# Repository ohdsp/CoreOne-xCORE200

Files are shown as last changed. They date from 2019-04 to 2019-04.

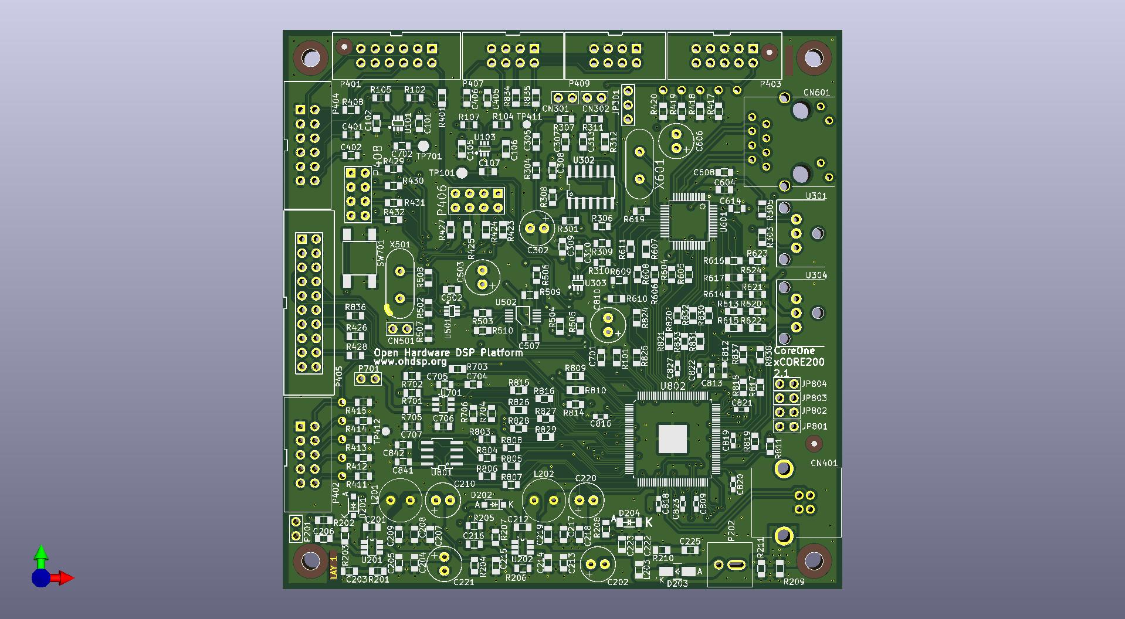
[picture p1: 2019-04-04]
JPEGs/CoreOne-xCORE200-2.1-top.jpg

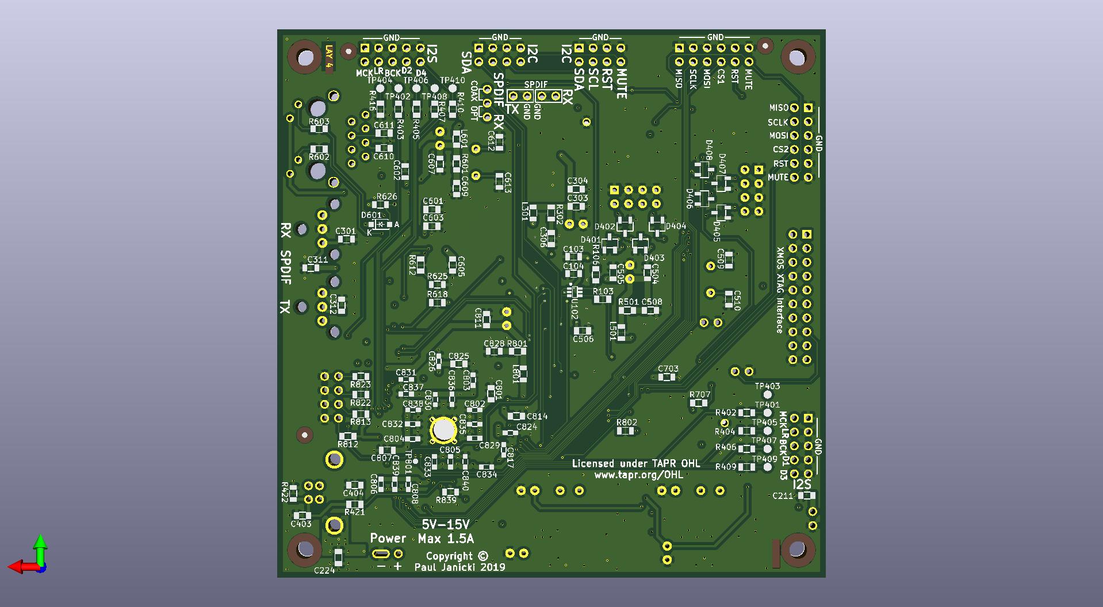
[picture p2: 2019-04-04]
JPEGs/CoreOne-xCORE200-2.1-bottom.jpg

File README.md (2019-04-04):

# [Open Hardware DSP Platform](http://www.ohdsp.org)
## CoreOne-xCORE200
### Revision 2.1

---
# README
### Disclaimer
Copyright Paul Janicki 2019

Licensed under the TAPR Open Hardware License (www.tapr.org/OHL)

This documentation is distributed WITHOUT ANY EXPRESS OR IMPLIED WARRANTY, INCLUDING OF MERCHANTABILITY, SATISFACTORY QUALITY AND FITNESS FOR A PARTICULAR PURPOSE.

### What is this repository?

**Quick summary**

This is Open Hardware DSP Platform CoreOne-xCORE200 Module Revision 2.0. 

This is a less cramped XMOS 200 based DSP and mirocontroller PCB design with USB, SPDIF, I2S/TDM, SPI, I2C, and Ethernet connectivity options.

This repository contains the KiCad design files, manufacturing Gerber/drill files, PDF/drawing files, and relevant documenation for this board.

**Changelog**
Revision 2.1 has the following changes over Revision 2.0:
Added better grounding on power connector only, added extra vias.

Revision 2.0 has the following changes over Revision 1.0:
The ST1S40 regualtors have been replaced with RT7285C parts
The CS2100 clock generator has been removed
The TPS3808 reset circut has been replaced with an NCP308 part
There are now components on the bottom layer to reduce cramping
Third I2S connector removed
Added second I2C and second SPI connectors

### What is the project folder structure?
Most folder names are self explanatory. Starting from the top level: \
*CoreOne*
+ *Bill of Materials*  - This contains the bill of materials in CVS, LibreOffice Calc and XML formats
+ *Drawings* - This contains PDF and SVG Schematic and PCB files
+ *Gerbers* - This contains the PCB Gerbers and drill drawings for manufacture, there is also a zip file ready to send to most manufacturers
+ *JPEGs* - JPEGs of top and bottom views from 3D viewer
+ *KiCad* - This contains the original KiCad schematic and PCB design files
+ *Pick and Place* - This contains pick and place files for top and bottom sides
### How do I get set up?

**Summary of set up**

1. Set your self up a directory on a local disk, something simple will make life easier (eg C:\Electronics on Windows as used here), but anywhere will do just fine.
2. Download the Kicad-Libs from [https://github.com/ohdsp/KiCad-Libs](https://github.com/ohdsp/KiCad-Libs) and place in C:\Electronics\Kicad-Libs (or your chosen folder) 
3. Create a OHDSP subdirectory in C:\Electronics (so C:\Electronics\OHDSP)
3. Download this project to C:\Electronics\OHDSP\uDSP
4. Fire up Kicad
5. Open the main project file C:\Electronics\OHDSP\uDSP\KiCad\uDSP.pro
7. Do as you wish with the project, just keep it under the TAPR Open Hardware License.
Note: For library issues see below.

Make sure your git setup doesn't exclude files used in the project (like .LIB files) or things may go wrong down the line.

**KiCad Library Configuration**

Note that libraries are setup using relative paths, if you follow the above instructions things should work just fine. Below is the default library setup.

To setup eeschema component libraries:
From KiCad main window go to menu Tools -> Edit Schematic Symbols. In the new Window go to menu Preferences -> Manage Symbol Libraries.

On the new "Symbol Libraries" window select the "Project Specific Libraries" tab. The "Append Library" and "Remove Library" buttons can be used to add/remove enteries.
The standard setup is:

| | Active | Nickname | Library Path | Plugin Type | Options | Description |
|---|---|---|---|---|---|---|
| 1 | Ticked | power | ${KICAD_SYMBOL_DIR}/power.lib | Legacy | (blank) | (blank) |
| 2 | Ticked | MyKiCadLibs-Lib | ${KIPRJMOD}/../../../KiCad-Libs/MyKiCadLibs-Lib.lib | Legacy | (blank) | (blank) |

${KICAD_SYMBOL_DIR}  is set under the Enviromnet Variable Configuration. Close Symbol Libraries dialogue and go "Preferences" -> "Configure Paths..."

${KICAD_SYMBOL_DIR} is set to C:\Program Files\KiCad\share\kicad\library - this is the default for a KiCad install on the C drive

${KIPRJMOD} is automatically set to the location of the project (.pro file), in this example this would be C:\Electronics\OHDSP\uDSP\KiCad

To setup Pcbnew libraries:
From KiCad main window go to menu Tools -> Edit PCB Footprints. In the new Window go to menu Preferences -> Manage Symbol Libraries.

On the new "Symbol Libraries" window select the "Project Specific Libraries" tab. The "Append Library" and "Remove Library" buttons can be used to add/remove enteries.
The standard setup is:

| | Active | Nickname | Library Path | Plugin Type | Options | Description |
|---|---|---|---|---|---|---|
| 1 | Ticked | MyKiCadLibs-Footprints | ${KIPRJMOD}/../../../KiCad-Libs/MyKiCadLibs-Footprints.pretty | KiCad | (blank) | (blank) |

${KIPRJMOD} is automatically set to the location of the project (.pro file), in this example this would be C:\Electronics\OHDSP\uDSP\KiCad

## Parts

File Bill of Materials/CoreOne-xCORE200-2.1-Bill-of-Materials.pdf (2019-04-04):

CoreOne-xCORE200-2.1-Bill-of-Materials

Licensed under the TAPR Open Hardware License (www.tapr.org/OHL)

### CoreOne-xCORE200-2.1 Bill of Materials 04 April 2019

Reference | Quantity | Footprint | Value | Description | Size | Tolerance | Type | Voltage | Power | Current
C101 C103 C105 C307 C309 C311 C506 C614 C703 C842 | 10 SMD-0805 | | 10u | 'Ceramic capacitor | '0805 | '20% | 'X5R | '10V | ' | '
C102 C104 C106 C201 C203 C205 C209 C211 C212 C214 C219 C223 C224 C301 C304 C305 C308 C310 C312 C313 C404 C502 C505 C507 C603 C604 C605 C608 C610 C611 C704 C841 | 32 SMD-0805 | | 100n | 'Ceramic capacitor | '0805 | '10% | 'X7R | '50V | ' | '
C107 C215 C401 C402 C405 C406 C701 C702 C705 C706 C707 | 11 SMD-0805 | | 10n | 'Ceramic capacitor | '0805 | '10% | 'X7R | '50V | ' | '
C202 C221 | 2 CAP-TH-D6.3mmP2.5mm | | 220u | 'Aluminium electrolytic capacitor | ' | ' | '2.5mm pitch, 6.3mm diameter | '16V | ' | '
C206 | 1 SMD-0805 | | 39p | 'Ceramic capacitor | '0805 | '10% | 'X7R | '50V | ' | '
C207 C208 C217 C218 C303 C504 C607 C801 C807 C811 C814 C825 | 12 SMD-0805 | | 22u | 'Ceramic capacitor | '0805 | '20% | 'X5R | '10V | ' | '
C210 C220 C302 C503 C606 C810 | 6 CAP-TH-D6.3mmP2.5mm | | 220u | 'Low impedance aluminium electrolytic capacitor - Panasonic FC, FR or similar | ' | ' | '2.5mm pitch, 6.3mm diameter | '10V | ' | '
C216 | 1 SMD-0805 | | N/F | 'Ceramic capacitor | '0805 | '10% | 'X7R | '50V | ' | '
C204 C213 C222 | 3 SMD-0805 | | 22u | 'Ceramic capacitor | '0805 | '20% | 'X5R | '25V | ' | '
C225 C306 C508 C609 C828 | 5 SMD-0805 | | 100p | 'Ceramic capacitor | '0805 | '5% | 'C0G | '50V | ' | '
C403 | 1 SMD-0805 | | 2u2 | 'Ceramic capacitor | '0805 | '10% | 'X5R | '50V | ' | '
C509 C510 C612 C613 | 4 SMD-0805 | | 33p | 'Ceramic capacitor | '0805 | '5% | 'NP0 | '50V | ' | '
C601 C602 | 2 SMD-0805 | | 1u | 'Ceramic capacitor | '0805 | '10% | 'X7R | '10V | ' | '
C802 C803 C804 C805 C806 | 5 SMD-0603 | | 1u | 'Ceramic capacitor | '0603 | '10% | 'X7R | '10V | ' | '
C808 C812 C816 C817 C818 C819 C820 C821 C822 C823 C824 C826 C829 C830 C831 C832 C833 C834 | 18 SMD-0603 | | 100n | 'Ceramic capacitor | '0603 | '10% | 'X7R | '50V | ' | '
C809 C813 C827 C835 C836 C837 C838 C839 C840 | 9 SMD-0603 | | 10n | 'Ceramic capacitor | '0603 | '10% | 'X7R | '50V | ' | '
CN301 CN302 CN501 | 3 CONN_SIL_2_1MM | | COAX | '1x2 2.54mm pitch pin header - use with 75Ohm coax | ' | ' | ' | ' | ' | '
CN401 | 1 CONN-USB-B-61729-0010 | | CONN-USB-B-61729'USB B Connector - Amphenol 61729 Series - eg: 61729-0010 | | ' | ' | ' | ' | ' | '
CN601 | 1 CONN-RJ45-ARJC02-111xxxx | | ARJC02-111009D | 'ARCJ02 series RJ45 connector with LED - ARJC02-111009D | ' | ' | ' | ' | ' | '
D201 D202 D601 | 3 DIODE-SOD-123 | | 1N4148W-7-F | 'Text description | ' | ' | ' | ' | ' | '
D203 | 1 DIODE-SMA | | B240A | 'B240A 2A 40V Schottky Rectifier - SMA (DO-214AC) | ' | ' | ' | ' | ' | '
D204 | 1 SMD-1206 | | Green LED 1206 | 'Green LED - SMD - Vf 1.8V to 2.2V | '1206 | ' | ' | ' | ' | '
D401 D402 D403 D404 D405 D406 D407 D408 | 8 IC-SOT23 | | BAV99 | '100V 150mA Small Signal Switching Diode, Dual in Series | ' | ' | ' | ' | ' | '
JP301 | 1 CONN_SIL_3_1MM | | CONN_3x1 | '1x3 2.54mm pitch pin header | ' | ' | ' | ' | ' | '
L201 | 1 IND-TH-DR0608 | | DR0608-153L | 'Coilcraft DR0608-153L DCR=0.052Ohm Isat=2.7A Irms=2.7A | ' | ' | ' | ' | ' | '2.7A
L202 | 1 IND-TH-DR0608 | | DR0608-332L | 'Coilcraft DR0608-332L DCR=0.012Ohm Isat=5.3A Irms=5.0A | ' | ' | ' | ' | ' | '5.3A
L203 | 1 SMD-0805 | | 600R@100MHz | 'Ferrite bead, current rating 2A or higher, 600R@100MHz | '0805 | ' | ' | ' | ' | '=>2A
L301 L501 L601 L801 | 4 SMD-0805 | | 600R@100MHz | 'Ferrite bead, current rating 1A or higher, 600R@100MHz | '0805 | ' | ' | ' | ' | '=>1A
JP801 JP802 JP803 JP804 P201 P701 | 6 CONN_SIL_2_1MM | | CONN_2x1 | '1x2 2.54mm pitch pin header | ' | ' | ' | ' | ' | '
P202 | 1 CONN-2WAY-2.54mm-3.81mm-SPACING | | CONN_2x1 | '2 way screw terminal, any 2.54mm to 3.81mm pitch part | ' | ' | ' | ' | ' | '
P401 P404 | 2 CONN_DIL_2X6_BOX_1MM | | CONN_02X06 | '2x6 2.54mm pitch box header | ' | ' | ' | ' | ' | '
P402 P403 | 2 CONN_DIL_2X5_BOX_1MM | | CONN_02X05 | '2x5 2.54mm pitch box header | ' | ' | ' | ' | ' | '
P405 | 1 CONN_DIL_2X10_BOX_1MM | | CONN_02X10 | '2x10 2.54mm pitch box header | ' | ' | ' | ' | ' | '
P406 P408 | 2 CONN_DIL_2X04 | | CONN_02X04 | '2x4 2.54mm pitch pin header | ' | ' | ' | ' | ' | '
P407 P409 | 2 CONN_DIL_2X4_BOX_1MM | | CONN_02X04 | '2x4 2.54mm pitch box header | ' | ' | ' | ' | ' | '
R101 R401 R402 R403 R404 R405 R406 R407 R408 R409 R410 R426 R428 R803 R804 R805 R806 R807 R808 R809 R810 R814 R817 R818 R824 R825 | 26 SMD-0805 | | 0 | 'Thick or thin film resistor | '0805 | '1% | ' | ' | '100mW | '
R102 R103 R104 R105 R106 R107 R604 R605 R606 R607 R608 R611 R612 R811 R815 R816 R819 R820 R821 R826 R827 R828 R829 R830 R831 R832 R833 R836 | 28 SMD-0805 | | 33 | 'Thick or thin film resistor | '0805 | '1% | ' | ' | '100mW | '
R201 R202 R206 | 3 SMD-0805 | | 100k | 'Thick or thin film resistor | '0805 | '1% | ' | ' | '100mW | '
R203 | 1 SMD-0805 | | 22k | 'Thick or thin film resistor | '0805 | '1% | ' | ' | '100mW | '
R204 | 1 SMD-0805 | | 75k | 'Thick or thin film resistor | '0805 | '1% | ' | ' | '100mW | '
R205 R301 R303 R308 R421 R626 R802 | 7 SMD-0805 | | 10k | 'Thick or thin film resistor | '0805 | '1% | ' | ' | '100mW | '
R207 R704 | 2 SMD-0805 | | 15k | 'Thick or thin film resistor | '0805 | '1% | ' | ' | '100mW | '
R208 R602 R603 | 3 SMD-0805 | | 220 | 'Thick or thin film resistor | '0805 | '1% | ' | ' | '100mW | '
R209 R211 | 2 SMD-0805 | | 10 | 'Thick or thin film resistor | '0805 | '1% | ' | ' | '100mW | '
R210 R302 R501 R601 R801 | 5 SMD-0805 | | 47 | 'Thick or thin film resistor | '0805 | '1% | ' | ' | '100mW | '
R304 R702 R703 R705 | 4 SMD-0805 | | 100 | 'Thick or thin film resistor | '0805 | '1% | ' | ' | '100mW | '
R305 R306 R307 R309 R310 | 5 SMD-0805 | | 75 | 'Thick or thin film resistor | '0805 | '1% | ' | ' | '100mW | '
R311 | 1 SMD-0805 | | 360 | 'Thick or thin film resistor | '0805 | '1% | ' | ' | '100mW | '
R312 | 1 SMD-0805 | | 91 | 'Thick or thin film resistor | '0805 | '1% | ' | ' | '100mW | '
R411 R412 R413 R414 R415 R416 R417 R418 R419 R420 R502 R506 R507 R613 R614 R615 R623 R624 R625 R834 R835 | 21 SMD-0805 | | N/F | 'Thick or thin film resistor | '0805 | '1% | ' | ' | '100mW | '
R422 | 1 SMD-0805 | | 47k | 'Thick or thin film resistor | '0805 | '1% | ' | ' | '100mW | '
R423 R424 R425 R427 R429 R430 R431 R432 R510 R609 R610 R618 R620 R621 R622 R812 R813 R822 R823 | 19 SMD-0805 | | 1k | 'Thick or thin film resistor | '0805 | '1% | ' | ' | '100mW | '
R503 R504 R505 | 3 SMD-0805 | | 33R | 'Thick or thin film resistor | '0805 | '1% | ' | ' | '100mW | '
R508 | 1 SMD-0805 | | 1Meg | 'Thick or thin film resistor | '0805 | '1% | ' | ' | '100mW | '
R509 | 1 SMD-0805 | | 0R | 'Thick or thin film resistor | '0805 | '1% | ' | ' | '100mW | '
R616 R617 | 2 SMD-0805 | | 4k7 | 'Thick or thin film resistor | '0805 | '1% | ' | ' | '100mW | '
R619 | 1 SMD-0805 | | 6K49 | 'Thick or thin film resistor | '0805 | '1% | ' | ' | '100mW | '
R701 R707 R837 R838 | 4 SMD-0805 | | 2k2 | 'Thick or thin film resistor | '0805 | '1% | ' | ' | '100mW | '
R706 | 1 SMD-0805 | | 10k7 | 'Thick or thin film resistor | '0805 | '1% | ' | ' | '100mW | '
R839 | 1 SMD-0805 | | 43R2 | 'Thick or thin film resistor | '0805 | '1% | ' | ' | '100mW | '
SW701 | 1 SW_TACT_SMD | | SWITCH | '6mm x 6mm SMD tactile switch - e.g. TE FSM2JSMA | ' | ' | ' | ' | ' | '
U101 U102 U103 | 3 IC-SC70-6 | | NC7WZ16P6X | 'NC7WZ16P6X TinyLogic UHS Dual Buffer | ' | ' | ' | ' | ' | '
U201 U202 | 2 IC-SOT23-6 | | RT7285C | 'Richtek RT7285C 1.5A 18V Step Down Converter | ' | ' | ' | ' | ' | '
U301 | 1 IC_SPDIF_OPTO | | IC-SPDIF-RX-OPTO 'TOSLINK receiver e.g. CLIFF FC684205R | | ' | ' | ' | ' | ' | '
U302 | 1 IC_SOIC_14 | | 74HC04 | '74HC04 Hex Inverter - SOIC-14 | ' | ' | ' | ' | ' | '
U303 | 1 IC-SC70-6 | | NC7WZ16P6X | 'NC7WZ16P6X TinyLogic UHS Dual Buffer | ' | ' | ' | ' | ' | '
U304 | 1 IC_SPDIF_OPTO | | IC-SPDIF-TX-OPTO | 'TOSLINK transmitter e.g. CLIFF FC684205T | ' | ' | ' | ' | ' | '
U501 | 1 IC-SC70-6 | | NC7WZ04P6X | 'NC7WZ04 TinyLogic UHS Dual Inverter | ' | ' | ' | ' | ' | '
U502 | 1 IC-MSOP-10 | | CS2200-CP | 'Cirrus Logic CS2200-CP Fractional-N Frequency Synthesizer | ' | ' | ' | ' | ' | '
U601 | 1 IC-LQFP48_7x7 | | KSZ8081MLX | 'Microchip KSZ8081MLXCA LQFP-48 10Base-T/100Base-TX Ethernet PHY | ' | ' | ' | ' | ' | '
U701 | 1 IC-SOT23-6 | | NCP308 | 'On Semi NCP308 SOT-23-6 TSOP-6 Supervisor | ' | ' | ' | ' | ' | '
U801 | 1 IC_SOIC_8 | | IC-FLASH-SPI | 'SPI/Quad SPI Flash Memory - SOIC 8 - For use with XE-216-TQ128, XEF216-512-TQ128 has internal flash | ' | ' | ' | ' | ' | '
U802 | 1 IC-TQ128-XMOS-HF | | XE216-512-TQ128 | 'XMOS 200 XE216-512-TQ128 Microcontroller | ' | ' | ' | ' | ' | '
X501 | 1 XTAL_HC49_TH | | 24M000 | 'HC49 24.000MHz Crystal 30ppm or better 18pF | ' | ' | ' | ' | ' | '
X601 | 1 XTAL_HC49_TH | | 25M000 | 'HC49 25.000MHz Crystal 50ppm or better 18pF | ' | ' | ' | ' | ' | '

### Open Hardware DSP Platform – www.ohdsp.org

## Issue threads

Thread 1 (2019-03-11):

MyKiCadLibs-Lib.lib missing?

stapelberg, 2019-03-11:
Hey,

thanks for sharing this project! I am planning an xCORE200-based project, too, so I wanted to see how you did things, but when opening the schematic in Kicad, I get the error message “The following libraries were not found: MyKiCadLibs-Lib.lib”.

ohdsp, 2019-03-11:
Depends on the KiCad version you are using. This project was created in KiCad 4, but will work in KiCad 5 fine. The readme.md file in this repository has instructions for setting up libraries in KiCad 4 versions. You do also need to download the Kicad-Lib libraries from here:
https://github.com/ohdsp/KiCad-Libs

If you follow the directory structure in readme.md it works fine (on windows machines at least).

If you are using KiCad 5 generally the same instructions apply. There is a new project - uDSP - this had a readme.md file with instructions for KiCad 5 setups:
https://github.com/ohdsp/uDSP/blob/master/README.md

This should apply to all projects new and old. If you open this project in KiCad 5 it will ask to remap symbols, just click the remap button. I just tried a fresh checkout of this project and the Kicad-Libs, following the directory structure in the readme.md file. When I opened the schematic and KiCad 5 asked to remap I clicked "Remap Symbols" button. It picked up the old library fine and worked as expected.

Regards

Paul

stapelberg, 2019-03-11:
Thanks for the quick and detailed reply!

Indeed, after cloning KiCad-Libs and following the recommended directory structure, I can open your project just fine. I should have read the README more carefully :)

Closed 2019-03-11.

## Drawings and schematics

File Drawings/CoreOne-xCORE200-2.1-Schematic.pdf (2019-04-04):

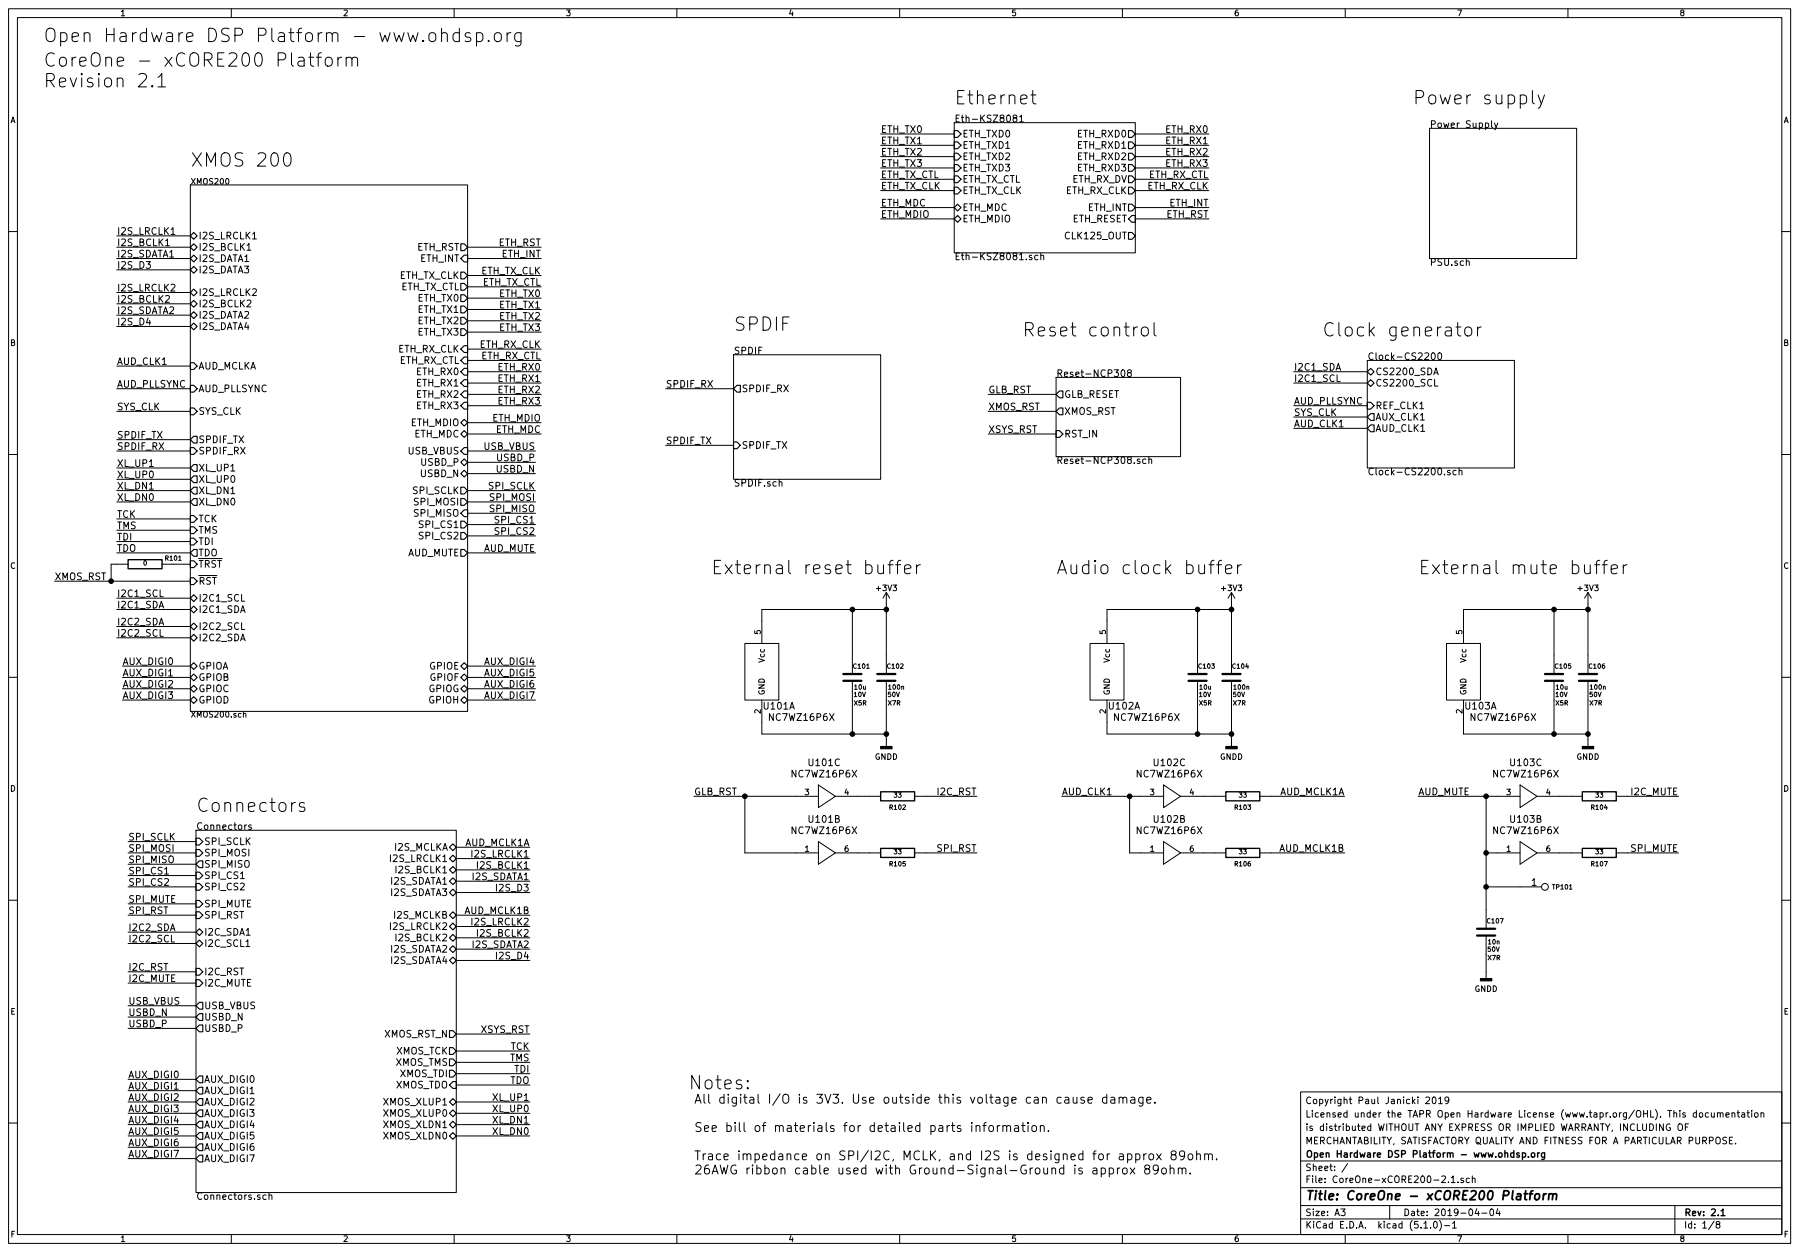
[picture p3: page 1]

Open Hardware DSP Platform - www.ohdsp.org
CoreOne - xCORE200 Platform
Revision 2.1

ETH_TX1 | ETH_RX1
ETH_TX2 | ETH_RX2
ETH_TX3 | ETH_RX3
ETH_TX_CTL | | ETH_RX_CTL
ETH_TX_CLK | | ETH_RX_CLK

I2S_BCLK1
I2S_SDATA1

I2S_BCLK2
I2S_SDATA2

XL_UP1 XL_UP0 TDI TDO

X7R +3V3 GNDD External mute buffer

Notes:
All digital I/O is 3V3. Use outside this voltage can cause damage.
See bill of materials for detailed parts information.
Trace impedance on SPI/I2C, MCLK, and I2S is designed for approx 89ohm.
26AWG ribbon cable used with Ground-Signal-Ground is approx 89ohm.

Copyright Paul Janicki 2019
Licensed under the TAPR Open Hardware License (www.tapr.org/OHL). This documentation
is distributed WITHOUT ANY EXPRESS OR IMPLIED WARRANTY, INCLUDING OF
MERCHANTABILITY, SATISFACTORY QUALITY AND FITNESS FOR A PARTICULAR PURPOSE.
File: CoreOne-xCORE200-2.1.sch Sheet: / Open Hardware DSP Platform - www.ohdsp.org

Id: 1/8 Title: CoreOne - xCORE200 Platform

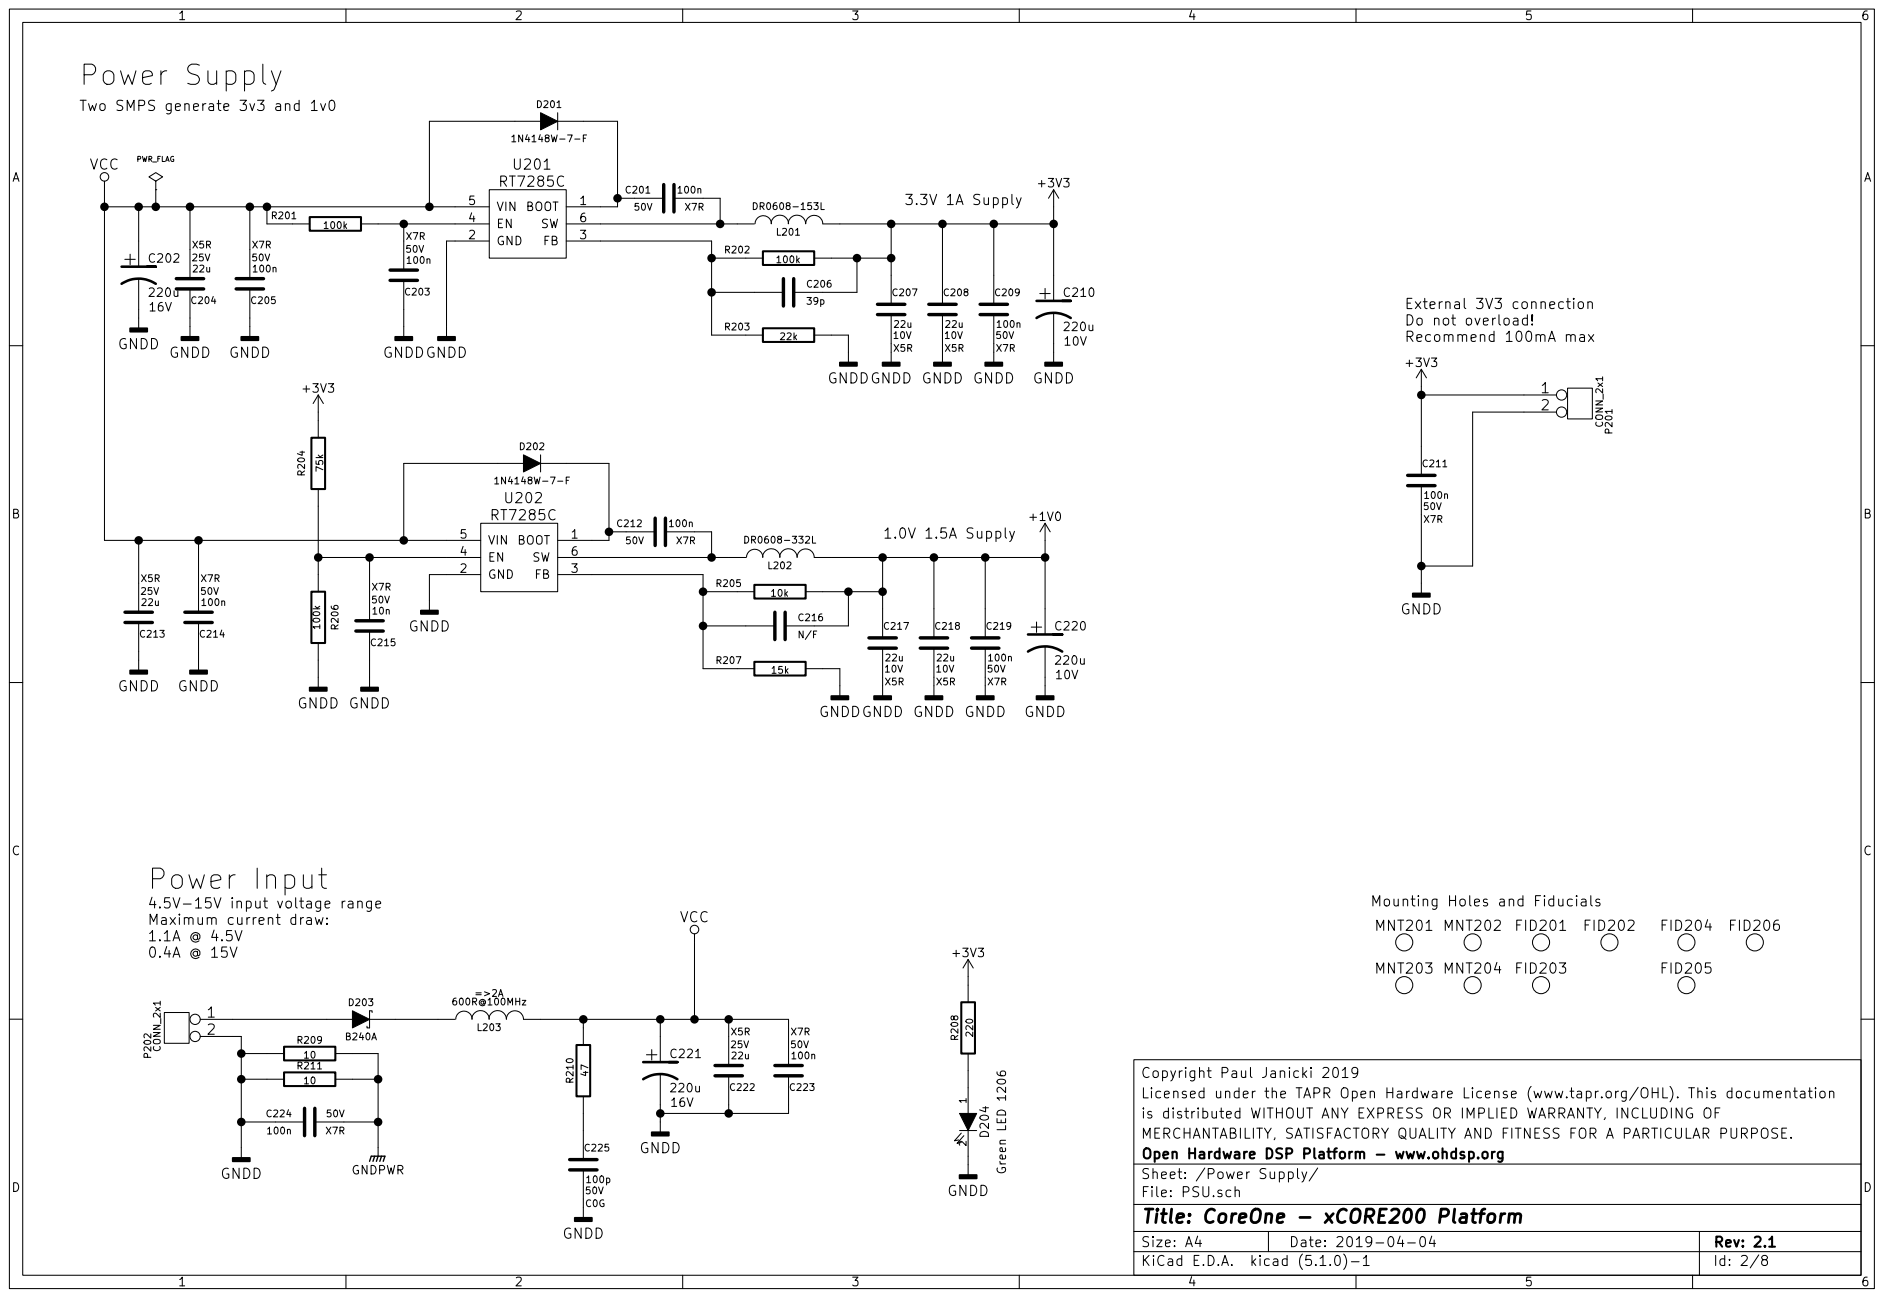
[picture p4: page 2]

4.5V-15V input voltage range Maximum current draw: 1.1A @ 4.5V

Copyright Paul Janicki 2019
Licensed under the TAPR Open Hardware License (www.tapr.org/OHL). This documentation
is distributed WITHOUT ANY EXPRESS OR IMPLIED WARRANTY, INCLUDING OF
MERCHANTABILITY, SATISFACTORY QUALITY AND FITNESS FOR A PARTICULAR PURPOSE.
Open Hardware DSP Platform - www.ohdsp.org
File: PSU.sch Sheet: /Power Supply/
Id: 2/8 Title: CoreOne - xCORE200 Platform

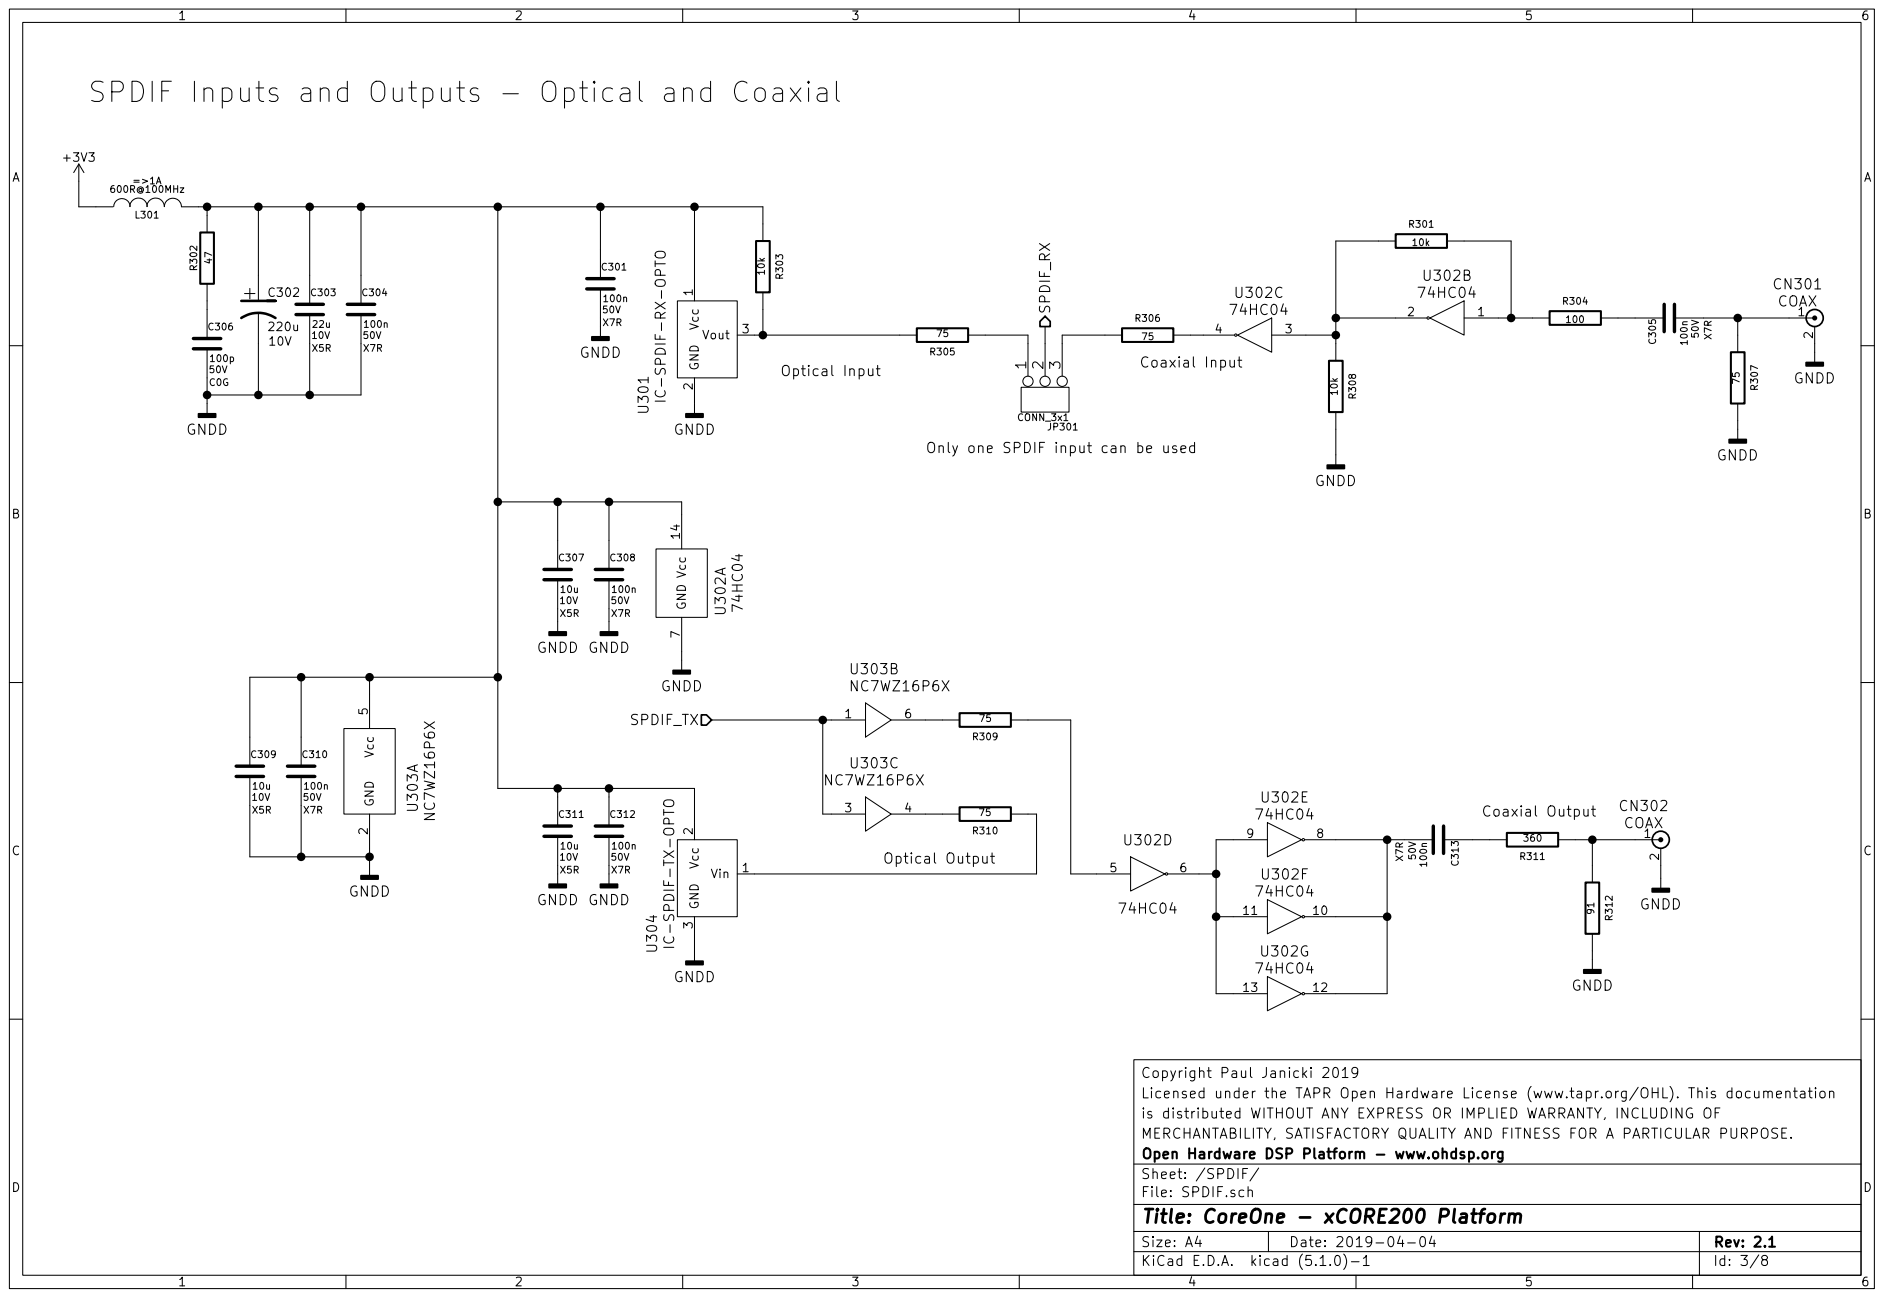
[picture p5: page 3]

SPDIF Inputs and Outputs - Optical and Coaxial Vcc 1 GND

2 Vout 3 U301IC-SPDIF-RX-OPTO

3 U304 IC-SPDIF-TX-OPTO

Copyright Paul Janicki 2019
Licensed under the TAPR Open Hardware License (www.tapr.org/OHL). This documentation
is distributed WITHOUT ANY EXPRESS OR IMPLIED WARRANTY, INCLUDING OF
MERCHANTABILITY, SATISFACTORY QUALITY AND FITNESS FOR A PARTICULAR PURPOSE.
File: SPDIF.sch Sheet: /SPDIF/ Open Hardware DSP Platform - www.ohdsp.org

Id: 3/8 Title: CoreOne - xCORE200 Platform

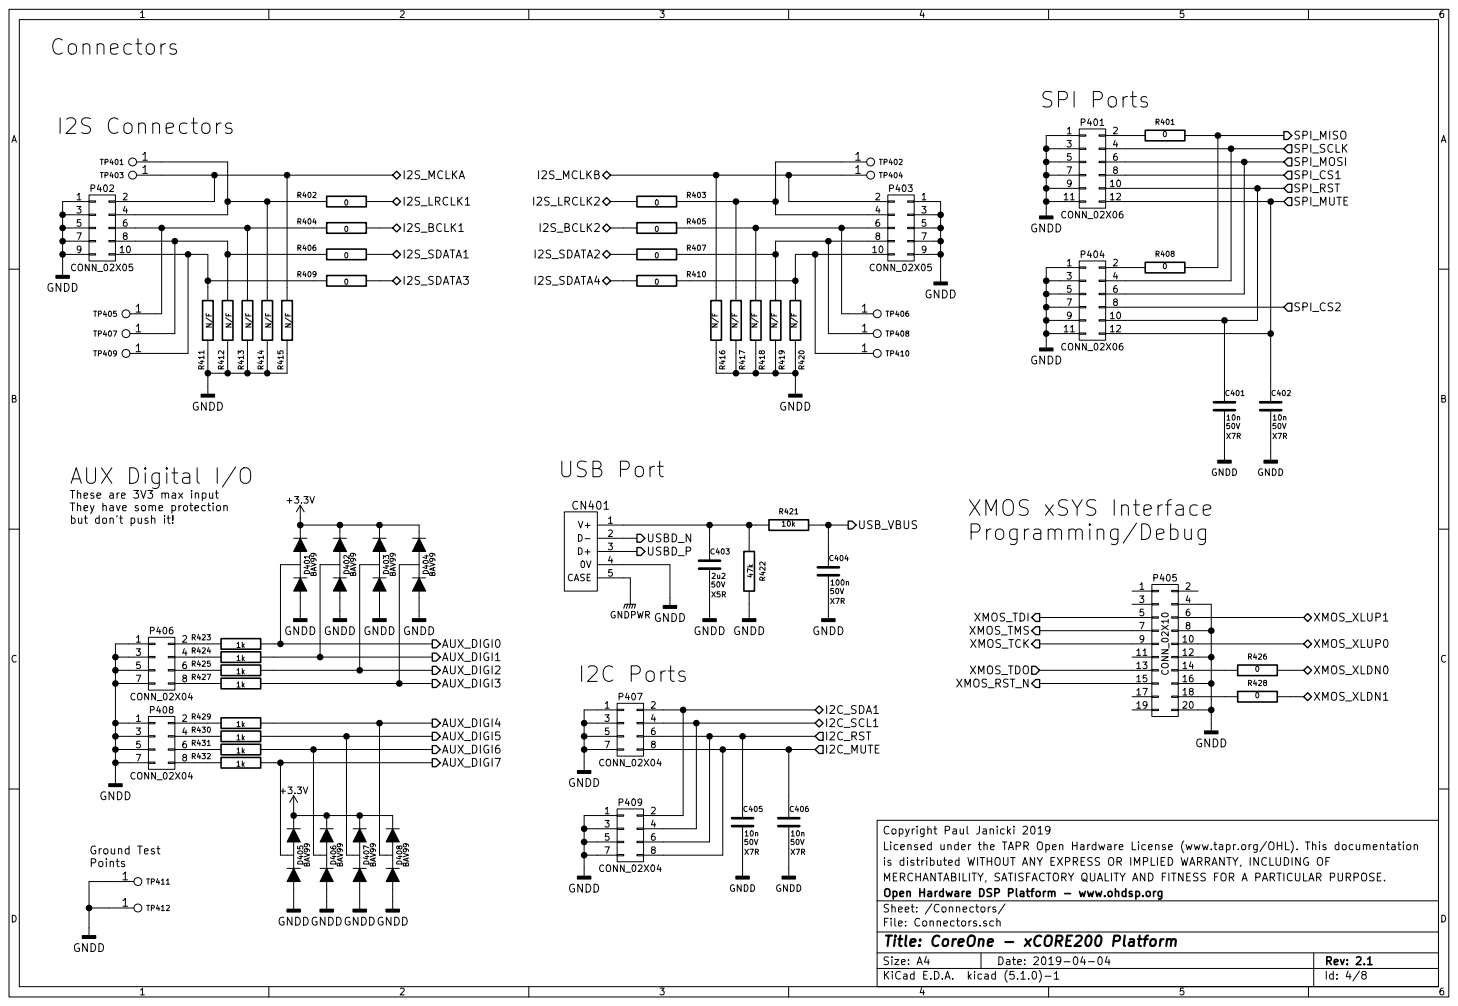
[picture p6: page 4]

These are 3V3 max input
They have some protection
but don't push it!

7 3 | 8 P406 CONN_02X04 4

Copyright Paul Janicki 2019
Licensed under the TAPR Open Hardware License (www.tapr.org/OHL). This documentation
is distributed WITHOUT ANY EXPRESS OR IMPLIED WARRANTY, INCLUDING OF
MERCHANTABILITY, SATISFACTORY QUALITY AND FITNESS FOR A PARTICULAR PURPOSE.
File: Connectors.sch Sheet: /Connectors/ Open Hardware DSP Platform - www.ohdsp.org

Id: 4/8 Title: CoreOne - xCORE200 Platform

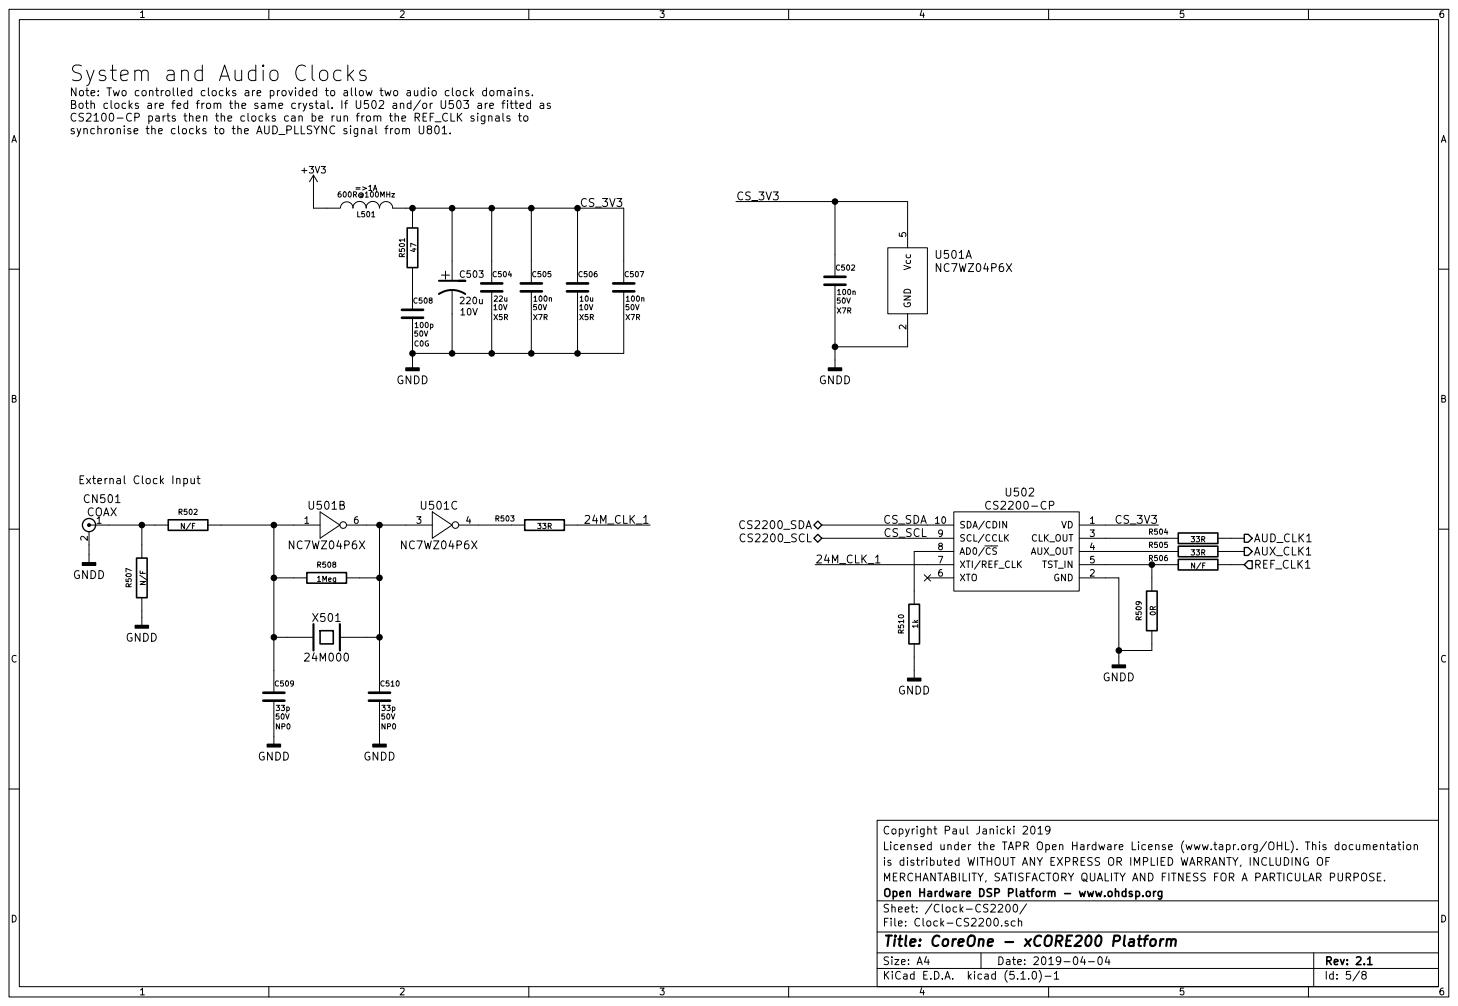
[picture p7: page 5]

System and Audio Clocks

+3V3 Note: Two controlled clocks are provided to allow two audio clock domains.
Both clocks are fed from the same crystal. If U502 and/or U503 are fitted as
CS2100-CP parts then the clocks can be run from the REF_CLK signals to

Copyright Paul Janicki 2019
Licensed under the TAPR Open Hardware License (www.tapr.org/OHL). This documentation
is distributed WITHOUT ANY EXPRESS OR IMPLIED WARRANTY, INCLUDING OF
MERCHANTABILITY, SATISFACTORY QUALITY AND FITNESS FOR A PARTICULAR PURPOSE.
File: Clock-CS2200.sch Sheet: /Clock-CS2200/ Open Hardware DSP Platform - www.ohdsp.org

Id: 5/8 Title: CoreOne - xCORE200 Platform

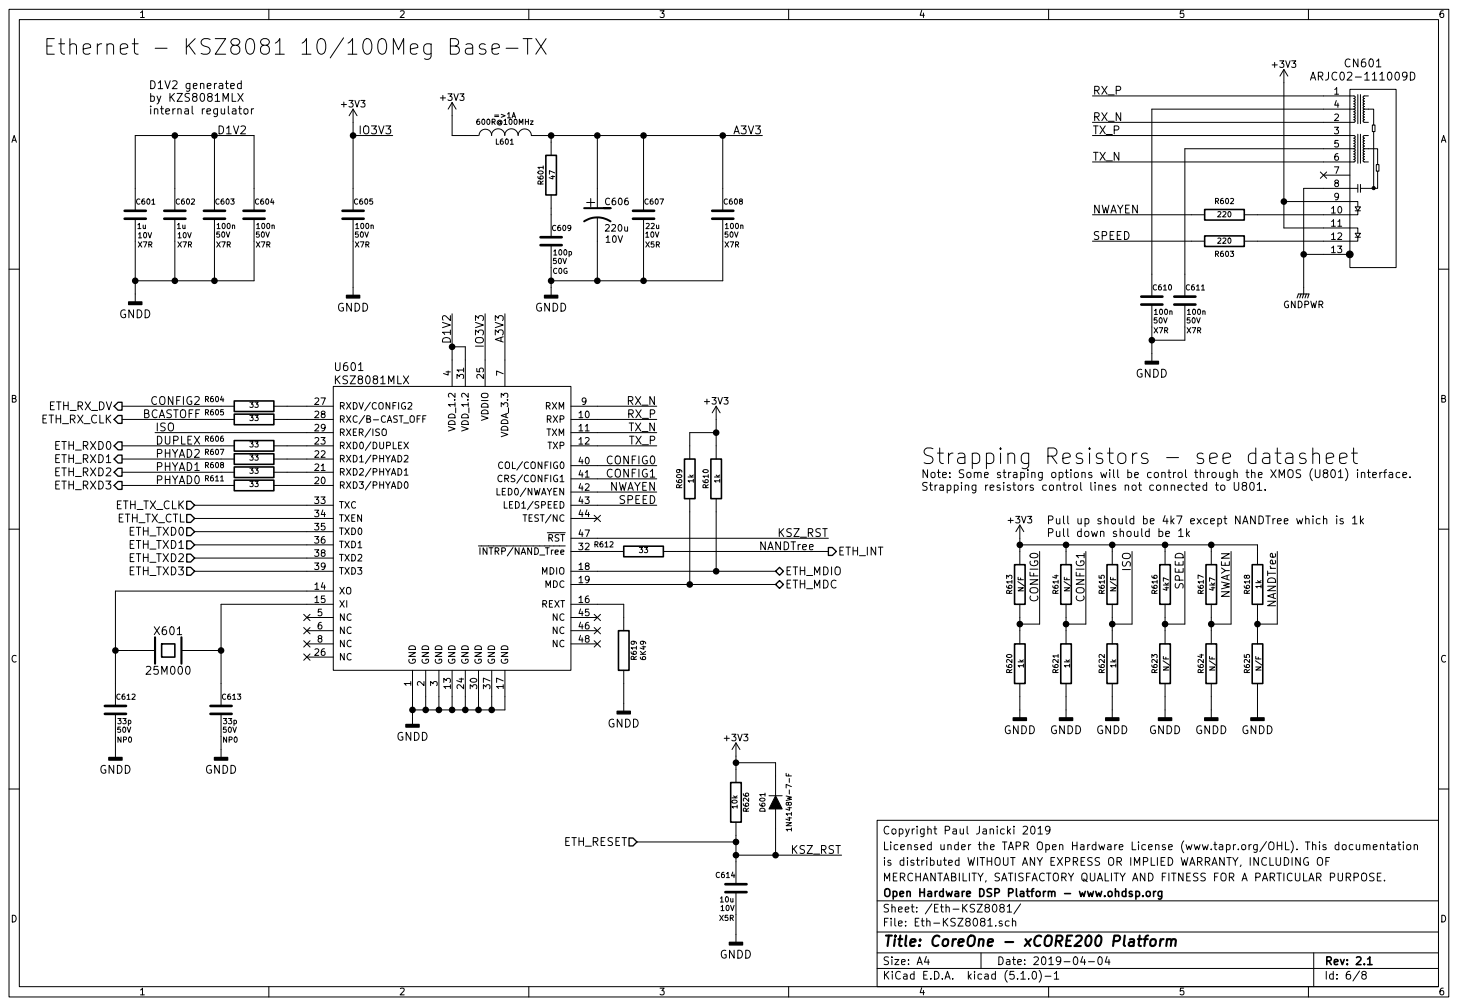
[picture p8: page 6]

2 RXD3/PHYAD0 20 RXD2/PHYAD1 21 RXD1/PHYAD2 22 RXD0/DUPLEX 23 GND 24 VDDIO 25 NC 26 RXDV/CONFIG2 27 RXC/B-CAST_OFF 28 RXER/ISO 29 GND

1 RXP 10 TXM 11 TXP 12 GND 13 XO 14 XI 15 REXT 16 GND 17 MDIO 18 MDC 19 GND

Note: Some straping options will be control through the XMOS (U801) interface.

Strapping resistors control lines not connected to U801. C614

Pull up should be 4k7 except NANDTree which is 1k Pull down should be 1k

Copyright Paul Janicki 2019
Licensed under the TAPR Open Hardware License (www.tapr.org/OHL). This documentation
is distributed WITHOUT ANY EXPRESS OR IMPLIED WARRANTY, INCLUDING OF
MERCHANTABILITY, SATISFACTORY QUALITY AND FITNESS FOR A PARTICULAR PURPOSE.
File: Eth-KSZ8081.sch Sheet: /Eth-KSZ8081/ Open Hardware DSP Platform - www.ohdsp.org

Id: 6/8 Title: CoreOne - xCORE200 Platform

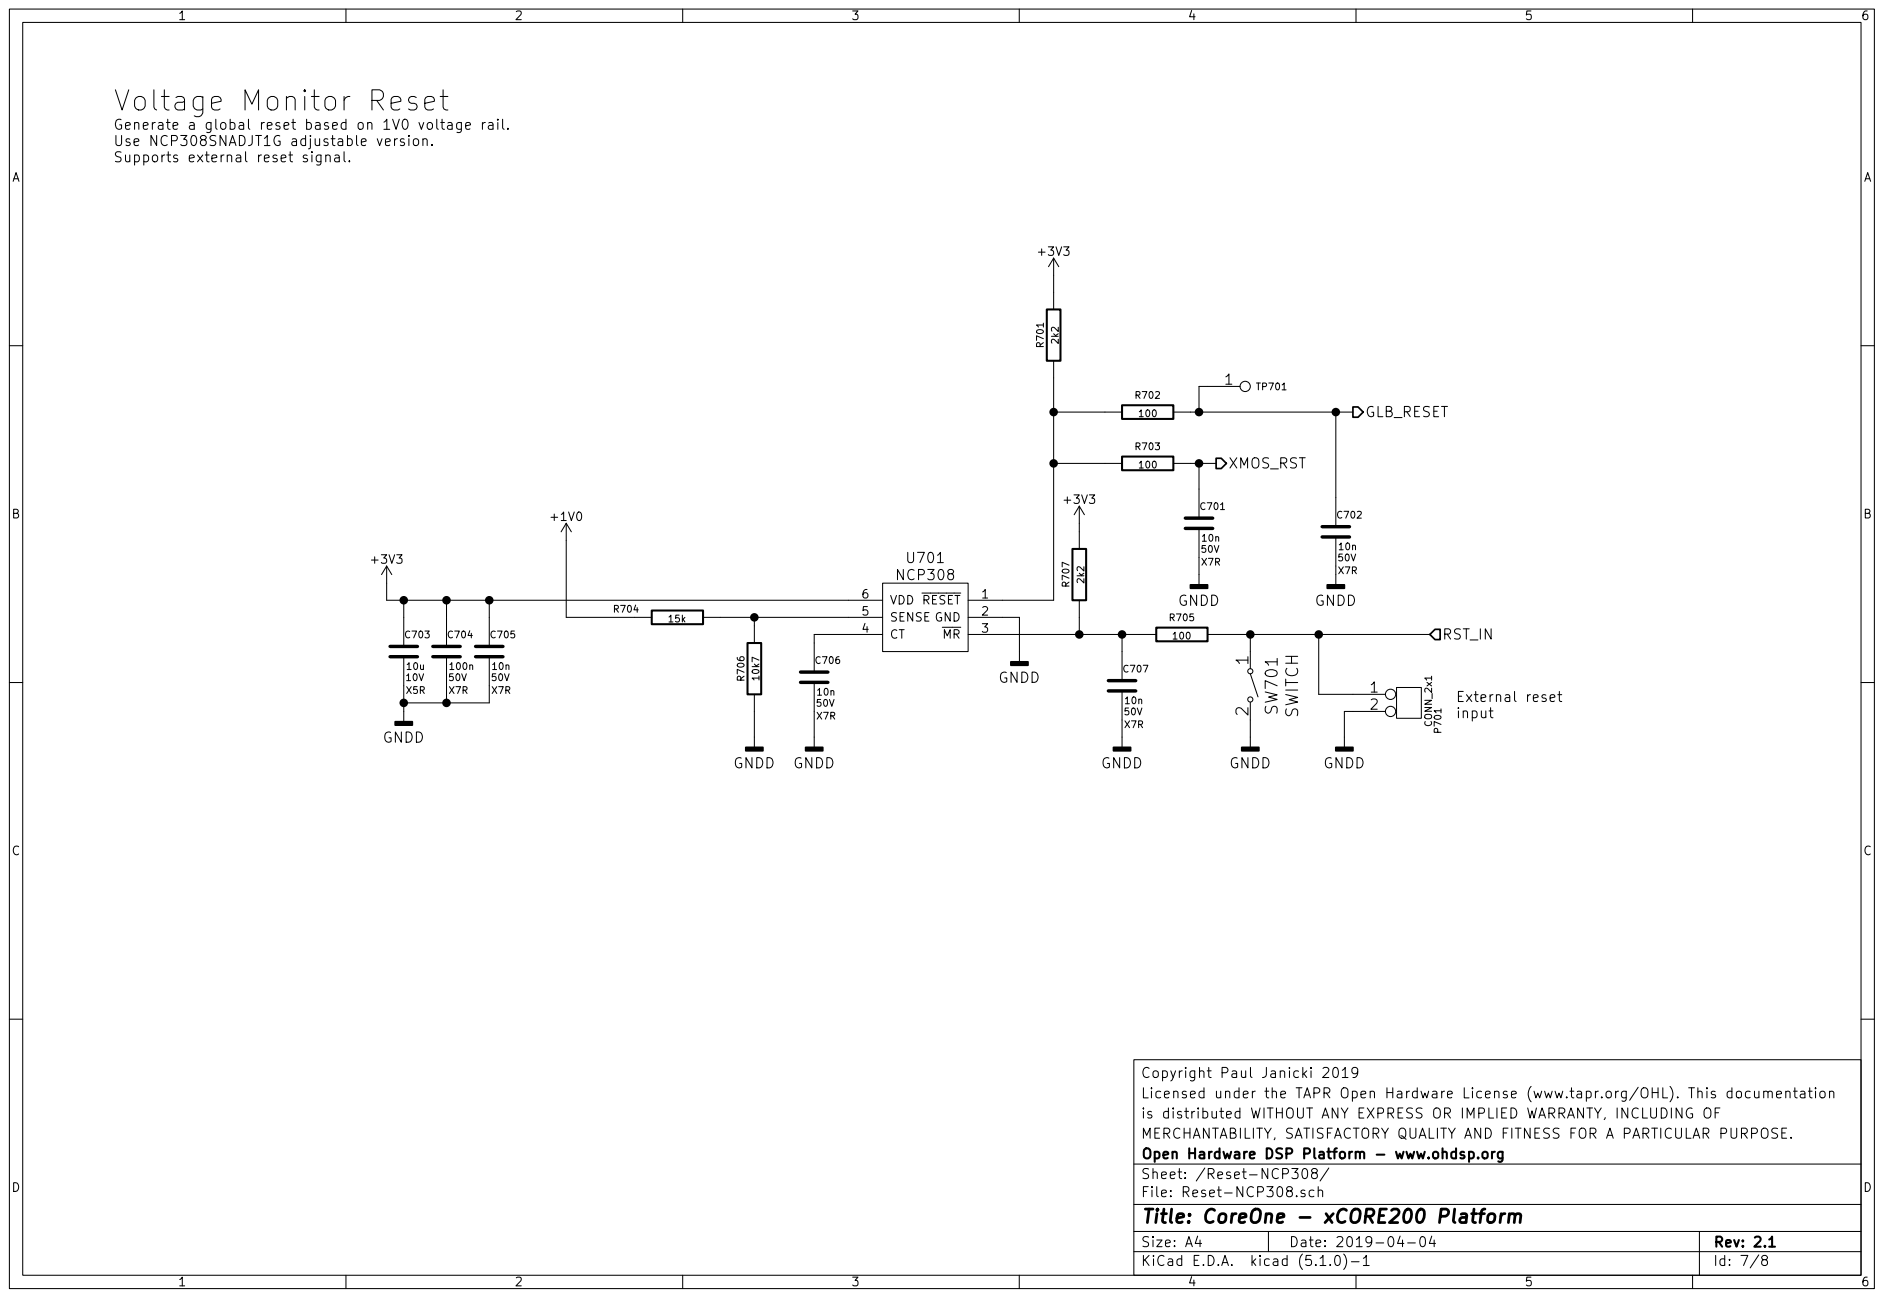
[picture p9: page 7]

Generate a global reset based on 1V0 voltage rail.
Use NCP308SNADJT1G adjustable version.
Supports external reset signal.

Copyright Paul Janicki 2019
Licensed under the TAPR Open Hardware License (www.tapr.org/OHL). This documentation
is distributed WITHOUT ANY EXPRESS OR IMPLIED WARRANTY, INCLUDING OF
MERCHANTABILITY, SATISFACTORY QUALITY AND FITNESS FOR A PARTICULAR PURPOSE.
File: Reset-NCP308.sch Sheet: /Reset-NCP308/ Open Hardware DSP Platform - www.ohdsp.org

Id: 7/8 Title: CoreOne - xCORE200 Platform
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

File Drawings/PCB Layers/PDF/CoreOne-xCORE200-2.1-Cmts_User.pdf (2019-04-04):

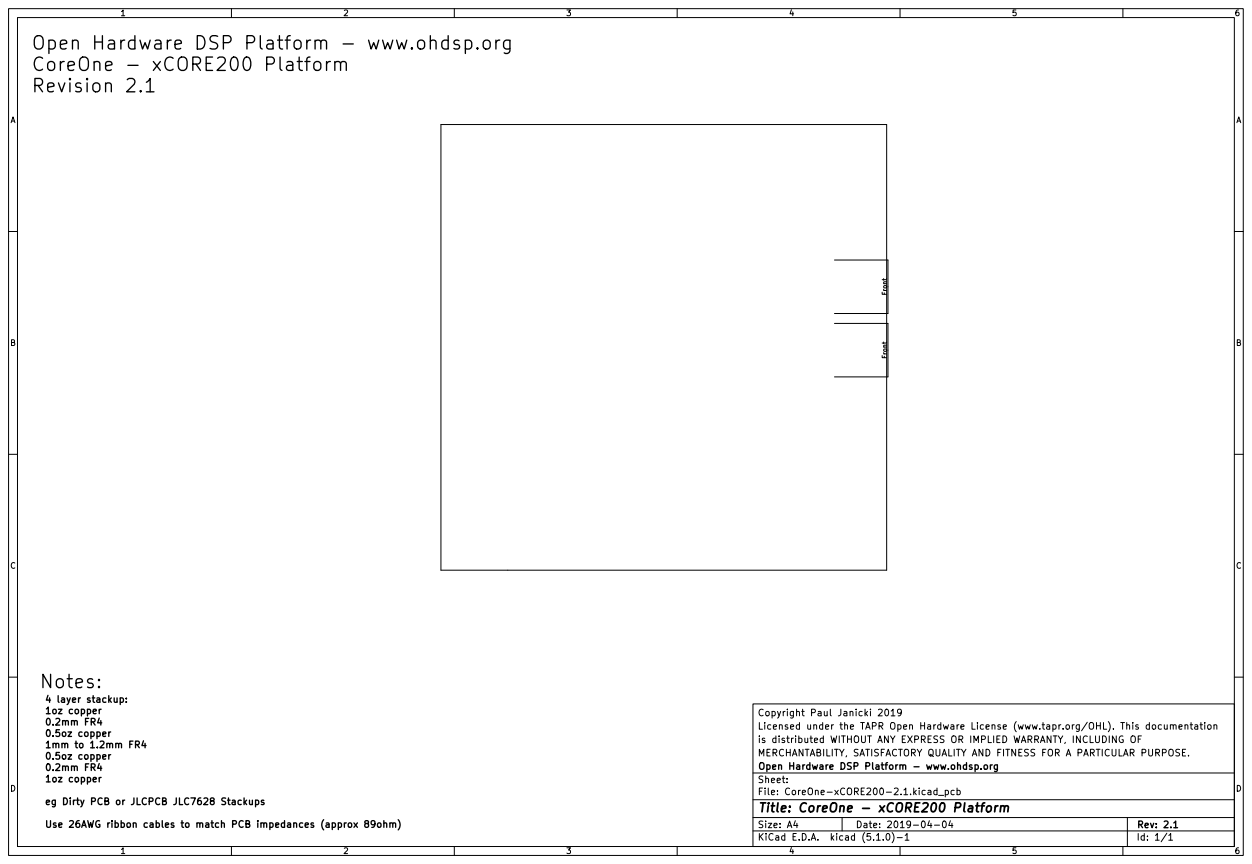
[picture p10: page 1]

Open Hardware DSP Platform - www.ohdsp.org
CoreOne - xCORE200 Platform
Revision 2.1

Copyright Paul Janicki 2019
Licensed under the TAPR Open Hardware License (www.tapr.org/OHL). This documentation
is distributed WITHOUT ANY EXPRESS OR IMPLIED WARRANTY, INCLUDING OF
MERCHANTABILITY, SATISFACTORY QUALITY AND FITNESS FOR A PARTICULAR PURPOSE.
File: CoreOne-xCORE200-2.1.kicad_pcb Sheet: Open Hardware DSP Platform - www.ohdsp.org

Id: 1/1 Title: CoreOne - xCORE200 Platform

eg Dirty PCB or JLCPCB JLC7628 Stackups

Use 26AWG ribbon cables to match PCB impedances (approx 89ohm)

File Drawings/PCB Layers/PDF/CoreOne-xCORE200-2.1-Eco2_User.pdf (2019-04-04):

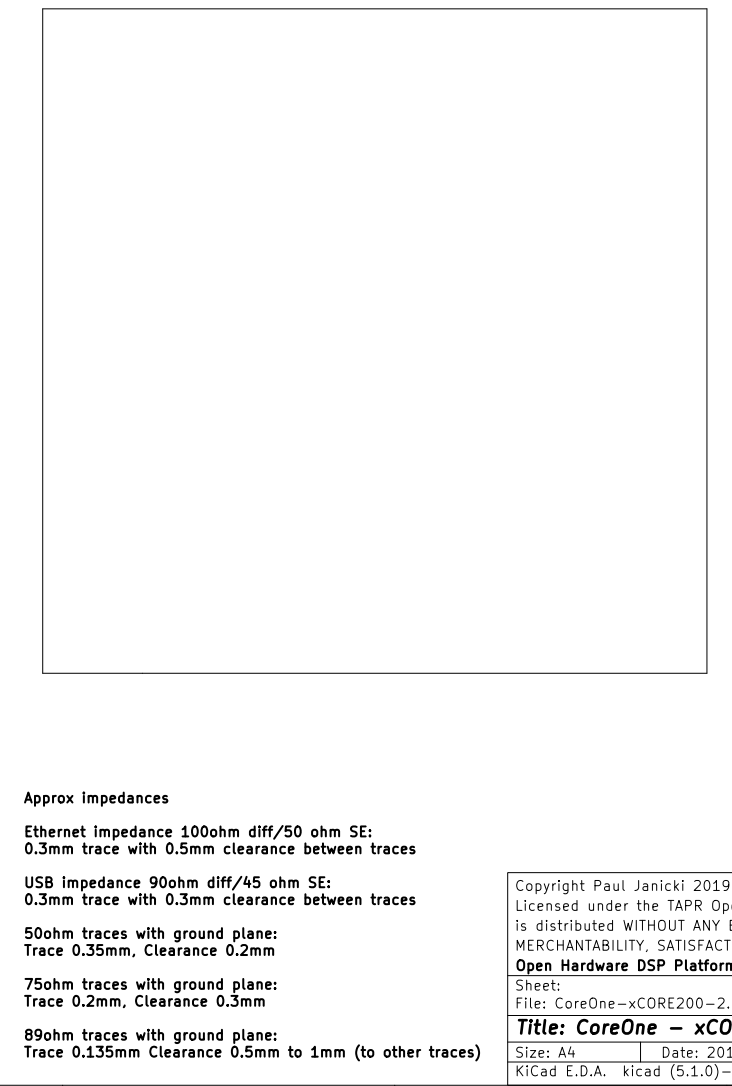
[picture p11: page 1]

Ethernet impedance 100ohm diff/50 ohm SE: 0.3mm trace with 0.5mm clearance between traces USB impedance 90ohm diff/45 ohm SE: 0.3mm trace with 0.3mm clearance between traces

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

50ohm traces with ground plane:
Trace 0.35mm, Clearance 0.2mm

75ohm traces with ground plane:
Trace 0.2mm, Clearance 0.3mm

Id: 1/1 Title: CoreOne - xCORE200 Platform

89ohm traces with ground plane:
Trace 0.135mm Clearance 0.5mm to 1mm (to other traces)

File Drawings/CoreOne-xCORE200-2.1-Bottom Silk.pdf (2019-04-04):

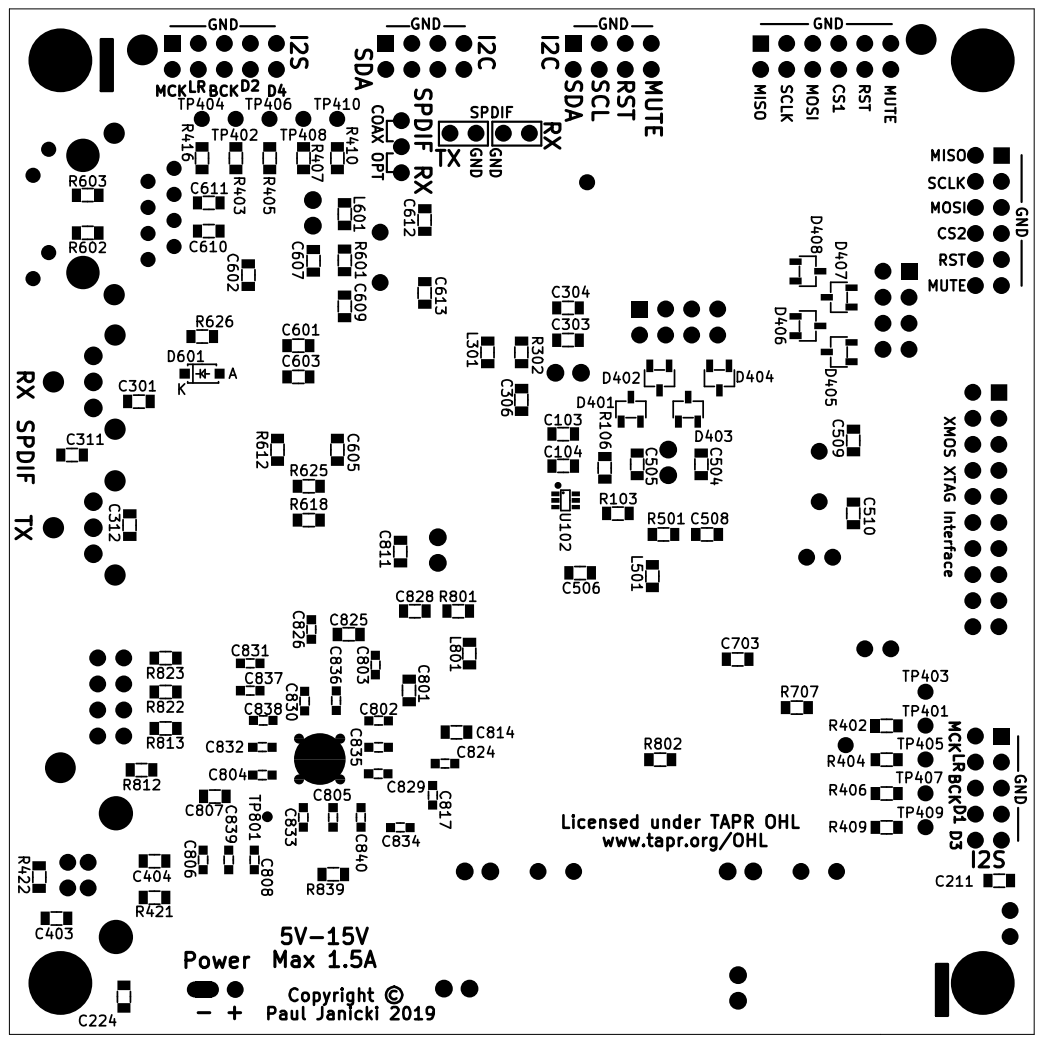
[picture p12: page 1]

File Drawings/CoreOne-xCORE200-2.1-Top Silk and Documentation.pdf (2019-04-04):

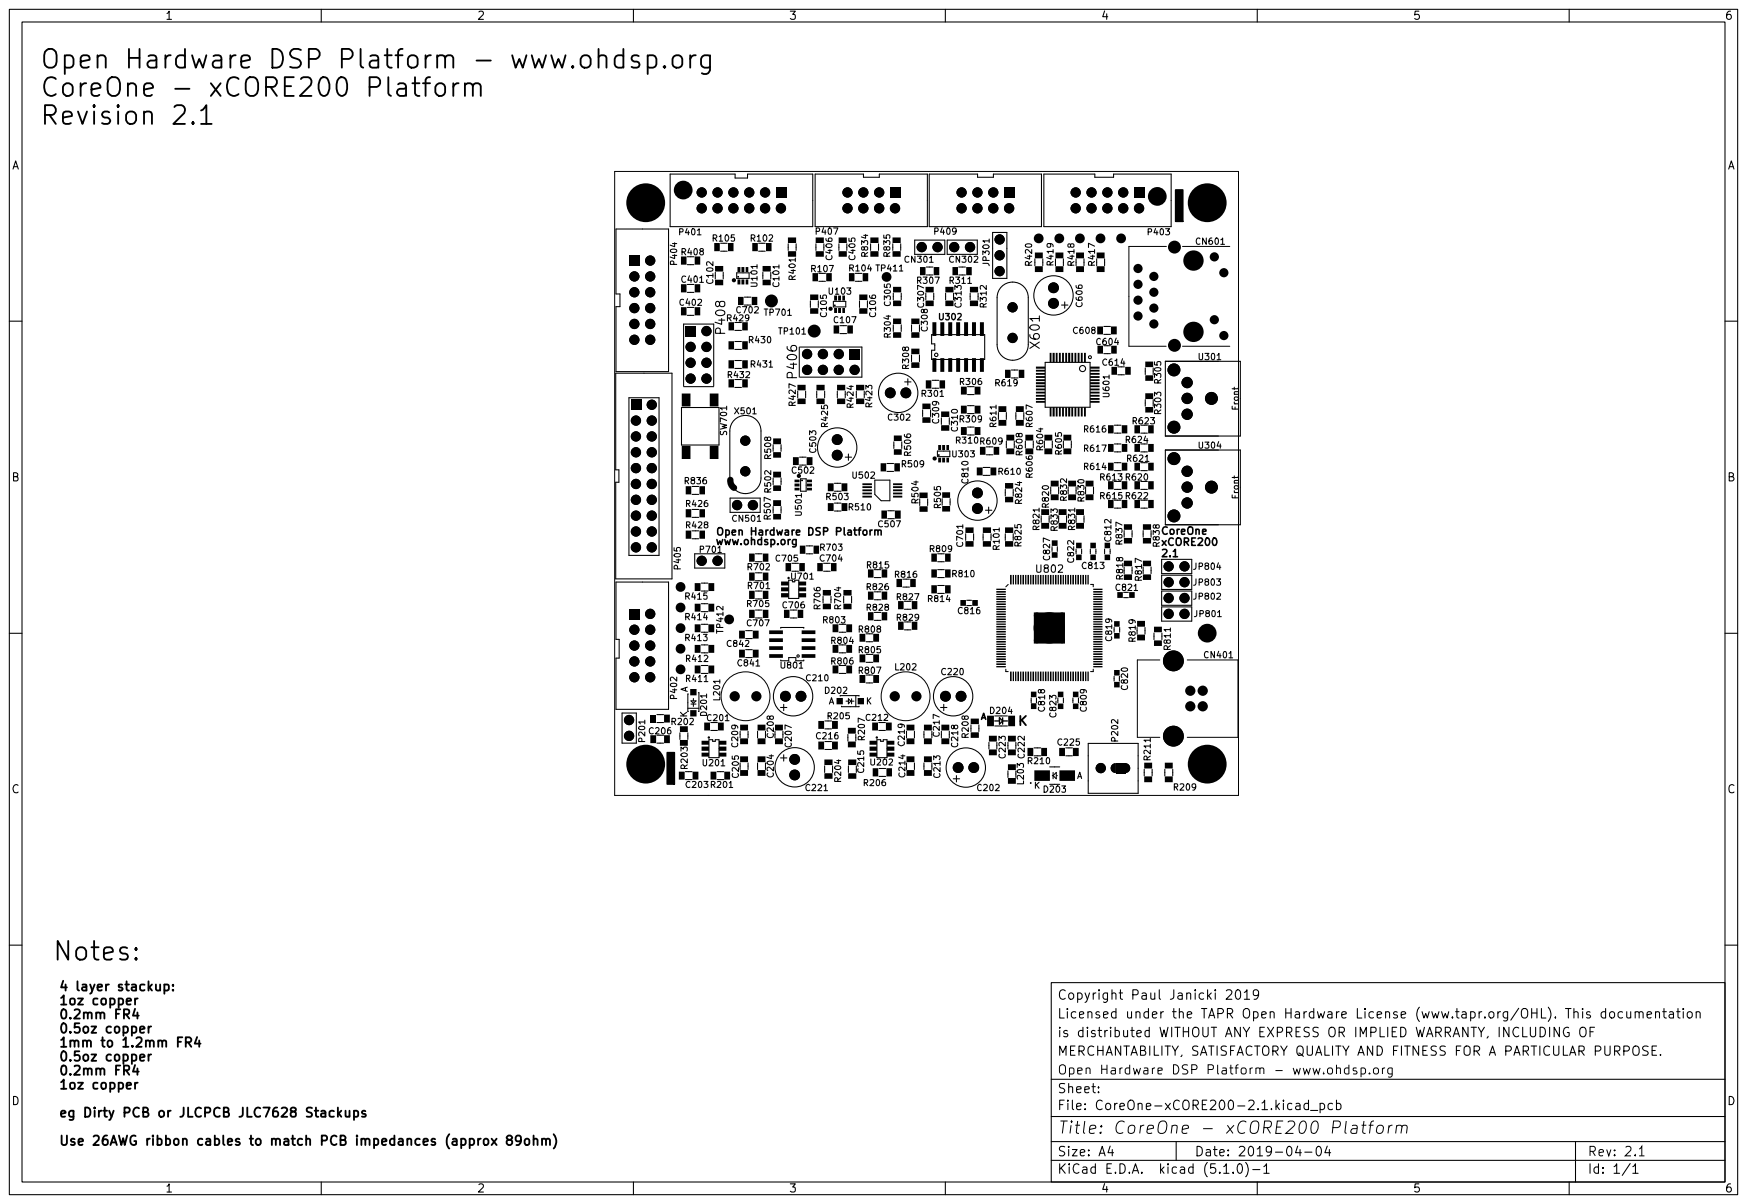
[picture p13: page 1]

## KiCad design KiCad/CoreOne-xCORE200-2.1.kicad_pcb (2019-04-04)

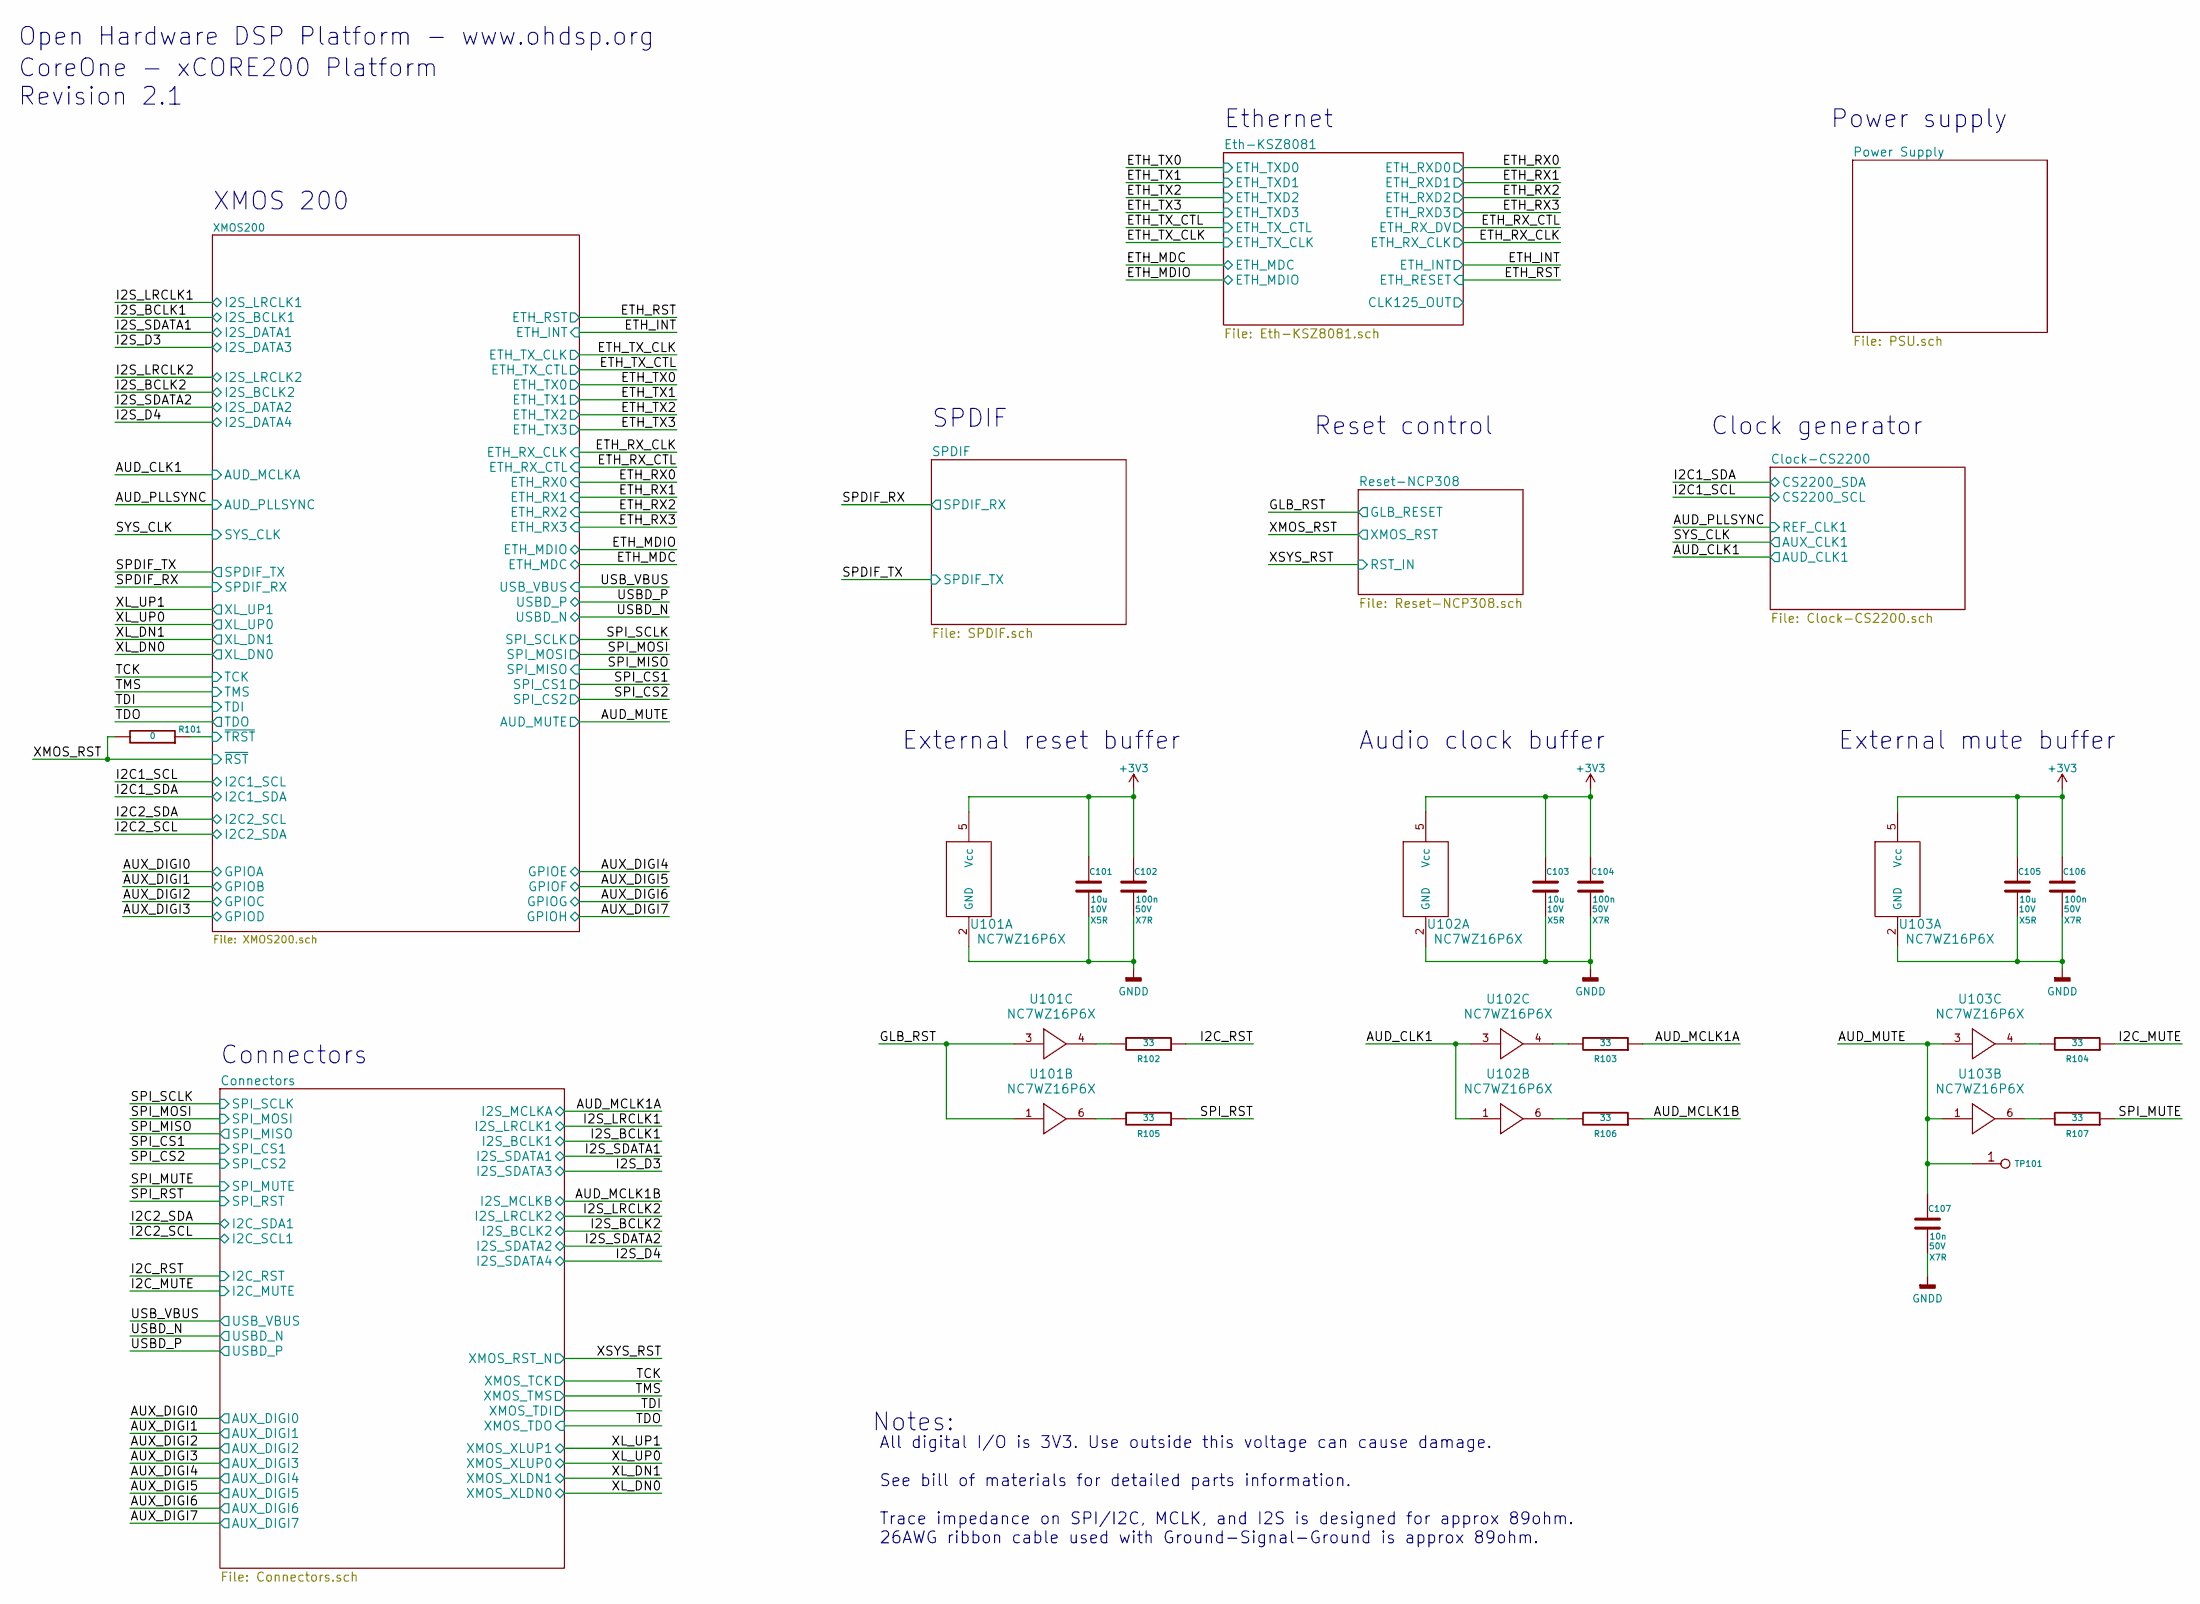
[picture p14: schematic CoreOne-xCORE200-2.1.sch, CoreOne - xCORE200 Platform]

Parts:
C101, C103, C105: 10u; SMD-0805; Voltage 10V; Tolerance 20%
C102, C104, C106: 100n; SMD-0805; Voltage 50V; Tolerance 10%
C107: 10n; SMD-0805; Voltage 50V; Tolerance 10%
R101: 0; SMD-0805; Tolerance 1%
R102, R103, R104, R105, R106, R107: 33; SMD-0805; Tolerance 1%
TP101: PIN; TP-2mm
U101, U102, U103: NC7WZ16P6X; IC-SC70-6

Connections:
/AUD_CLK1: U102.1, U102.3; also elsewhere on the board
/AUD_MCLK1A: R103.1; also elsewhere on the board
/AUD_MCLK1B: R106.1; also elsewhere on the board
/AUD_MUTE: C107.1, TP101.1, U103.1, U103.3; also elsewhere on the board
/GLB_RST: U101.1, U101.3; also elsewhere on the board
/I2C_MUTE: R104.1; also elsewhere on the board
/I2C_RST: R102.1; also elsewhere on the board
/SPI_MUTE: R107.1; also elsewhere on the board
/SPI_RST: R105.1; also elsewhere on the board
/XMOS200/~TRST~: R101.1; also elsewhere on the board
/XMOS_RST: R101.2; also elsewhere on the board
GNDD: C101.2, C102.2, C103.2, C104.2, C105.2, C106.2, C107.2, U101.2 (GND), U102.2 (GND), U103.2 (GND); also elsewhere on the board
unnamed: R102.2, U101.4
unnamed: R103.2, U102.4
unnamed: R104.2, U103.4
unnamed: R105.2, U101.6
unnamed: R106.2, U102.6
unnamed: R107.2, U103.6

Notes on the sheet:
Open Hardware DSP Platform - www.ohdsp.org
All digital I/O is 3V3. Use outside this voltage can cause damage. See bill of materials for detailed parts information. Trace impedance on SPI/I2C, MCLK, and I2S is designed for approx 89ohm. 26AWG ribbon cable used with Ground-Signal-Ground is approx 89ohm.
Notes:
CoreOne - xCORE200 Platform Revision 2.1
XMOS 200
Ethernet
Connectors
SPDIF
Reset control
Power supply
Clock generator
External reset buffer
Audio clock buffer
External mute buffer

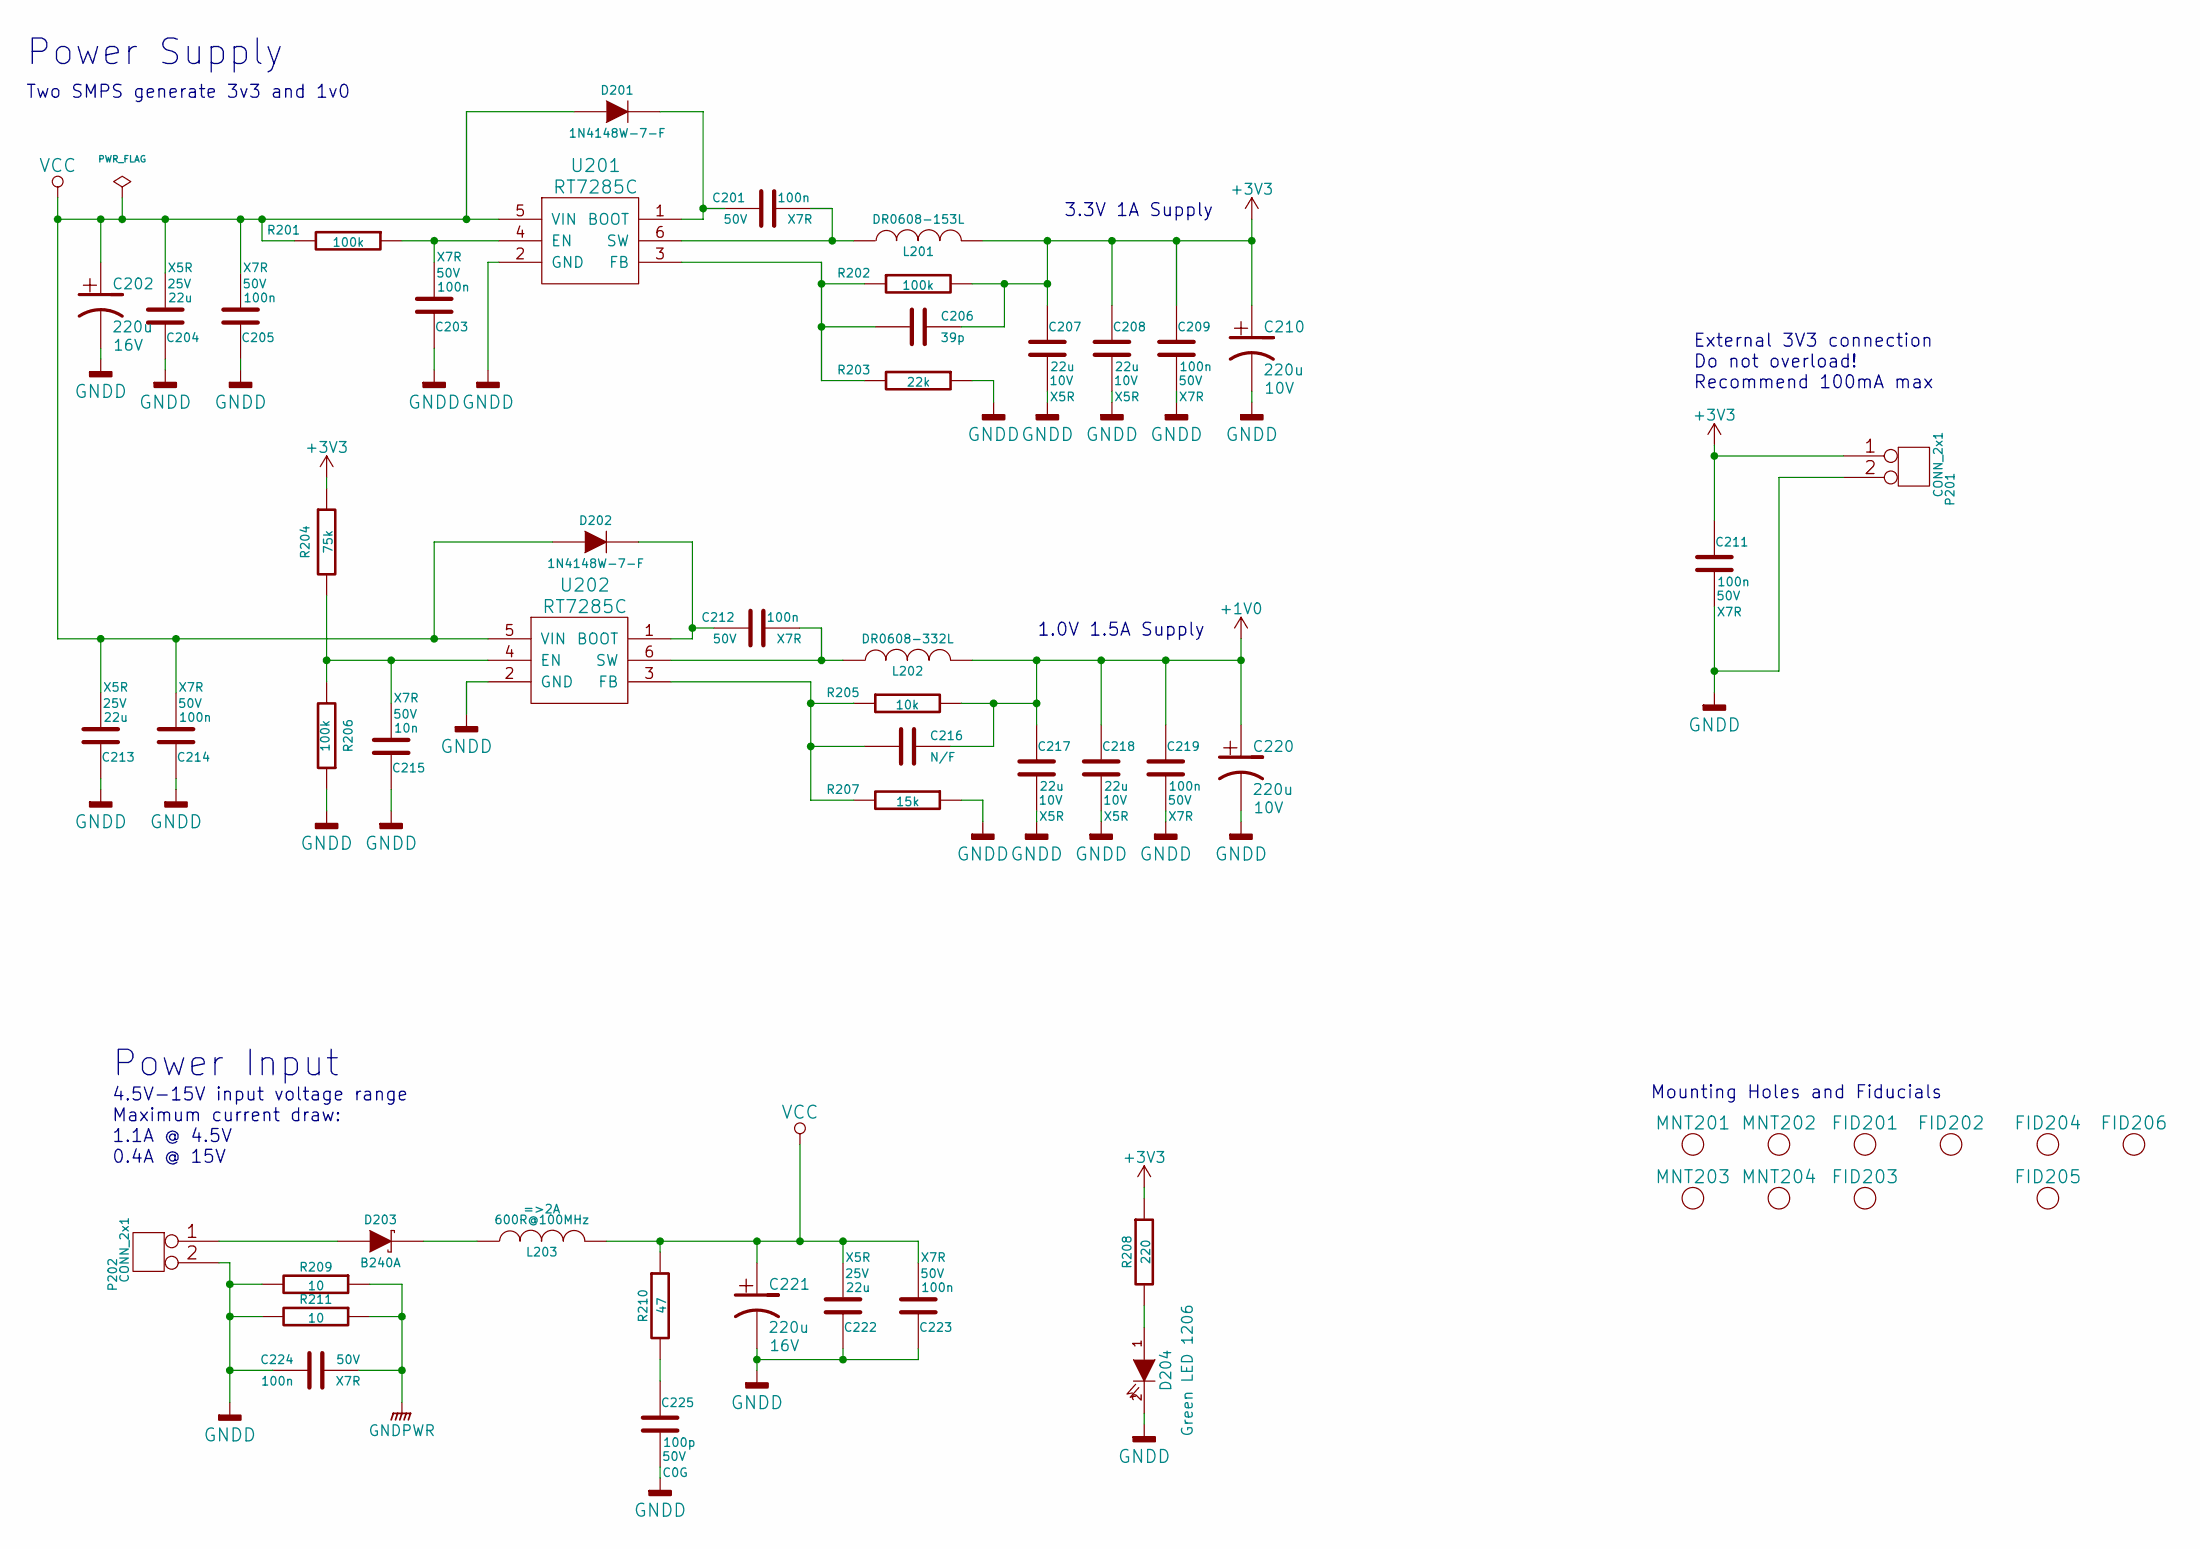
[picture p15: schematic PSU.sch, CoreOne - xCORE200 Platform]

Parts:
C201, C203, C205, C209, C211, C212, C214, C219, C223, C224: 100n; SMD-0805; Voltage 50V; Tolerance 10%
C202, C221: 220u; CAP-TH-D6.3mmP2.5mm; Voltage 16V
C204, C213, C222: 22u; SMD-0805; Voltage 25V; Tolerance 20%
C206: 39p; SMD-0805; Voltage 50V; Tolerance 10%
C207, C208, C217, C218: 22u; SMD-0805; Voltage 10V; Tolerance 20%
C210, C220: 220u; CAP-TH-D6.3mmP2.5mm; Voltage 10V
C215: 10n; SMD-0805; Voltage 50V; Tolerance 10%
C216: N/F; SMD-0805; Voltage 50V; Tolerance 10%
C225: 100p; SMD-0805; Voltage 50V; Tolerance 5%
D201, D202: 1N4148W-7-F; DIODE-SOD-123
D203: B240A; DIODE-SMA
D204: Green LED 1206; SMD-1206
FID201, FID202, FID203, FID204, FID205, FID206: MNT_HOLE; FID-1MM-3MM
L201: DR0608-153L; IND-TH-DR0608
L202: DR0608-332L; IND-TH-DR0608
L203: 600R@100MHz; SMD-0805
MNT201, MNT202, MNT203, MNT204: MNT_HOLE; MNT_HOLE_3.2mm
P201: CONN_2x1; CONN_SIL_2_1MM
P202: CONN_2x1; CONN-2WAY-2.54mm-3.81mm-SPACING
R201, R202, R206: 100k; SMD-0805; Tolerance 1%
R203: 22k; SMD-0805; Tolerance 1%
R204: 75k; SMD-0805; Tolerance 1%
R205: 10k; SMD-0805; Tolerance 1%
R207: 15k; SMD-0805; Tolerance 1%
R208: 220; SMD-0805; Tolerance 1%
R209, R211: 10; SMD-0805; Tolerance 1%
R210: 47; SMD-0805; Tolerance 1%
U201, U202: RT7285C; IC-SOT23-6

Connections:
+1V0: C216.1, C217.1, C218.1, C219.1, C220.1, L202.2, R205.2; also elsewhere on the board
GNDD: C202.2, C203.1, C204.1, C205.1, C207.2, C208.2, C209.2, C210.2, C211.2, C213.1, C214.1, C215.1, C217.2, C218.2, C219.2, C220.2, C221.2, C222.1, C223.1, C224.1, C225.2, D204.2 (K), P201.2, P202.2, R203.1, R206.1, R207.1, R209.2, R211.2, U201.2 (GND), U202.2 (GND); also elsewhere on the board
GNDPWR: C224.2, R209.1, R211.1; also elsewhere on the board
unnamed: C201.1, D201.2 (K), U201.1 (BOOT)
unnamed: C201.2, L201.1, U201.6 (SW)
unnamed: C203.2, R201.1, U201.4 (EN)
unnamed: C206.2, R202.1, R203.2, U201.3 (FB)
unnamed: C212.1, D202.2 (K), U202.1 (BOOT)
unnamed: C212.2, L202.1, U202.6 (SW)
unnamed: C215.2, R204.2, R206.2, U202.4 (EN)
unnamed: C216.2, R205.1, R207.2, U202.3 (FB)
unnamed: C225.1, R210.2
unnamed: D203.1 (A), P202.1
unnamed: D203.2 (K), L203.1
unnamed: D204.1 (A), R208.2
VCC: C202.1, C204.2, C205.2, C213.2, C214.2, C221.1, C222.2, C223.2, D201.1 (A), D202.1 (A), L203.2, R201.2, R210.1, U201.5 (VIN), U202.5 (VIN)

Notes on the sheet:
Power Supply
4.5V-15V input voltage range Maximum current draw: 1.1A @ 4.5V 0.4A @ 15V
Power Input
Two SMPS generate 3v3 and 1v0
External 3V3 connection Do not overload! Recommend 100mA max
Mounting Holes and Fiducials
3.3V 1A Supply
1.0V 1.5A Supply

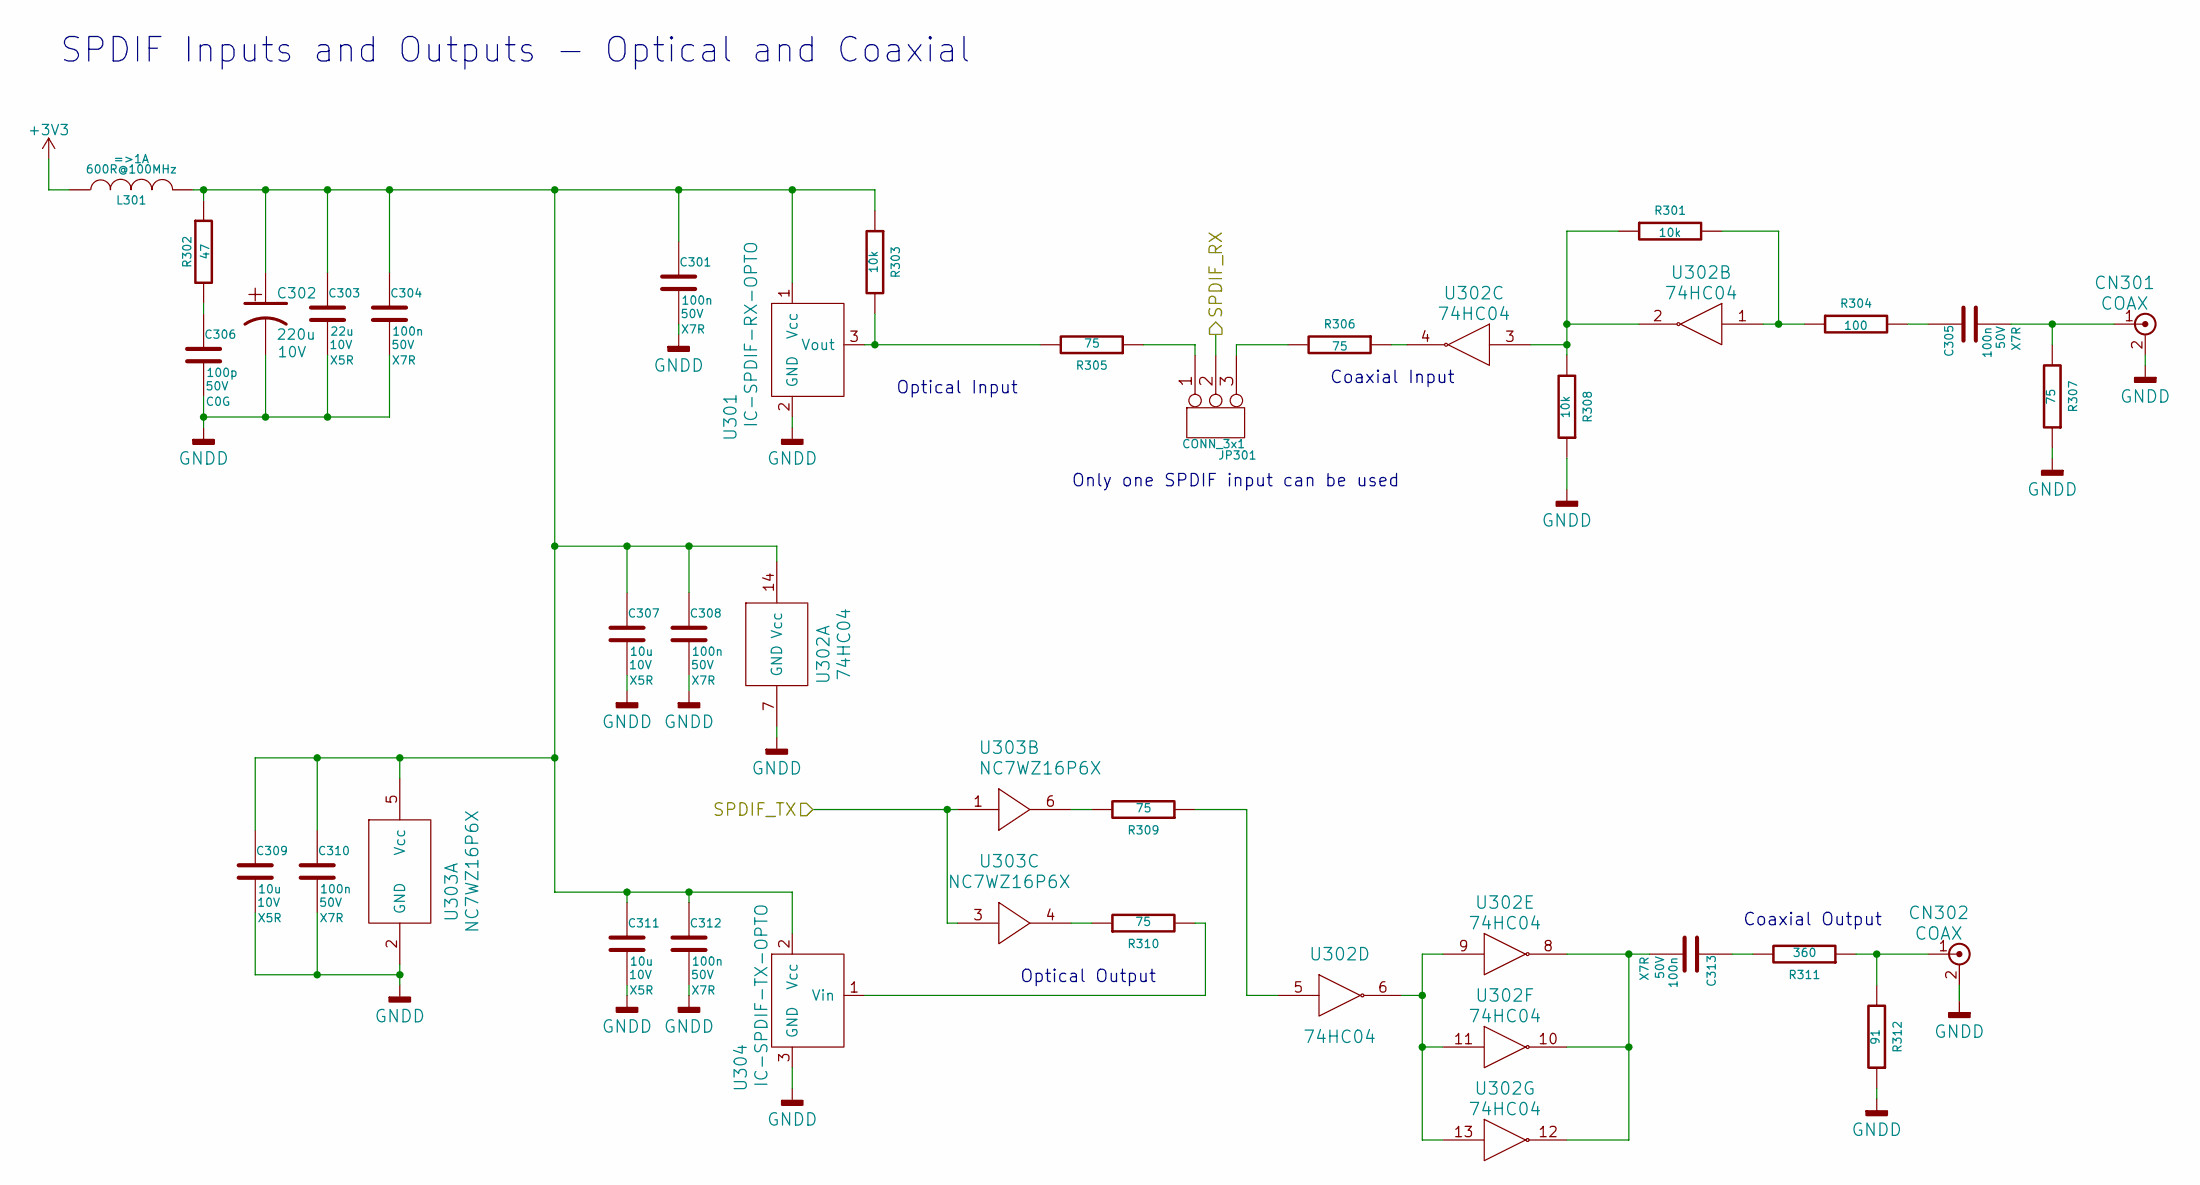
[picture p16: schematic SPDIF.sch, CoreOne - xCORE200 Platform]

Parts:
C301, C304, C305, C308, C310, C312, C313: 100n; SMD-0805; Voltage 50V; Tolerance 10%
C302: 220u; CAP-TH-D6.3mmP2.5mm; Voltage 10V
C303: 22u; SMD-0805; Voltage 10V; Tolerance 20%
C306: 100p; SMD-0805; Voltage 50V; Tolerance 5%
C307, C309, C311: 10u; SMD-0805; Voltage 10V; Tolerance 20%
CN301, CN302: COAX; CONN_SIL_2_1MM
JP301: CONN_3x1; CONN_SIL_3_1MM
L301: 600R@100MHz; SMD-0805
R301, R303, R308: 10k; SMD-0805; Tolerance 1%
R302: 47; SMD-0805; Tolerance 1%
R304: 100; SMD-0805; Tolerance 1%
R305, R306, R307, R309, R310: 75; SMD-0805; Tolerance 1%
R311: 360; SMD-0805; Tolerance 1%
R312: 91; SMD-0805; Tolerance 1%
U301: IC-SPDIF-RX-OPTO; IC_SPDIF_OPTO
U302: 74HC04; IC_SOIC_14
U303: NC7WZ16P6X; IC-SC70-6
U304: IC-SPDIF-TX-OPTO; IC_SPDIF_OPTO

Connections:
/SPDIF_RX: JP301.2; also elsewhere on the board
/SPDIF_TX: U303.1, U303.3; also elsewhere on the board
GNDD: C301.2, C302.2, C303.2, C304.2, C306.2, C307.2, C308.2, C309.2, C310.2, C311.2, C312.2, CN301.2, CN302.2, R307.1, R308.1, R312.1, U301.2 (GND), U302.7 (GND), U303.2 (GND), U304.3 (GND); also elsewhere on the board
unnamed: C301.1, C302.1, C303.1, C304.1, C307.1, C308.1, C309.1, C310.1, C311.1, C312.1, L301.2, R302.1, R303.1, U301.1 (Vcc), U302.14 (Vcc), U303.5 (Vcc), U304.2 (Vcc)
unnamed: C305.1, R304.2
unnamed: C305.2, CN301.1, R307.2
unnamed: C306.1, R302.2
unnamed: C313.1, R311.2
unnamed: C313.2, U302.8, U302.10, U302.12
unnamed: CN302.1, R311.1, R312.2
unnamed: JP301.1, R305.1
unnamed: JP301.3, R306.2
unnamed: R301.1, R308.2, U302.2, U302.3
unnamed: R301.2, R304.1, U302.1
unnamed: R303.2, R305.2, U301.3 (Vout)
unnamed: R306.1, U302.4
unnamed: R309.1, U302.5
unnamed: R309.2, U303.6
unnamed: R310.1, U303.4
unnamed: R310.2, U304.1 (Vin)
unnamed: U302.6, U302.9, U302.11, U302.13

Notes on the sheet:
SPDIF Inputs and Outputs - Optical and Coaxial
Optical Input
Coaxial Input
Optical Output
Coaxial Output
Only one SPDIF input can be used

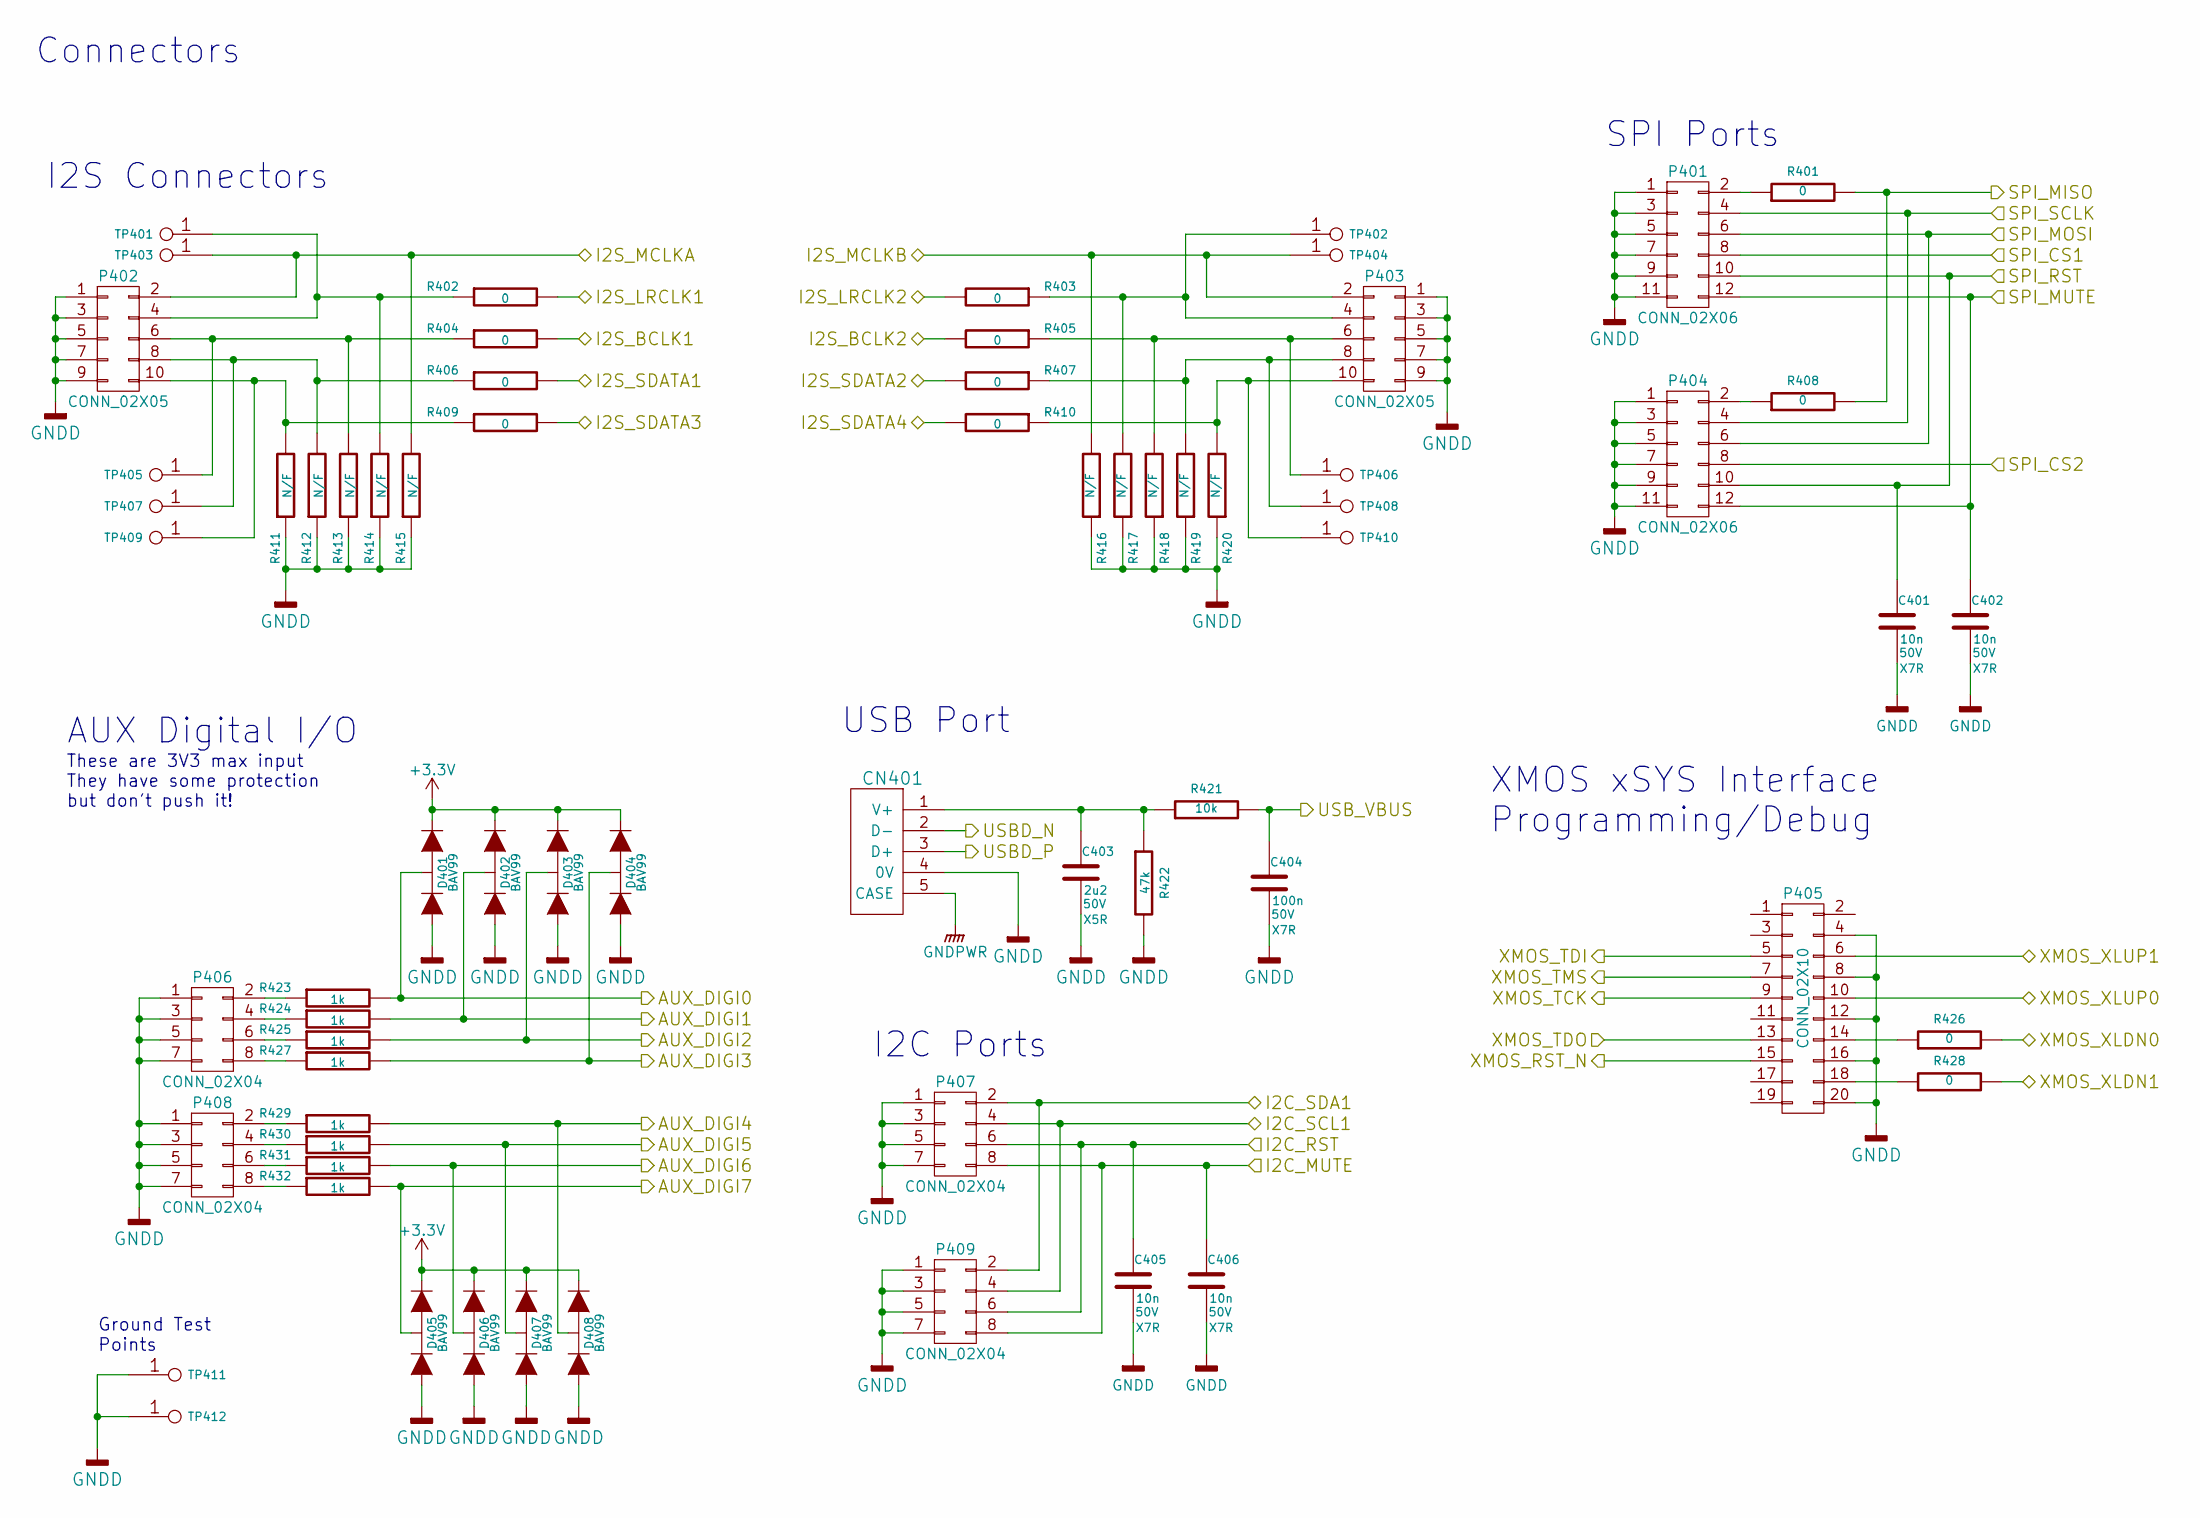
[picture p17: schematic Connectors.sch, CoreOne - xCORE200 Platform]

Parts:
C401, C402, C405, C406: 10n; SMD-0805; Voltage 50V; Tolerance 10%
C403: 2u2; SMD-0805; Voltage 50V; Tolerance 10%
C404: 100n; SMD-0805; Voltage 50V; Tolerance 10%
CN401: CONN-USB-B-61729; CONN-USB-B-61729-0010
D401, D402, D403, D404, D405, D406, D407, D408: BAV99; IC-SOT23
P401, P404: CONN_02X06; CONN_DIL_2X6_BOX_1MM
P402, P403: CONN_02X05; CONN_DIL_2X5_BOX_1MM
P405: CONN_02X10; CONN_DIL_2X10_BOX_1MM
P406, P408: CONN_02X04; CONN_DIL_2X04
P407, P409: CONN_02X04; CONN_DIL_2X4_BOX_1MM
R401, R402, R403, R404, R405, R406, R407, R408, R409, R410, R426, R428: 0; SMD-0805; Tolerance 1%
R411, R412, R413, R414, R415, R416, R417, R418, R419, R420: N/F; SMD-0805; Tolerance 1%
R421: 10k; SMD-0805; Tolerance 1%
R422: 47k; SMD-0805; Tolerance 1%
R423, R424, R425, R427, R429, R430, R431, R432: 1k; SMD-0805; Tolerance 1%
TP401, TP402, TP403, TP404, TP405, TP406, TP407, TP408, TP409, TP410, TP411, TP412: PIN; TP-TH-1mm

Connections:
/AUD_MCLK1A: P402.2, R415.2, TP403.1; also elsewhere on the board
/AUD_MCLK1B: P403.2, R416.2, TP404.1; also elsewhere on the board
/AUX_DIGI0: D401.3 (K1A2), R423.2; also elsewhere on the board
/AUX_DIGI1: D402.3 (K1A2), R424.2; also elsewhere on the board
/AUX_DIGI2: D403.3 (K1A2), R425.2; also elsewhere on the board
/AUX_DIGI3: D404.3 (K1A2), R427.2; also elsewhere on the board
/AUX_DIGI4: D408.3 (K1A2), R429.2; also elsewhere on the board
/AUX_DIGI5: D407.3 (K1A2), R430.2; also elsewhere on the board
/AUX_DIGI6: D406.3 (K1A2), R431.2; also elsewhere on the board
/AUX_DIGI7: D405.3 (K1A2), R432.2; also elsewhere on the board
/I2C2_SCL: P407.4, P409.4; also elsewhere on the board
/I2C2_SDA: P407.2, P409.2; also elsewhere on the board
/I2C_MUTE: C406.1, P407.8, P409.8; also elsewhere on the board
/I2C_RST: C405.1, P407.6, P409.6; also elsewhere on the board
/I2S_BCLK1: R404.2; also elsewhere on the board
/I2S_BCLK2: R405.2; also elsewhere on the board
/I2S_D3: R409.2; also elsewhere on the board
/I2S_D4: R410.2; also elsewhere on the board
/I2S_LRCLK1: R402.2; also elsewhere on the board
/I2S_LRCLK2: R403.2; also elsewhere on the board
/I2S_SDATA1: R406.2; also elsewhere on the board
/I2S_SDATA2: R407.2; also elsewhere on the board
/SPI_CS1: P401.8; also elsewhere on the board
/SPI_CS2: P404.8; also elsewhere on the board
/SPI_MISO: R401.2, R408.2; also elsewhere on the board
/SPI_MOSI: P401.6, P404.6; also elsewhere on the board
/SPI_MUTE: C402.1, P401.12, P404.12; also elsewhere on the board
/SPI_RST: C401.1, P401.10, P404.10; also elsewhere on the board
/SPI_SCLK: P401.4, P404.4; also elsewhere on the board
/TCK: P405.9; also elsewhere on the board
/TDI: P405.5; also elsewhere on the board
/TDO: P405.13; also elsewhere on the board
/TMS: P405.7; also elsewhere on the board
/USBD_N: CN401.2 (D-); also elsewhere on the board
/USBD_P: CN401.3 (D+); also elsewhere on the board
/USB_VBUS: C404.1, R421.2; also elsewhere on the board
/XL_DN0: R426.2; also elsewhere on the board
/XL_DN1: R428.2; also elsewhere on the board
/XL_UP0: P405.10; also elsewhere on the board
/XL_UP1: P405.6; also elsewhere on the board
/XSYS_RST: P405.15; also elsewhere on the board
GNDD: C401.2, C402.2, C403.2, C404.2, C405.2, C406.2, CN401.4 (0V), D401.1 (A1), D402.1 (A1), D403.1 (A1), D404.1 (A1), D405.1 (A1), D406.1 (A1), D407.1 (A1), D408.1 (A1), P401.1, P401.3, P401.5, P401.7, P401.9, P401.11, P402.1, P402.3, P402.5, P402.7, P402.9, P403.1, P403.3, P403.5, P403.7, P403.9, P404.1, P404.3, P404.5, P404.7, P404.9, P404.11, P405.4, P405.8, P405.12, P405.16, P405.20, P406.1, P406.3, P406.5, P406.7, P407.1, P407.3, P407.5, P407.7, P408.1, P408.3, P408.5, P408.7, P409.1, P409.3, P409.5, P409.7, R411.1, R412.1, R413.1, R414.1, R415.1, R416.1, R417.1, R418.1, R419.1, R420.1, R422.2, TP411.1, TP412.1; also elsewhere on the board
GNDPWR: CN401.5 (CASE); also elsewhere on the board
unnamed: C403.1, CN401.1 (V+), R421.1, R422.1
unnamed: P401.2, R401.1
unnamed: P402.4, R402.1, R414.2, TP401.1
unnamed: P402.6, R404.1, R413.2, TP405.1
unnamed: P402.8, R406.1, R412.2, TP407.1
unnamed: P402.10, R409.1, R411.2, TP409.1
unnamed: P403.4, R403.1, R417.2, TP402.1
unnamed: P403.6, R405.1, R418.2, TP406.1
unnamed: P403.8, R407.1, R419.2, TP408.1
unnamed: P403.10, R410.1, R420.2, TP410.1
unnamed: P404.2, R408.1
unnamed: P405.14, R426.1
unnamed: P405.18, R428.1
unnamed: P406.2, R423.1
unnamed: P406.4, R424.1
unnamed: P406.6, R425.1
unnamed: P406.8, R427.1
unnamed: P408.2, R429.1
unnamed: P408.4, R430.1
unnamed: P408.6, R431.1
unnamed: P408.8, R432.1

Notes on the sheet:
XMOS xSYS Interface Programming/Debug
AUX Digital I/O
I2S Connectors
These are 3V3 max input They have some protection but don't push it!
Ground Test Points
SPI Ports
Connectors
I2C Ports
USB Port

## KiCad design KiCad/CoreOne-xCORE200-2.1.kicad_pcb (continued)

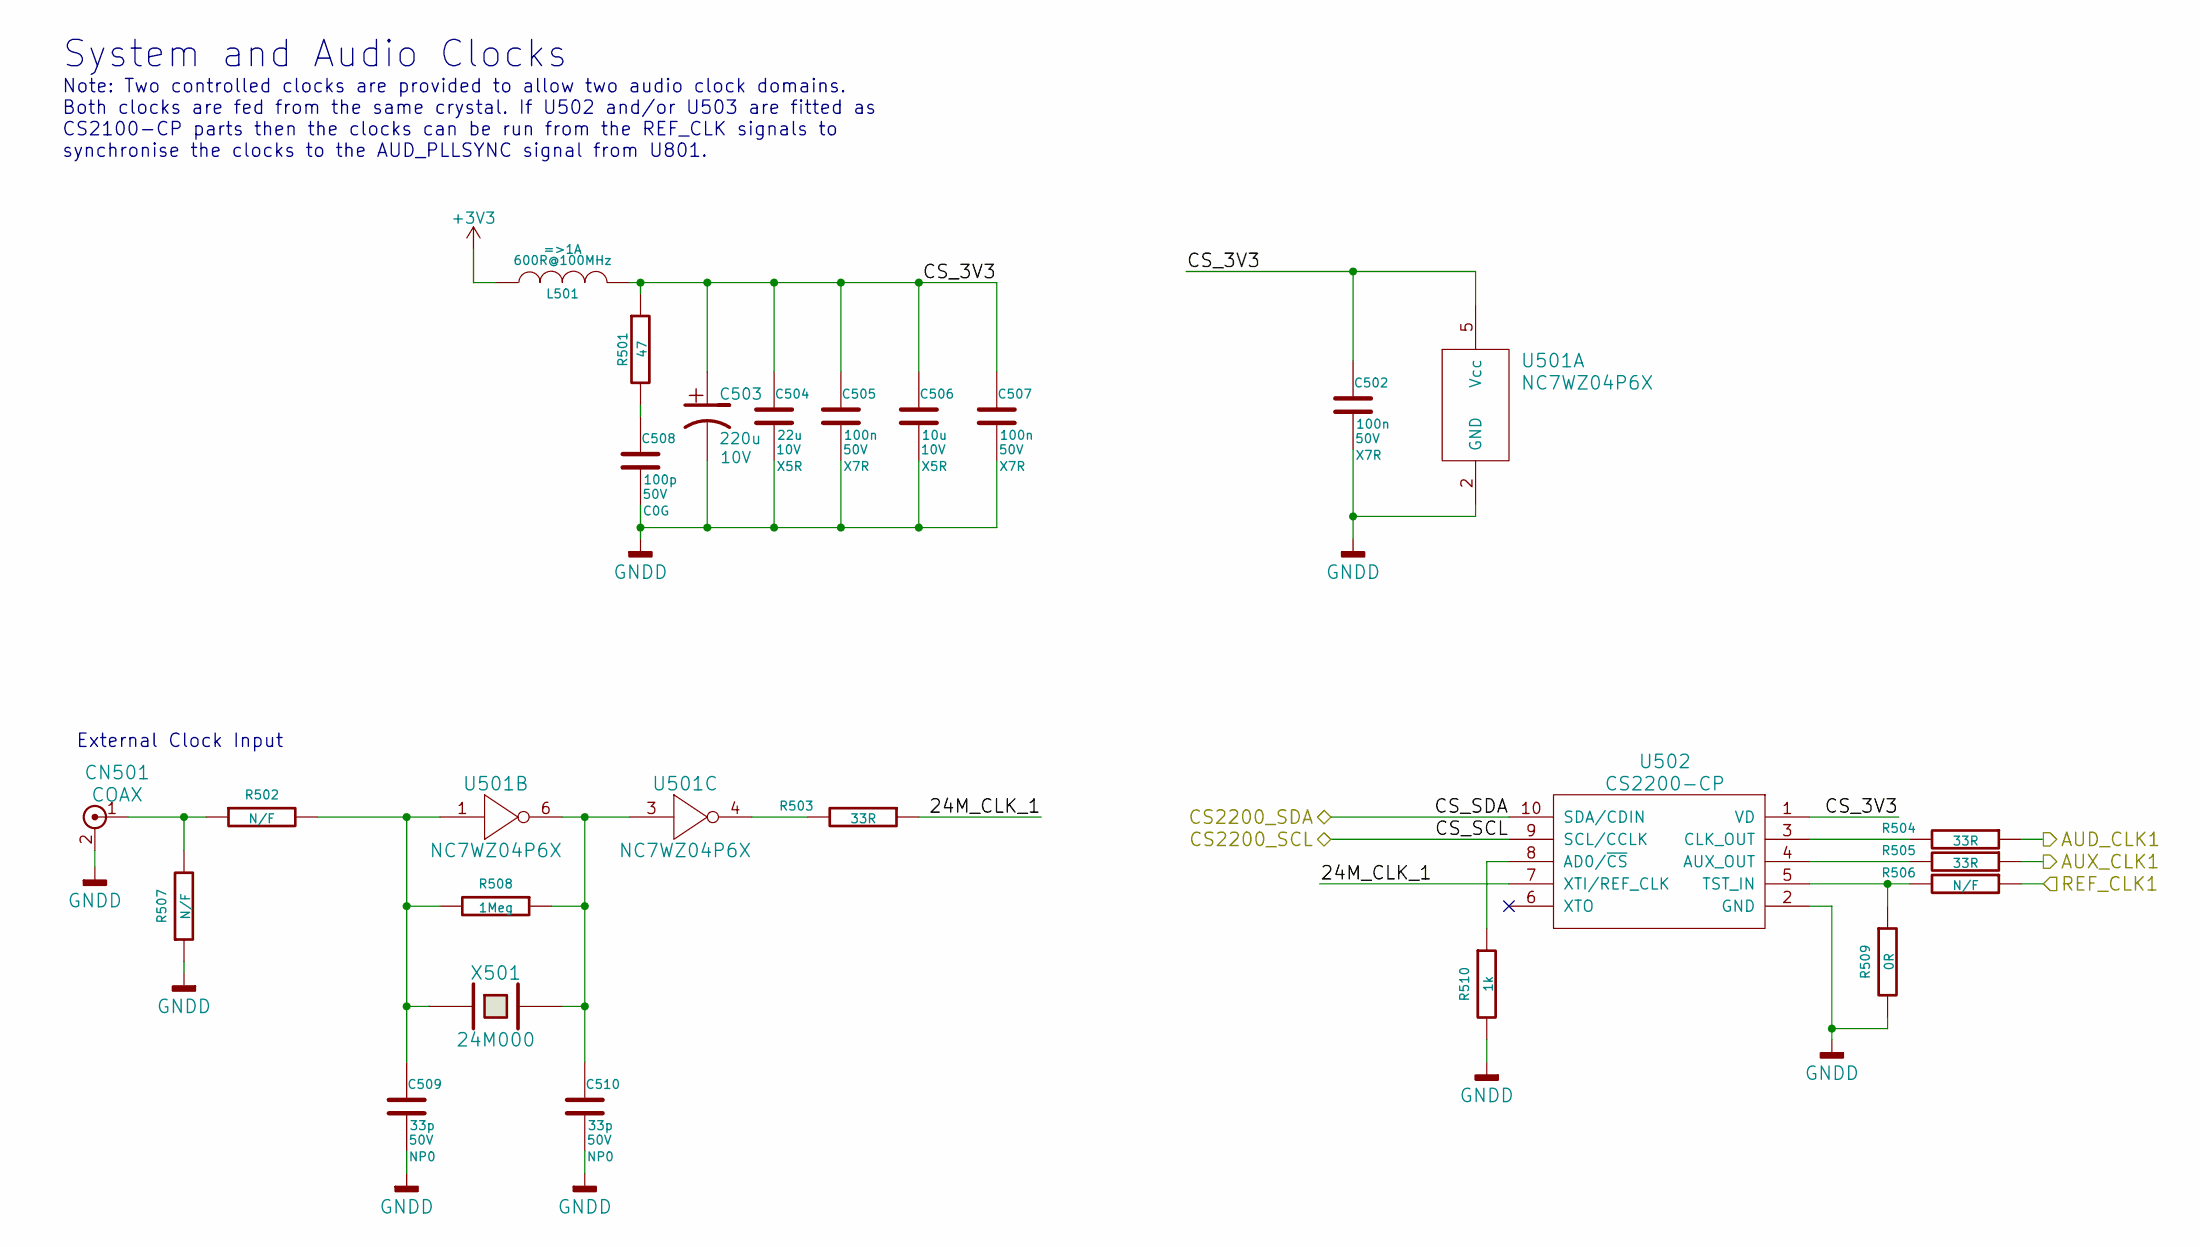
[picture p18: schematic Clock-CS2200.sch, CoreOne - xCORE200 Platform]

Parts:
C502, C505, C507: 100n; SMD-0805; Voltage 50V; Tolerance 10%
C503: 220u; CAP-TH-D6.3mmP2.5mm; Voltage 10V
C504: 22u; SMD-0805; Voltage 10V; Tolerance 20%
C506: 10u; SMD-0805; Voltage 10V; Tolerance 20%
C508: 100p; SMD-0805; Voltage 50V; Tolerance 5%
C509, C510: 33p; SMD-0805; Voltage 50V; Tolerance 5%
CN501: COAX; CONN_SIL_2_1MM
L501: 600R@100MHz; SMD-0805
R501: 47; SMD-0805; Tolerance 1%
R502, R506, R507: N/F; SMD-0805; Tolerance 1%
R503, R504, R505: 33R; SMD-0805; Tolerance 1%
R508: 1Meg; SMD-0805; Tolerance 1%
R509: 0R; SMD-0805; Tolerance 1%
R510: 1k; SMD-0805; Tolerance 1%
U501: NC7WZ04P6X; IC-SC70-6
U502: CS2200-CP; IC-MSOP-10
X501: 24M000; XTAL_HC49_TH

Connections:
/AUD_CLK1: R504.1; also elsewhere on the board
/AUD_PLLSYNC: R506.1; also elsewhere on the board
/Clock-CS2200/24M_CLK_1: R503.1, U502.7 (XTI/REF_CLK)
/Clock-CS2200/CS_3V3: C502.1, C503.1, C504.1, C505.1, C506.1, C507.1, L501.2, R501.1, U501.5 (Vcc), U502.1 (VD)
/I2C1_SCL: U502.9 (SCL/CCLK); also elsewhere on the board
/I2C1_SDA: U502.10 (SDA/CDIN); also elsewhere on the board
/SYS_CLK: R505.1; also elsewhere on the board
GNDD: C502.2, C503.2, C504.2, C505.2, C506.2, C507.2, C508.2, C509.2, C510.2, CN501.2, R507.1, R509.2, R510.2, U501.2 (GND), U502.2 (GND); also elsewhere on the board
unnamed: C508.1, R501.2
unnamed: C509.1, R502.2, R508.2, U501.1, X501.1
unnamed: C510.1, R508.1, U501.3, U501.6, X501.2
unnamed: CN501.1, R502.1, R507.2
unnamed: R503.2, U501.4
unnamed: R504.2, U502.3 (CLK_OUT)
unnamed: R505.2, U502.4 (AUX_OUT)
unnamed: R506.2, R509.1, U502.5 (TST_IN)
unnamed: R510.1, U502.8 (AD0/~CS~)

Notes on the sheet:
System and Audio Clocks
External Clock Input
Note: Two controlled clocks are provided to allow two audio clock domains. Both clocks are fed from the same crystal. If U502 and/or U503 are fitted as CS2100-CP parts then the clocks can be run from the REF_CLK signals to synchronise the clocks to the AUD_PLLSYNC signal from U801.

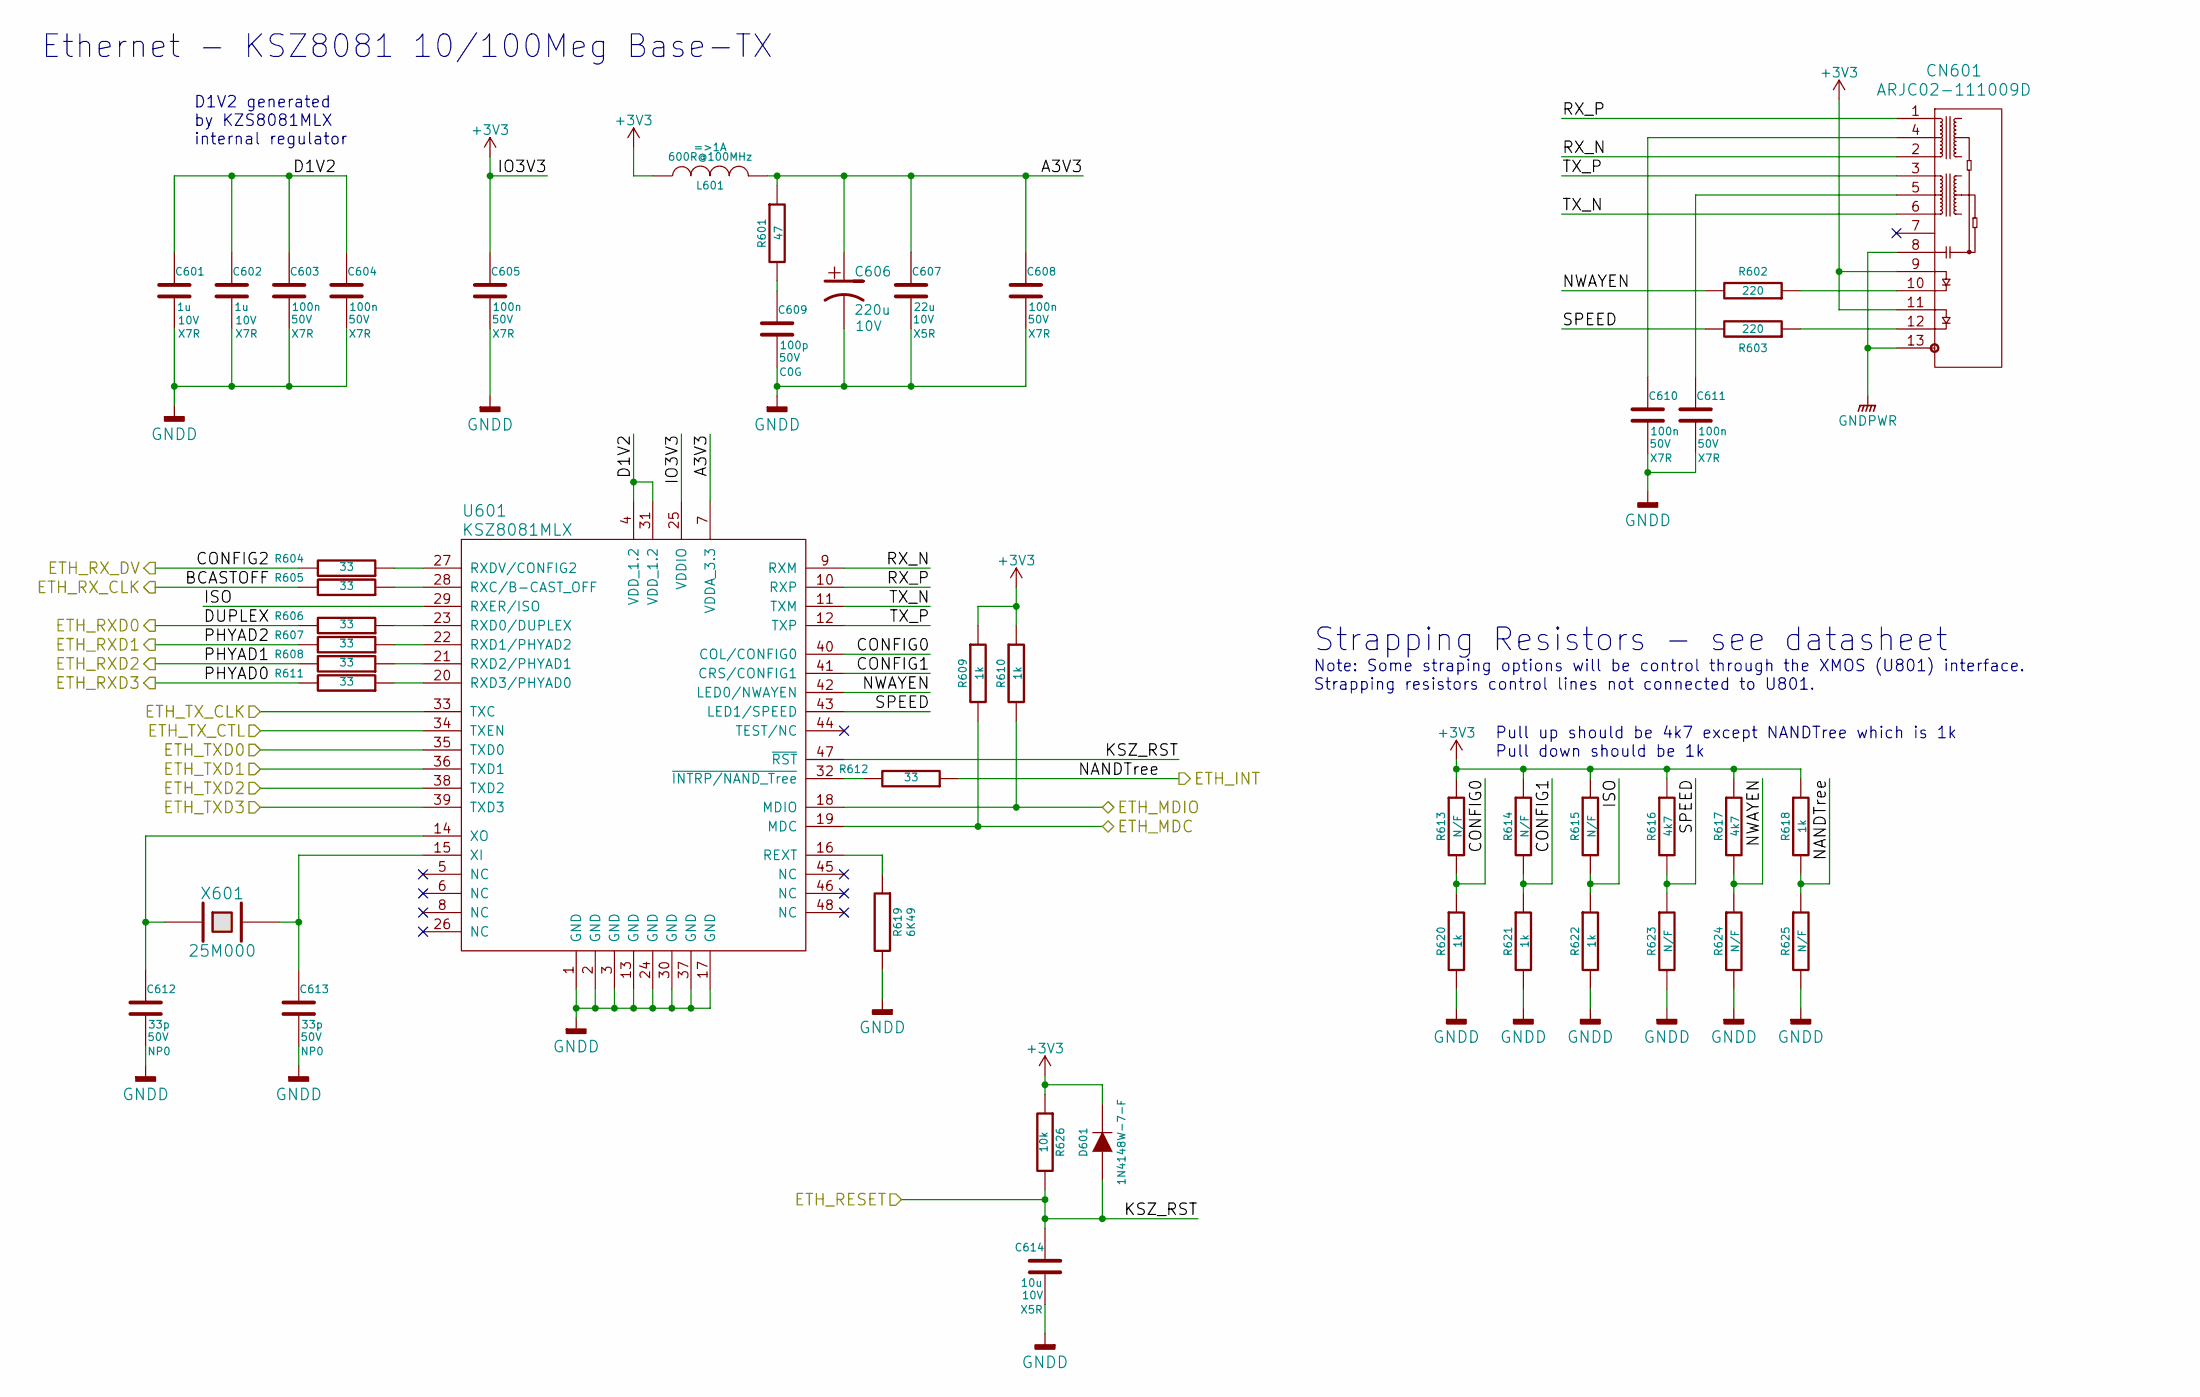
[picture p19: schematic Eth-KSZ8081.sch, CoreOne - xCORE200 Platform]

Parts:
C601, C602: 1u; SMD-0805; Voltage 10V; Tolerance 10%
C603, C604, C605, C608, C610, C611: 100n; SMD-0805; Voltage 50V; Tolerance 10%
C606: 220u; CAP-TH-D6.3mmP2.5mm; Voltage 10V
C607: 22u; SMD-0805; Voltage 10V; Tolerance 20%
C609: 100p; SMD-0805; Voltage 50V; Tolerance 5%
C612, C613: 33p; SMD-0805; Voltage 50V; Tolerance 5%
C614: 10u; SMD-0805; Voltage 10V; Tolerance 20%
CN601: ARJC02-111009D; CONN-RJ45-ARJC02-111xxxx
D601: 1N4148W-7-F; DIODE-SOD-123
L601: 600R@100MHz; SMD-0805
R601: 47; SMD-0805; Tolerance 1%
R602, R603: 220; SMD-0805; Tolerance 1%
R604, R605, R606, R607, R608, R611, R612: 33; SMD-0805; Tolerance 1%
R609, R610, R618, R620, R621, R622: 1k; SMD-0805; Tolerance 1%
R613, R614, R615, R623, R624, R625: N/F; SMD-0805; Tolerance 1%
R616, R617: 4k7; SMD-0805; Tolerance 1%
R619: 6K49; SMD-0805; Tolerance 1%
R626: 10k; SMD-0805; Tolerance 1%
U601: KSZ8081MLX; IC-LQFP48_7x7
X601: 25M000; XTAL_HC49_TH

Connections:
/ETH_INT: R612.1, R618.2, R625.1; also elsewhere on the board
/ETH_MDC: R609.2, U601.19 (MDC); also elsewhere on the board
/ETH_MDIO: R610.2, U601.18 (MDIO); also elsewhere on the board
/ETH_RST: C614.1, D601.1 (A), R626.2, U601.47 (~RST~); also elsewhere on the board
/ETH_RX0: R606.2; also elsewhere on the board
/ETH_RX1: R607.2; also elsewhere on the board
/ETH_RX2: R608.2; also elsewhere on the board
/ETH_RX3: R611.2; also elsewhere on the board
/ETH_RX_CLK: R605.2; also elsewhere on the board
/ETH_RX_CTL: R604.2; also elsewhere on the board
/ETH_TX0: U601.35 (TXD0); also elsewhere on the board
/ETH_TX1: U601.36 (TXD1); also elsewhere on the board
/ETH_TX2: U601.38 (TXD2); also elsewhere on the board
/ETH_TX3: U601.39 (TXD3); also elsewhere on the board
/ETH_TX_CLK: U601.33 (TXC); also elsewhere on the board
/ETH_TX_CTL: U601.34 (TXEN); also elsewhere on the board
/Eth-KSZ8081/A3V3: C606.1, C607.1, C608.1, L601.2, R601.1, U601.7 (VDDA_3.3)
/Eth-KSZ8081/CONFIG0: R613.2, R620.1, U601.40 (COL/CONFIG0)
/Eth-KSZ8081/CONFIG1: R614.2, R621.1, U601.41 (CRS/CONFIG1)
/Eth-KSZ8081/D1V2: C601.1, C602.1, C603.1, C604.1, U601.4 (VDD_1.2), U601.31 (VDD_1.2)
/Eth-KSZ8081/ISO: R615.2, R622.1, U601.29 (RXER/ISO)
/Eth-KSZ8081/NWAYEN: R602.2, R617.2, R624.1, U601.42 (LED0/NWAYEN)
/Eth-KSZ8081/RX_N: CN601.2, U601.9 (RXM)
/Eth-KSZ8081/RX_P: CN601.1, U601.10 (RXP)
/Eth-KSZ8081/SPEED: R603.2, R616.2, R623.1, U601.43 (LED1/SPEED)
/Eth-KSZ8081/TX_N: CN601.6, U601.11 (TXM)
/Eth-KSZ8081/TX_P: CN601.3, U601.12 (TXP)
GNDD: C601.2, C602.2, C603.2, C604.2, C605.2, C606.2, C607.2, C608.2, C609.2, C610.2, C611.2, C612.2, C613.2, C614.2, R619.2, R620.2, R621.2, R622.2, R623.2, R624.2, R625.2, U601.1 (GND), U601.2 (GND), U601.3 (GND), U601.13 (GND), U601.17 (GND), U601.24 (GND), U601.30 (GND), U601.37 (GND); also elsewhere on the board
GNDPWR: CN601.8, CN601.13; also elsewhere on the board
unnamed: C609.1, R601.2
unnamed: C610.1, CN601.4
unnamed: C611.1, CN601.5
unnamed: C612.1, U601.14 (XO), X601.1
unnamed: C613.1, U601.15 (XI), X601.2
unnamed: CN601.10, R602.1
unnamed: CN601.12, R603.1
unnamed: R604.1, U601.27 (RXDV/CONFIG2)
unnamed: R605.1, U601.28 (RXC/B-CAST_OFF)
unnamed: R606.1, U601.23 (RXD0/DUPLEX)
unnamed: R607.1, U601.22 (RXD1/PHYAD2)
unnamed: R608.1, U601.21 (RXD2/PHYAD1)
unnamed: R611.1, U601.20 (RXD3/PHYAD0)
unnamed: R612.2, U601.32 (~INTRP/NAND_Tree~)
unnamed: R619.1, U601.16 (REXT)

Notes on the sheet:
Strapping Resistors - see datasheet
Pull up should be 4k7 except NANDTree which is 1k Pull down should be 1k
Ethernet - KSZ8081 10/100Meg Base-TX
Note: Some straping options will be control through the XMOS (U801) interface. Strapping resistors control lines not connected to U801.
D1V2 generated by KZS8081MLX internal regulator

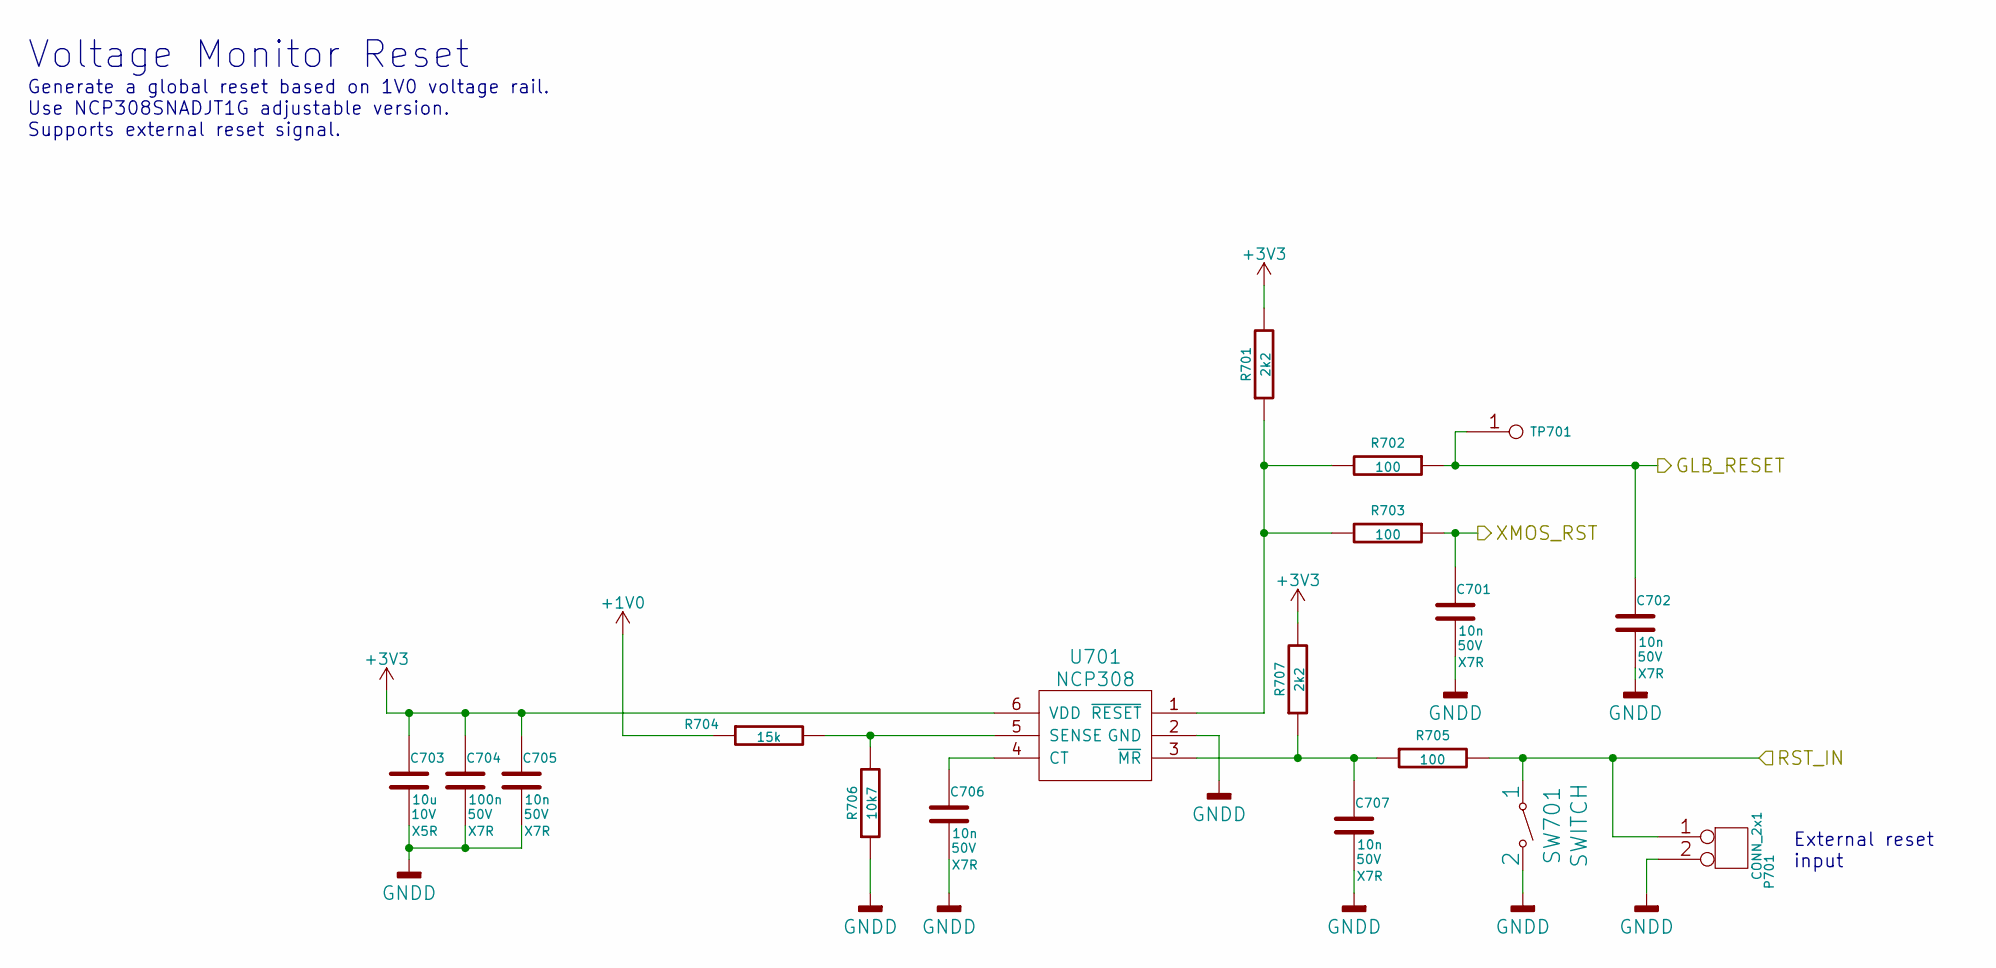
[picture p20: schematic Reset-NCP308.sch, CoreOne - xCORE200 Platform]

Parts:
C701, C702, C705, C706, C707: 10n; SMD-0805; Voltage 50V; Tolerance 10%
C703: 10u; SMD-0805; Voltage 10V; Tolerance 20%
C704: 100n; SMD-0805; Voltage 50V; Tolerance 10%
P701: CONN_2x1; CONN_SIL_2_1MM
R701, R707: 2k2; SMD-0805; Tolerance 1%
R702, R703, R705: 100; SMD-0805; Tolerance 1%
R704: 15k; SMD-0805; Tolerance 1%
R706: 10k7; SMD-0805; Tolerance 1%
SW701: SWITCH; SW_TACT_SMD
TP701: PIN; TP-2mm
U701: NCP308; IC-SOT23-6

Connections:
+1V0: R704.1; also elsewhere on the board
/GLB_RST: C702.1, R702.1, TP701.1; also elsewhere on the board
/XMOS_RST: C701.1, R703.1; also elsewhere on the board
/XSYS_RST: P701.1, R705.2, SW701.1; also elsewhere on the board
GNDD: C701.2, C702.2, C703.2, C704.2, C705.2, C706.2, C707.2, P701.2, R706.1, SW701.2, U701.2 (GND); also elsewhere on the board
unnamed: C706.1, U701.4 (CT)
unnamed: C707.1, R705.1, R707.1, U701.3 (~MR)
unnamed: R701.1, R702.2, R703.2, U701.1 (~RESET)
unnamed: R704.2, R706.2, U701.5 (SENSE)

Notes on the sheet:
Generate a global reset based on 1V0 voltage rail. Use NCP308SNADJT1G adjustable version. Supports external reset signal.
Voltage Monitor Reset
External reset input

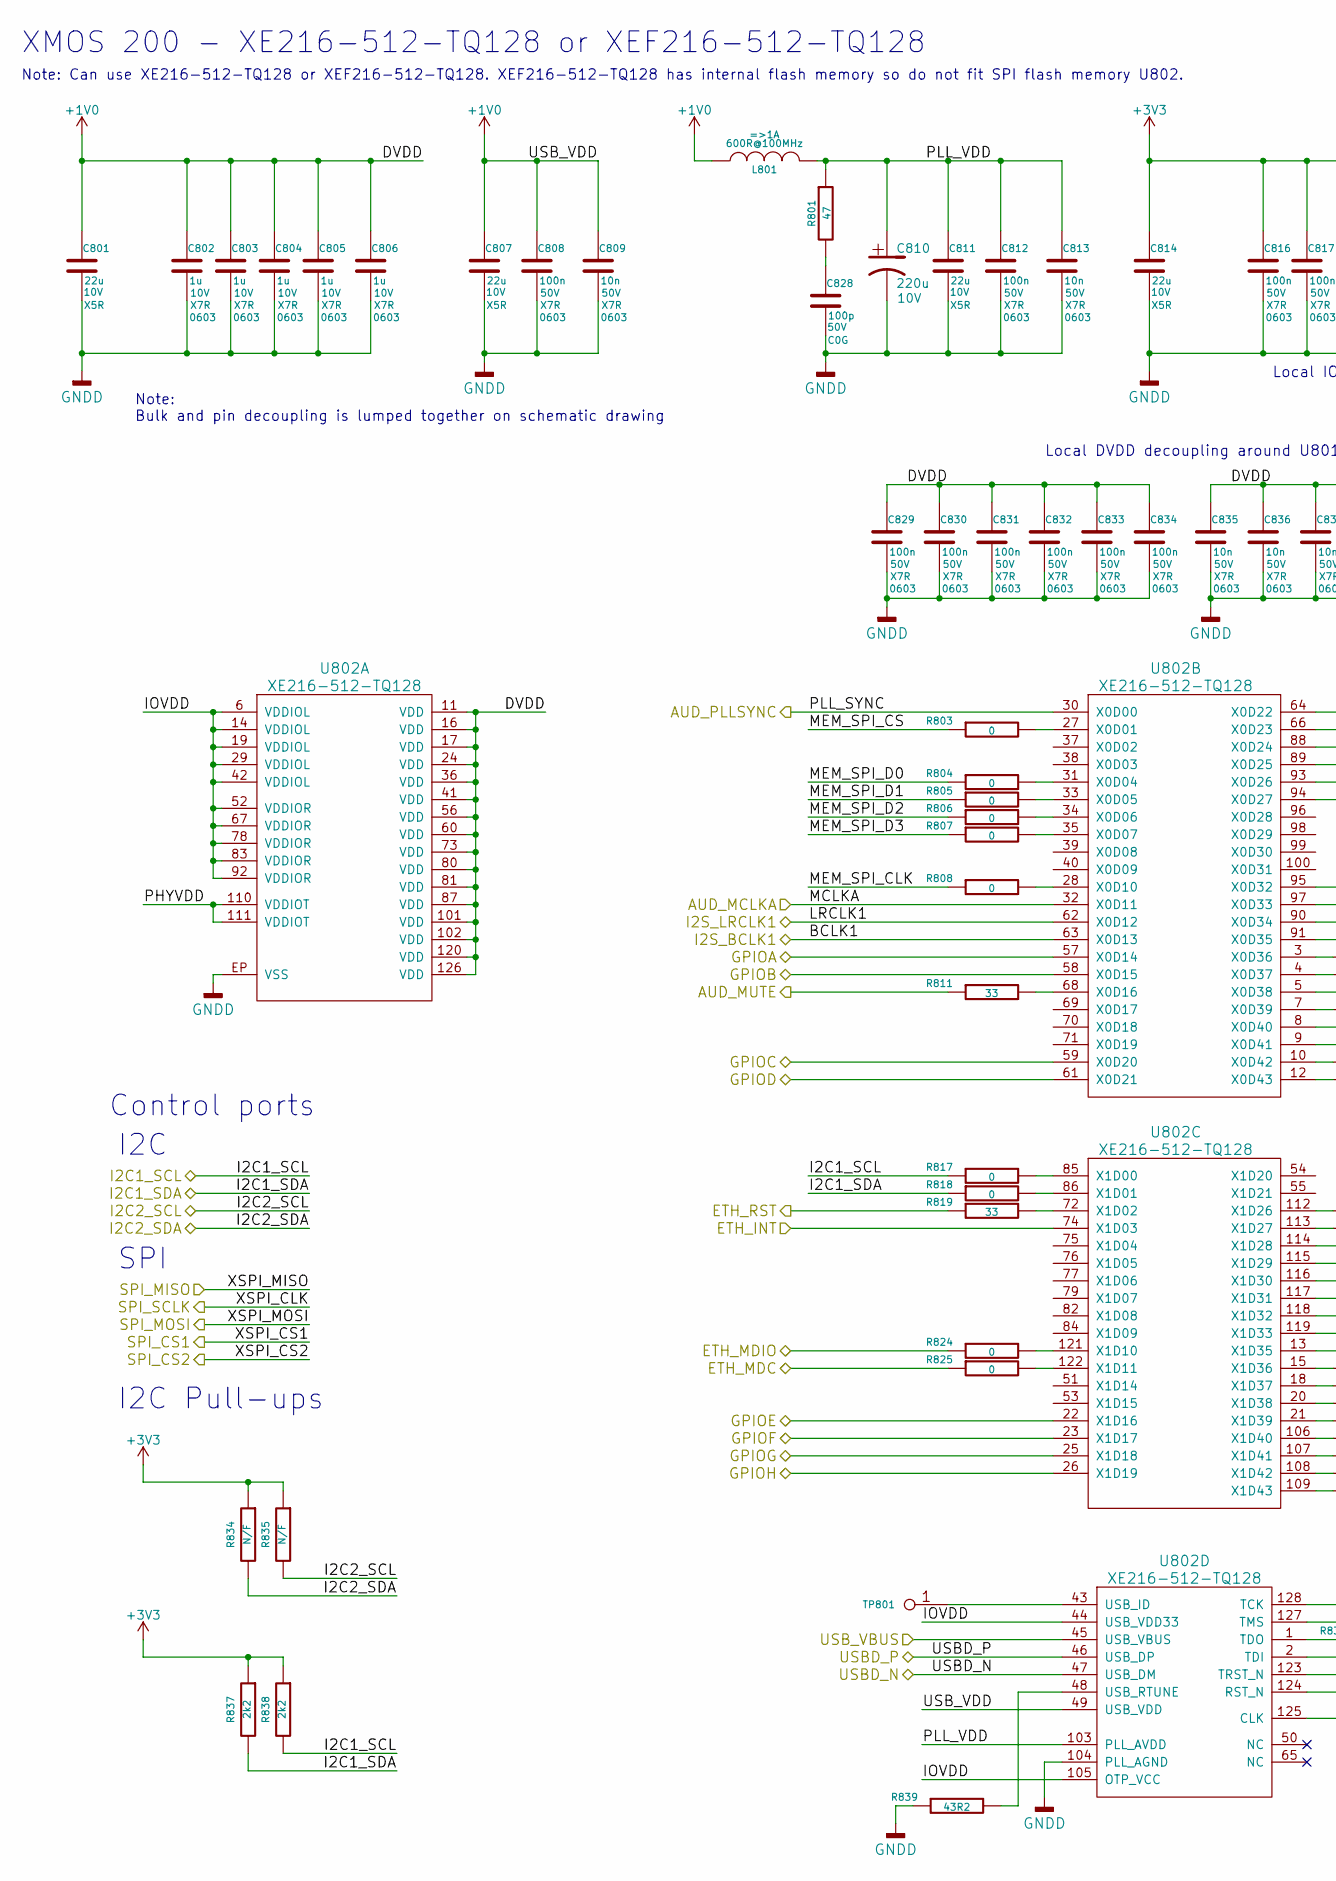
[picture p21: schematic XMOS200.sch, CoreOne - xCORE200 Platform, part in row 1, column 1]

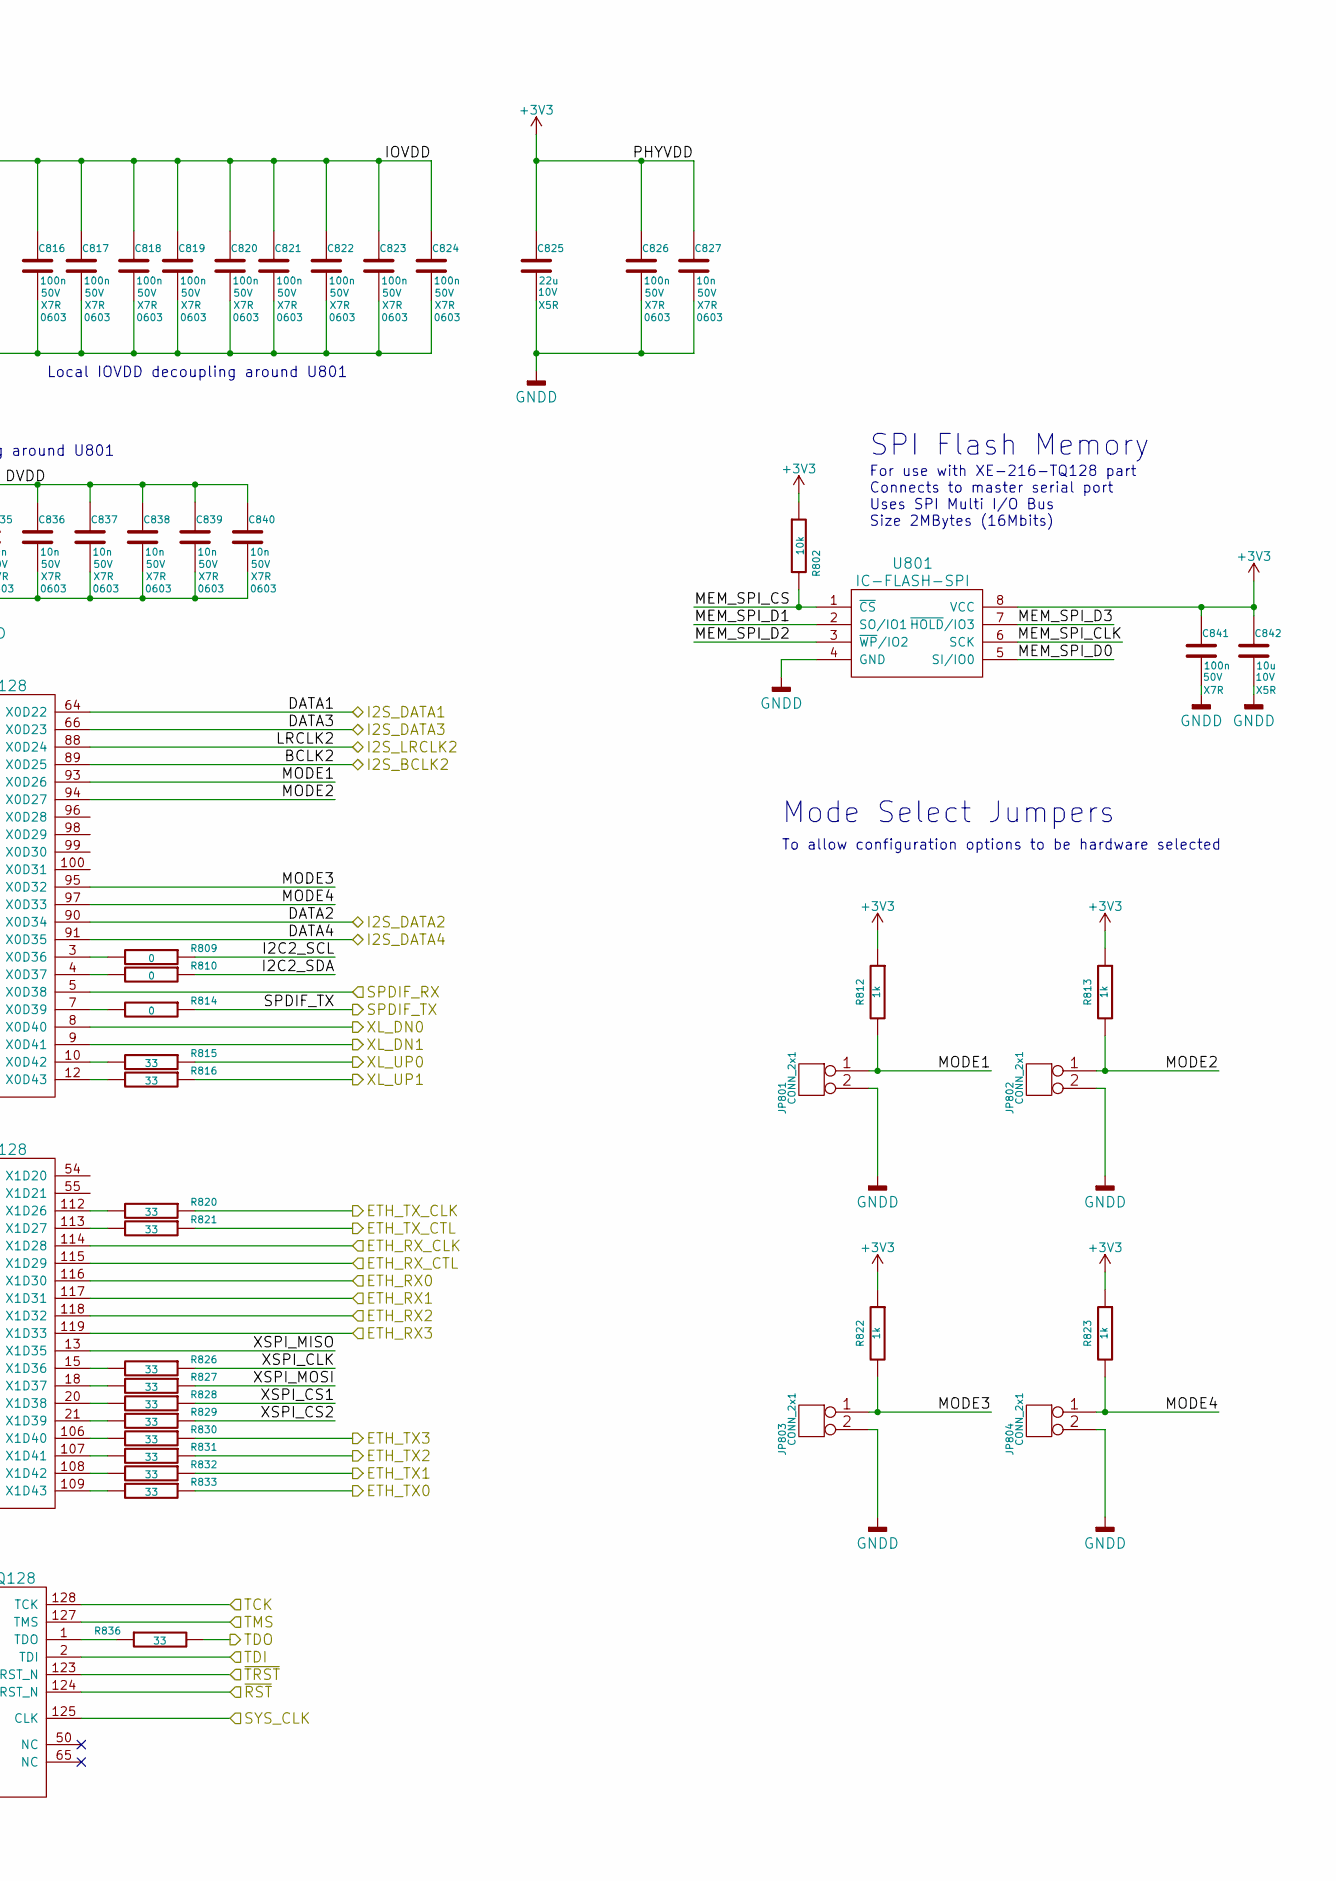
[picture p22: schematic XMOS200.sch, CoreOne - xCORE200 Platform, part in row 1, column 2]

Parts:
C801, C807, C811, C814, C825: 22u; SMD-0805; Voltage 10V; Tolerance 20%
C802, C803, C804, C805, C806: 1u; SMD-0603; Voltage 10V; Tolerance 10%
C808, C812, C816, C817, C818, C819, C820, C821, C822, C823, C824, C826, C829, C830, C831, C832, C833, C834: 100n; SMD-0603; Voltage 50V; Tolerance 10%
C809, C813, C827, C835, C836, C837, C838, C839, C840: 10n; SMD-0603; Voltage 50V; Tolerance 10%
C810: 220u; CAP-TH-D6.3mmP2.5mm; Voltage 10V
C828: 100p; SMD-0805; Voltage 50V; Tolerance 5%
C841: 100n; SMD-0805; Voltage 50V; Tolerance 10%
C842: 10u; SMD-0805; Voltage 10V; Tolerance 20%
JP801, JP802, JP803, JP804: CONN_2x1; CONN_SIL_2_1MM
L801: 600R@100MHz; SMD-0805
R801: 47; SMD-0805; Tolerance 1%
R802: 10k; SMD-0805; Tolerance 1%
R803, R804, R805, R806, R807, R808, R809, R810, R814, R817, R818, R824, R825: 0; SMD-0805; Tolerance 1%
R811, R815, R816, R819, R820, R821, R826, R827, R828, R829, R830, R831, R832, R833, R836: 33; SMD-0805; Tolerance 1%
R812, R813, R822, R823: 1k; SMD-0805; Tolerance 1%
R834, R835: N/F; SMD-0805; Tolerance 1%
R837, R838: 2k2; SMD-0805; Tolerance 1%
R839: 43R2; SMD-0805; Tolerance 1%
TP801: PIN; TP-1mm
U801: IC-FLASH-SPI; IC_SOIC_8
U802: XE216-512-TQ128; IC-TQ128-XMOS-HF

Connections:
+1V0: C801.1, C802.1, C803.1, C804.1, C805.1, C806.1, C807.1, C808.1, C809.1, C829.1, C830.1, C831.1, C832.1, C833.1, C834.1, C835.1, C836.1, C837.1, C838.1, C839.1, C840.1, L801.1, U802.11 (VDD), U802.16 (VDD), U802.17 (VDD), U802.24 (VDD), U802.36 (VDD), U802.41 (VDD), U802.49 (USB_VDD), U802.56 (VDD), U802.60 (VDD), U802.73 (VDD), U802.80 (VDD), U802.81 (VDD), U802.87 (VDD), U802.101 (VDD), U802.102 (VDD), U802.120 (VDD), U802.126 (VDD); also elsewhere on the board
/AUD_CLK1: U802.32 (X0D11); also elsewhere on the board
/AUD_MUTE: R811.1; also elsewhere on the board
/AUD_PLLSYNC: U802.30 (X0D00); also elsewhere on the board
/AUX_DIGI0: U802.57 (X0D14); also elsewhere on the board
/AUX_DIGI1: U802.58 (X0D15); also elsewhere on the board
/AUX_DIGI2: U802.59 (X0D20); also elsewhere on the board
/AUX_DIGI3: U802.61 (X0D21); also elsewhere on the board
/AUX_DIGI4: U802.22 (X1D16); also elsewhere on the board
/AUX_DIGI5: U802.23 (X1D17); also elsewhere on the board
/AUX_DIGI6: U802.25 (X1D18); also elsewhere on the board
/AUX_DIGI7: U802.26 (X1D19); also elsewhere on the board
/ETH_INT: U802.74 (X1D03); also elsewhere on the board
/ETH_MDC: R825.1; also elsewhere on the board
/ETH_MDIO: R824.1; also elsewhere on the board
/ETH_RST: R819.1; also elsewhere on the board
/ETH_RX0: U802.116 (X1D30); also elsewhere on the board
/ETH_RX1: U802.117 (X1D31); also elsewhere on the board
/ETH_RX2: U802.118 (X1D32); also elsewhere on the board
/ETH_RX3: U802.119 (X1D33); also elsewhere on the board
/ETH_RX_CLK: U802.114 (X1D28); also elsewhere on the board
/ETH_RX_CTL: U802.115 (X1D29); also elsewhere on the board
/ETH_TX0: R833.1; also elsewhere on the board
/ETH_TX1: R832.1; also elsewhere on the board
/ETH_TX2: R831.1; also elsewhere on the board
/ETH_TX3: R830.1; also elsewhere on the board
/ETH_TX_CLK: R820.1; also elsewhere on the board
/ETH_TX_CTL: R821.1; also elsewhere on the board
/I2C1_SCL: R817.1, R838.2; also elsewhere on the board
/I2C1_SDA: R818.1, R837.2; also elsewhere on the board
/I2C2_SCL: R810.1, R834.2; also elsewhere on the board
/I2C2_SDA: R809.1, R835.2; also elsewhere on the board
/I2S_BCLK1: U802.63 (X0D13); also elsewhere on the board
/I2S_BCLK2: U802.89 (X0D25); also elsewhere on the board
/I2S_D3: U802.66 (X0D23); also elsewhere on the board
/I2S_D4: U802.91 (X0D35); also elsewhere on the board
/I2S_LRCLK1: U802.62 (X0D12); also elsewhere on the board
/I2S_LRCLK2: U802.88 (X0D24); also elsewhere on the board
/I2S_SDATA1: U802.64 (X0D22); also elsewhere on the board
/I2S_SDATA2: U802.90 (X0D34); also elsewhere on the board
/SPDIF_RX: U802.5 (X0D38); also elsewhere on the board
/SPDIF_TX: R814.1; also elsewhere on the board
/SPI_CS1: R828.1; also elsewhere on the board
/SPI_CS2: R829.1; also elsewhere on the board
/SPI_MISO: U802.13 (X1D35); also elsewhere on the board
/SPI_MOSI: R827.1; also elsewhere on the board
/SPI_SCLK: R826.1; also elsewhere on the board
/SYS_CLK: U802.125 (CLK); also elsewhere on the board
/TCK: U802.128 (TCK); also elsewhere on the board
/TDI: U802.2 (TDI); also elsewhere on the board
/TDO: R836.2; also elsewhere on the board
/TMS: U802.127 (TMS); also elsewhere on the board
/USBD_N: U802.47 (USB_DM); also elsewhere on the board
/USBD_P: U802.46 (USB_DP); also elsewhere on the board
/USB_VBUS: U802.45 (USB_VBUS); also elsewhere on the board
/XL_DN0: U802.8 (X0D40); also elsewhere on the board
/XL_DN1: U802.9 (X0D41); also elsewhere on the board
/XL_UP0: R815.1; also elsewhere on the board
/XL_UP1: R816.1; also elsewhere on the board
/XMOS200/MEM_SPI_CLK: R808.1, U801.6 (SCK)
/XMOS200/MEM_SPI_CS: R802.2, R803.1, U801.1 (~CS)
/XMOS200/MEM_SPI_D0: R804.1, U801.5 (SI/IO0)
/XMOS200/MEM_SPI_D1: R805.1, U801.2 (SO/IO1)
/XMOS200/MEM_SPI_D2: R806.1, U801.3 (~WP~/IO2)
/XMOS200/MEM_SPI_D3: R807.1, U801.7 (~HOLD~/IO3)
/XMOS200/MODE1: JP801.1, R812.2, U802.93 (X0D26)
/XMOS200/MODE2: JP802.1, R813.2, U802.94 (X0D27)
/XMOS200/MODE3: JP803.1, R822.2, U802.95 (X0D32)
/XMOS200/MODE4: JP804.1, R823.2, U802.97 (X0D33)
/XMOS200/PLL_VDD: C810.1, C811.1, C812.1, C813.1, L801.2, R801.1, U802.103 (PLL_AVDD)
/XMOS200/~TRST~: U802.123 (TRST_N); also elsewhere on the board
/XMOS_RST: U802.124 (RST_N); also elsewhere on the board
GNDD: C801.2, C802.2, C803.2, C804.2, C805.2, C806.2, C807.2, C808.2, C809.2, C810.2, C811.2, C812.2, C813.2, C814.2, C816.2, C817.2, C818.2, C819.2, C820.2, C821.2, C822.2, C823.2, C824.2, C825.2, C826.2, C827.2, C828.2, C829.2, C830.2, C831.2, C832.2, C833.2, C834.2, C835.2, C836.2, C837.2, C838.2, C839.2, C840.2, C841.2, C842.2, JP801.2, JP802.2, JP803.2, JP804.2, R839.1, U801.4 (GND), U802.104 (PLL_AGND), U802.EP (VSS); also elsewhere on the board
unnamed: C828.1, R801.2
unnamed: R803.2, U802.27 (X0D01)
unnamed: R804.2, U802.31 (X0D04)
unnamed: R805.2, U802.33 (X0D05)
unnamed: R806.2, U802.34 (X0D06)
unnamed: R807.2, U802.35 (X0D07)
unnamed: R808.2, U802.28 (X0D10)
unnamed: R809.2, U802.3 (X0D36)
unnamed: R810.2, U802.4 (X0D37)
unnamed: R811.2, U802.68 (X0D16)
unnamed: R814.2, U802.7 (X0D39)
unnamed: R815.2, U802.10 (X0D42)
unnamed: R816.2, U802.12 (X0D43)
unnamed: R817.2, U802.85 (X1D00)
unnamed: R818.2, U802.86 (X1D01)
unnamed: R819.2, U802.72 (X1D02)
unnamed: R820.2, U802.112 (X1D26)
unnamed: R821.2, U802.113 (X1D27)
unnamed: R824.2, U802.121 (X1D10)
unnamed: R825.2, U802.122 (X1D11)
unnamed: R826.2, U802.15 (X1D36)
unnamed: R827.2, U802.18 (X1D37)
unnamed: R828.2, U802.20 (X1D38)
unnamed: R829.2, U802.21 (X1D39)
unnamed: R830.2, U802.106 (X1D40)
unnamed: R831.2, U802.107 (X1D41)
unnamed: R832.2, U802.108 (X1D42)
unnamed: R833.2, U802.109 (X1D43)
unnamed: R836.1, U802.1 (TDO)
unnamed: R839.2, U802.48 (USB_RTUNE)
unnamed: TP801.1, U802.43 (USB_ID)

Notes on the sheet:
Mode Select Jumpers
To allow configuration options to be hardware selected
I2C Pull-ups
I2C
Control ports
SPI
XMOS 200 - XE216-512-TQ128 or XEF216-512-TQ128
For use with XE-216-TQ128 part Connects to master serial port Uses SPI Multi I/O Bus Size 2MBytes (16Mbits)
SPI Flash Memory
Local DVDD decoupling around U801
Local IOVDD decoupling around U801
Note: Bulk and pin decoupling is lumped together on schematic drawing
Note: Can use XE216-512-TQ128 or XEF216-512-TQ128. XEF216-512-TQ128 has internal flash memory so do not fit SPI flash memory U802.

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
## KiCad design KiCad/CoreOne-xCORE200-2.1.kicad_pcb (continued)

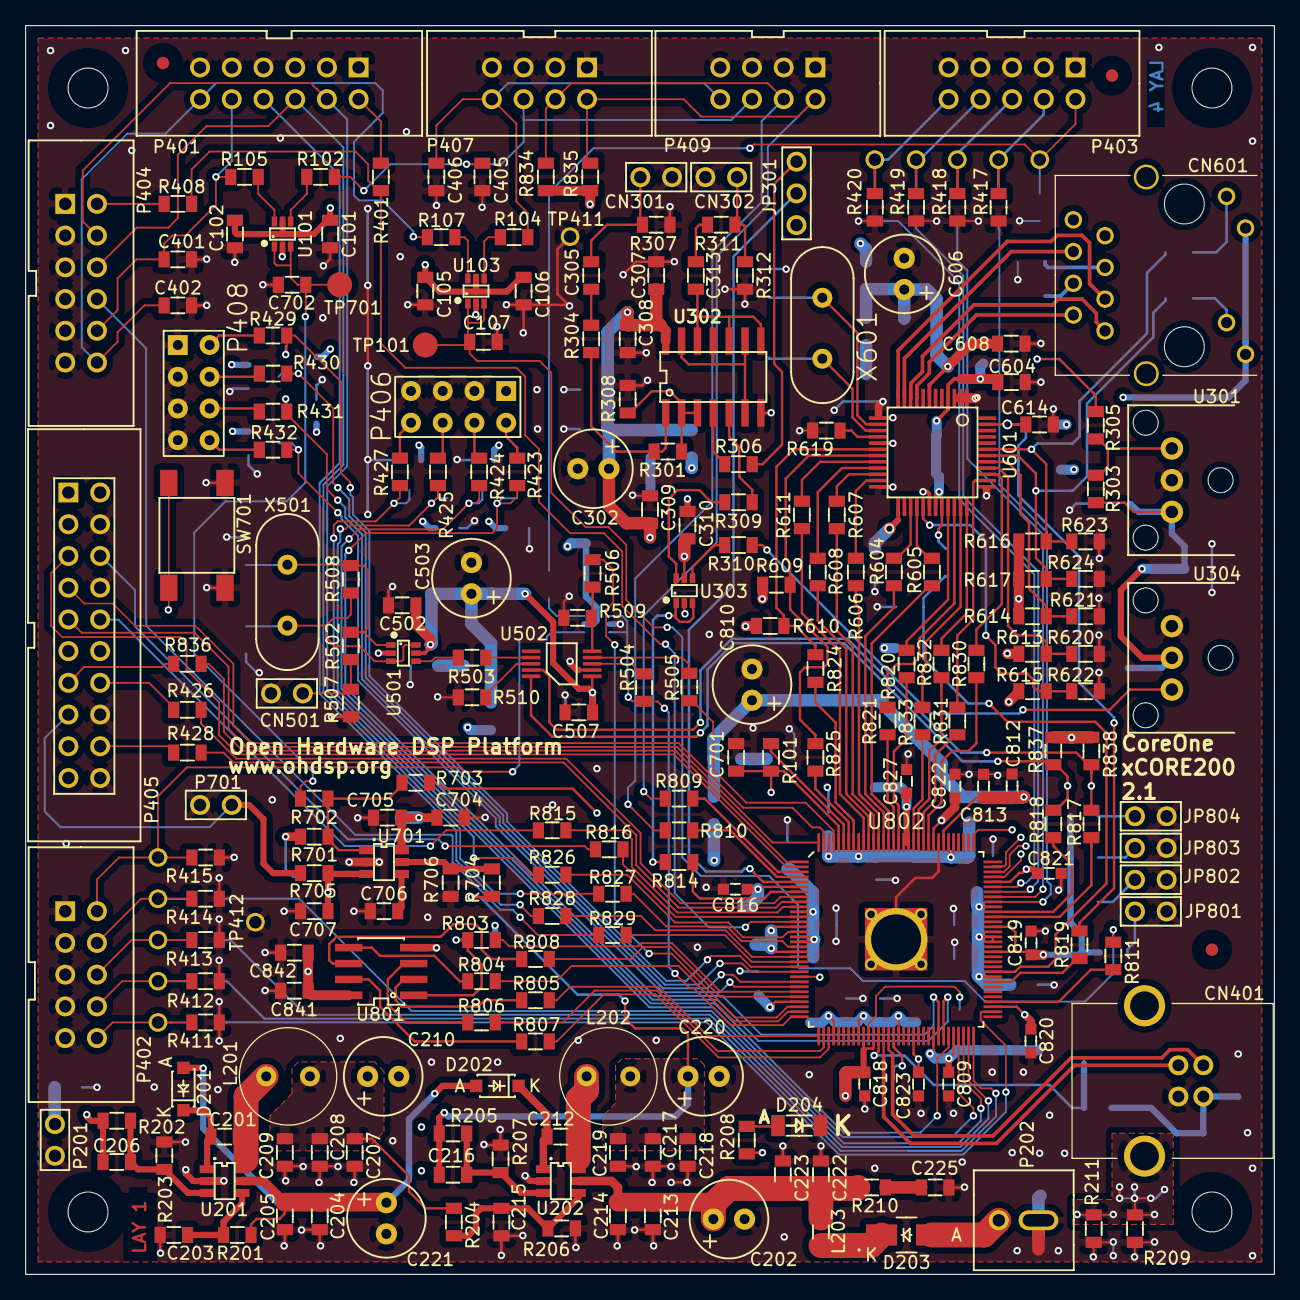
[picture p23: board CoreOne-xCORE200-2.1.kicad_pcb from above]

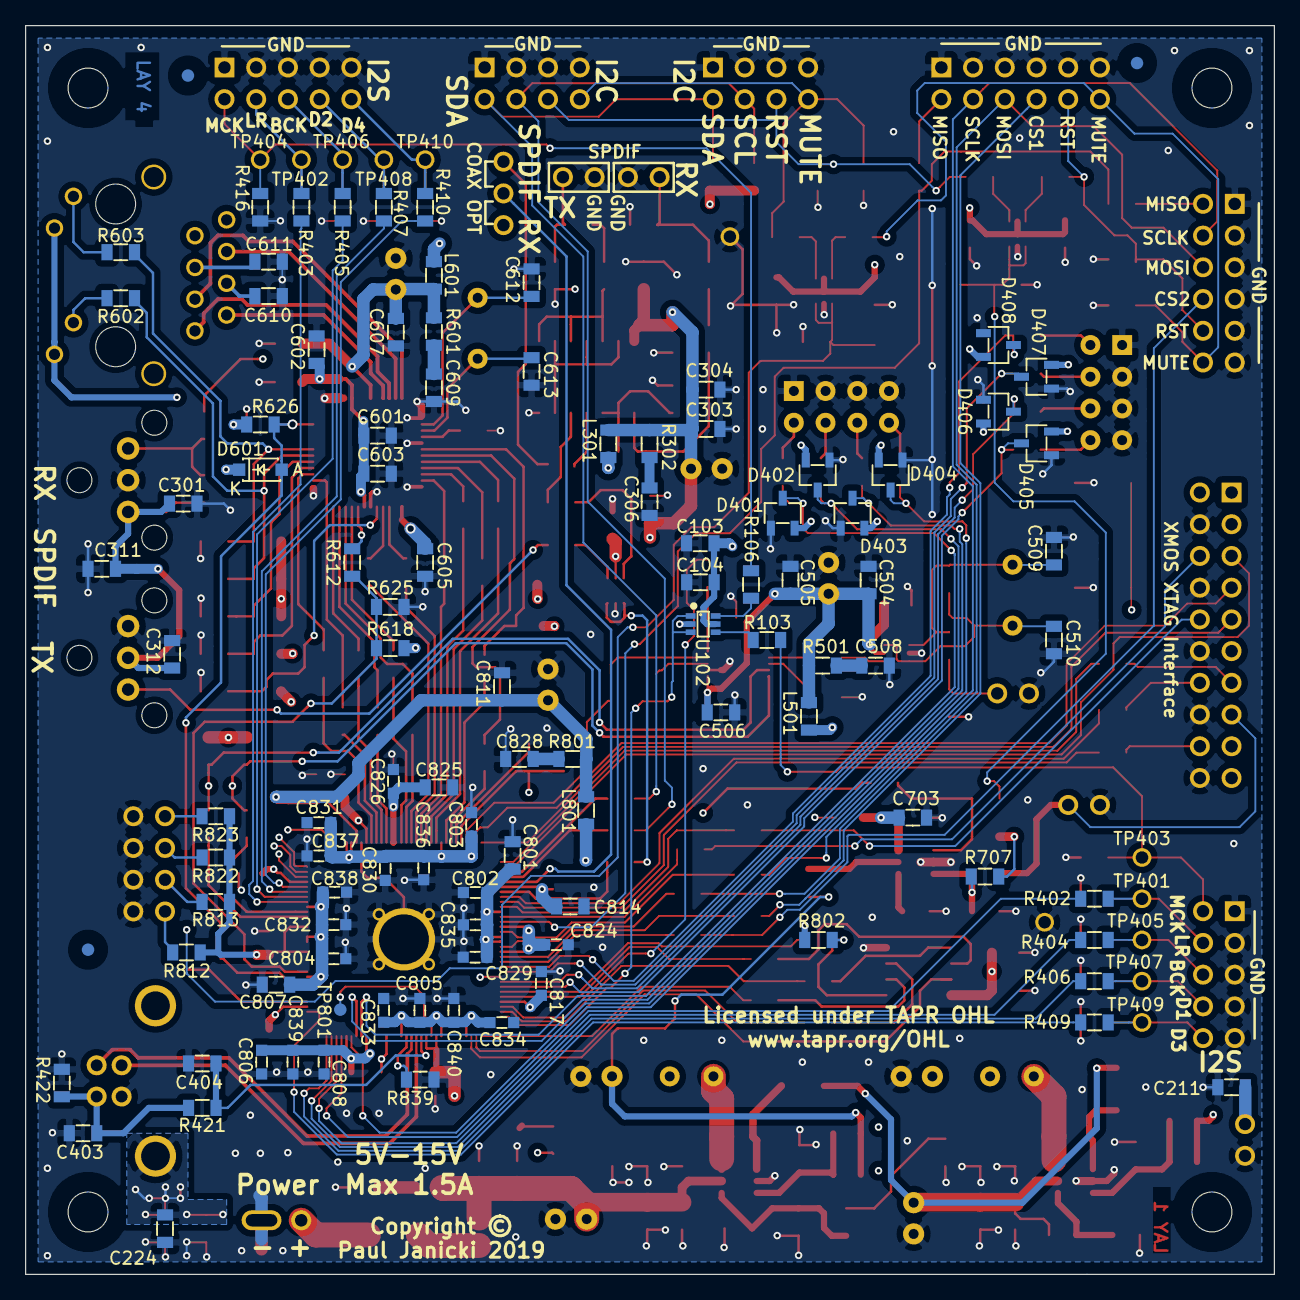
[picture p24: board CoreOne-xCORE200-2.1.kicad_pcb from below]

Board: 4 copper layers, 100.0 x 100.0 mm, 351 parts (114 on the bottom side), 213 nets.

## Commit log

2019-04-02 CoreOne-xCORE200-2.0
    CoreOne-xCORE200-2.0
    [Clock-CS2200.sch, Connectors.sch, CoreOne-xCORE200-2.0-Bill-of-Materials.csv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]
2019-04-04 CoreOne-xCORE200-2.1
    CoreOne-xCORE200-2.1
    Improved grounding on power connector
    [Clock-CS2200.sch, Connectors.sch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]
2019-04-04 Revert "CoreOne-xCORE200-2.0"
    This reverts commit ef9318669a1c13780c7fcf0a8911ea6c14e73c30.
    [CoreOne-xCORE200-2.0-Bill-of-Materials.csv, CoreOne-xCORE200-2.0-Bill-of-Materials.ods, CoreOne-xCORE200-2.1-Bill-of-Materials.ods]
2019-04-04 CoreOne-xCORE200-2.1
    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
    [CoreOne-xCORE200-2.0-Bill-of-Materials.ods, CoreOne-xCORE200-2.1-Bill-of-Materials.csv, CoreOne-xCORE200-2.1-Bill-of-Materials.ods]

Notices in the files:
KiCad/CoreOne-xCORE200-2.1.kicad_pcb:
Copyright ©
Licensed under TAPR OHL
